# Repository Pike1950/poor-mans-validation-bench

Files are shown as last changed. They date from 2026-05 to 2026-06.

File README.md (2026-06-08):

# Poor Man's Validation Bench

A modular SCPI instrument platform that mirrors NI PXIe rack-and-module test architecture at hobbyist budget. A Raspberry Pi 5 acts as the orchestration head running PyVISA, pytest, InfluxDB, and Grafana. Hot-swappable instrument modules attach over USB or Ethernet and present as independent SCPI-addressable instruments. Every module is also exposed through a Model Context Protocol (MCP) tool surface for agent-orchestrated bench sessions.

## Documentation

### Canonical reference

- **[System Design Document](https://pike1950.github.io/poor-mans-validation-bench/docs/system-design/System_Design_Document.html)** — full v1.0 SDD covering architecture, module catalog, specifications, software stack, build phases, and verification strategy. Rendered via GitHub Pages.

### Orchestration layer

- **[Phase 0 Orchestration Layer Setup](https://pike1950.github.io/poor-mans-validation-bench/docs/setup/Phase_0_Orchestration_Setup.html)** — architecture overview of the two-plane VISA/SCPI + MCP software stack (PyVISA, pytest, InfluxDB 2.x, Grafana, Jinja2 reports, MCP gateway), the `pmvb` Python package layout, and the step-by-step bring-up cookbook from a blank SD card through the Phase 0 verification milestone. Covers Pi 5 OS install, NVMe boot migration, Python project bootstrap, InfluxDB + Grafana install with token management, Pico SDK + USB-TMC stub firmware, udev rules, hot-plug verification, and the closing end-to-end pytest.

### Chassis design

- **[Chassis Architecture and Power Distribution](https://pike1950.github.io/poor-mans-validation-bench/docs/chassis/Chassis_Architecture_and_Power_Distribution.html)** — open-frame acrylic blade-style chassis (laser-cut from SendCutSend, 435 × 238 × 92 mm) housing the Silverstone TX300 PSU as an analog-rail backbone, the GeeekPi D-1188 ATX breakout, the Sabrent HB-BU10 USB 3.0 hub, and 14 module slots at 22.5 mm pitch. Covers mechanical architecture, electrical architecture (4-rail back-wall harness with Phoenix MC 1,5/4 module interconnect, per-rail fuse panel, banana-jack diagnostic test points), USB-TMC backplane, BOM with Digi-Key and Amazon cross-references, bring-up procedure, and safety protocols.

### Per-module design

- **[Module 1E: Function Generator / AWG](https://pike1950.github.io/poor-mans-validation-bench/docs/modules/Module_1E_Design_Document.html)** — theory of operation, functional block diagram, Pico-to-DAC-to-op-amp pin assignments, four sample applications (single-tone sine, swept-sine THD, multitone IMD, white noise), calibration procedure, bring-up checklist, and BOM with Mouser and Digi-Key cross-references.

## Module Catalog

Every module is built on a Pico 2 W bridge presenting as a USB-TMC instrument over the chassis powered USB hub. Tier 2 modules add a Tang Primer 25K FPGA the Pico masters over SPI. Tier 3 modules (deferred) replace the Tang Primer 25K with a larger FPGA platform and add a Pi Zero 2 W streaming sidecar for sustained-capture data paths beyond USB-TMC's 12 Mbps.

| ID | Tier | Function | Status |
|----|---|---|---|
| 1A | 1 | Digital I/O Controller | Planned (v1.0) |
| 1B | 1 | Voltage Measurement Unit | Planned (v1.0) |
| 1C | 1 | USB HID Protocol Analyzer | Planned (v1.0) |
| 1D | 1 | Source-Measure Unit Lite | Planned (v1.0) |
| 1E | 1 | Function Generator / AWG | Planned (v1.0) |
| 1F | 1 | High-Voltage Differential Probe | Planned (v1.1) |
| 1G | 1 | IR Capture and Transmit | Planned (v1.1) |
| 1H | 1 | Multi-Function DMM | Planned (v1.0) |
| 2A | 2 | Logic Analyzer | Planned (v1.0) |
| 2B | 2 | Protocol Exerciser / Analyzer | Planned (v1.0) |
| 2C | 2 | Frequency Counter | Planned (v1.0) |
| 2D | 2 | Ethernet MAC and Network Analyzer | Planned (v1.0) |
| 2E | 2 | Mixed-Signal Digitizer / Oscilloscope | Planned (v1.0) |
| 3A | 3 | USB 2.0 Protocol Analyzer | Deferred |
| 3B | 3 | HDMI Sideband Analyzer | Deferred |
| 3C | 3 | USB-C CC Analyzer | Deferred |

## Architecture at a Glance

Two control planes per module: a VISA/SCPI plane for headless test sequencing (pytest, vendor-portable, deterministic) and an MCP plane that exposes the same instrument surface as LLM-callable tools for agent-orchestrated bench sessions. Both planes consume the same per-module YAML command schema; firmware parsers and PyVISA-sim simulation backends are generated mechanically from the YAML.

Every module is built around a Pico 2 W running the SCPI parser in bare-metal C and presenting as a USB-TMC instrument. Tier 1 modules add an analog or digital front end appropriate to the function. Tier 2 modules add a Sipeed Tang Primer 25K FPGA where the instrument logic lives; the Pico bridges to the FPGA over SPI at approximately 30 MHz. Tier 3 modules (deferred) replace the Tang Primer 25K with a larger FPGA (Tang Mega 138K Pro or Alinx AX7325B) for high-speed interface analysis and add a Pi Zero 2 W streaming sidecar for sustained-capture data paths beyond USB-TMC's 12 Mbps. Persistent state for Tier 1 and Tier 2 modules lives in the Pico's onboard 4 MB flash; bench-level admin services run on the Pi 5 orchestration head.

See section 4 of the [System Design Document](https://pike1950.github.io/poor-mans-validation-bench/docs/system-design/System_Design_Document.html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) for the full architecture diagram.

## Status

Phase-by-phase build progress. Top-level structure mirrors [SDD section 13](https://pike1950.github.io/poor-mans-validation-bench/docs/system-design/System_Design_Document.html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). Items are sized for single-session work units. Per-module work follows a standard template: design doc → BOM → PCB → assembly → firmware → bring-up → calibration → service. Status legend: `[ ]` not started · `[~]` in progress · `[x]` complete · `[!]` blocked.

### Phase 0 — Orchestration + Chassis Power

Phase 0 brings up the orchestration head and chassis power subsystem to the point where a simulator-backed end-to-end test exercises the full SCPI → InfluxDB → Grafana → report pipeline.

**Architectural decisions (settled)**

- [x] System Design Document v1.0 published
- [x] Chassis LAN switch dropped from v1.0 baseline (moved to Phase 4)
- [x] TFX (TX300) is analog-rail backbone, not chassis-wide power
- [x] Pi 5, Sabrent hub, Picos run from independent external supplies
- [x] Pi 5 ↔ USB hub link is USB 3.0
- [x] Chassis envelope: 435 × 238 × 92 mm in 3 mm cast acrylic from SendCutSend
- [x] Chassis topology v1.0: open-frame card cage (4 panels: floor, bottom groove plate, top groove plate, ceiling) held by 4 M3 corner standoffs. Side walls + rear wall + front panel deferred to v1.1 pending thermal review.
- [x] Module form factor v10 (JLCPCB-FDM-compliant): 16.3 × 125 × 86 mm outer, 6 mm shells, 2 mm right wall, 1.5 × 3 × 125 mm rail lips at top-right and bottom-right edges, 14.3 × 125 × 68 mm cavity
- [x] Chassis groove: 2 mm wide × 3 mm deep × 125 mm long, at 22.5 mm slot pitch starting at x = 100 mm (leftmost 10 mm reserved for M3 corner standoff clearance + 86 mm TX300 zone + 4 mm air gap). 0.5 mm sliding clearance.
- [x] Module fabrication path: FDM PLA via US service for prototype (Baysinger's AM); FDM PETG via JLCPCB for the production batch of 14 once v10 fit validates
- [x] GeeekPi D-1188 mounted to chassis ceiling via 4× M2.5 × 5 mm standoffs (rotated 90° so terminal blocks face chassis front, status LEDs face rear). Mounting holes at (110.1, 161.6), (162.9, 161.6), (110.1, 225.4), (162.9, 225.4) on both ceiling and top groove plate
- [x] Sabrent HB-BU10 actual dimensions verified: 144.8 × 48.3 × 23.9 mm. Positioned at X = 102.6..247.4, Y = 175.4..223.7, Z = 6..29.9 (rear-center on chassis floor)
- [x] Back-wall harness taps: Wago 221-413 lever-nut connectors for v1.0 (one per rail per module). Custom 4-rail distribution PCB deferred to v1.1+ once layout is verified
- [x] Module Design Document Schema authored (local tooling)

**Chassis sourcing**

Detailed rationale (gauge sizing, standoff stacking, fastener stack-up, Wago vs PCB tradeoff) lives in the [chassis architecture doc](https://pike1950.github.io/poor-mans-validation-bench/docs/chassis/Chassis_Architecture_and_Power_Distribution.html). This tracker is part + source + qty + price only.

- [x] GeeekPi D-1188 ATX breakout — Amazon B08MC389FQ ($13)
- [x] Sabrent HB-BU10 USB 3.0 hub — Amazon B0797NZFYP ($47)
- [x] Phoenix MC 1,5/4 connector pairs ×2 — Digi-Key 277-1208-ND + 277-1163-ND ($11.40)
- [x] Eaton BK/HTB-22M-R fuse holders ×3 + Bel BK1/GMC cartridges ×2 each (5 A / 3 A / 500 mA, in-service + spare) — Digi-Key 283-3041-ND + 283-BK1/GMC-{5,3,500}-R-ND ($28.79)
- Pomona 3760 banana jacks ×4 — *deferred to v1.1 diagnostic strip*; open-frame chassis gives direct access to fuse-panel terminals for DMM spot-checks
- [x] 12 AWG silicone wire kit, 6 colors × 5 ft — Fermerry, Amazon B089CJ65SC ($20.29)
- [x] 14 AWG silicone wire kit, 6 colors × 10 ft — Fermerry, Amazon ($20.96)
- [x] M3 standoff/screw/nut kit, 320 pc — Csdtylh, Amazon B06Y5TJXY1 ($14.98)
- [x] M2.5 standoff/screw/nut kit, 160 pc — HVAZI, Amazon B01L06CUJG ($11.99)
- [x] Blue 243 threadlocker, 50 mL — ESKONKE, Amazon B0CHM5QS3N ($9.99)
- [x] Wago 221-413 lever-nuts ×10 — Digi-Key 2946-221-413-ND ($6.45)
- [~] USB-A to Micro-USB cables (module Pico to hub) — 11 of 14 on hand (5 prior + 6 from Amazon, $10.81). 11 covers Phase 0 + early Phase 1; 3 more needed for full 14-slot population
- [x] 22 AWG signal wire on hand
- [x] LEDs for diagnostic strip on hand
- [x] Heat-shrink tubing on hand (ElectroBits)
- [x] Silverstone SST-TX300 TFX PSU — Amazon ($99.99), on hand

**Chassis fabrication + assembly**

Prototype-first iterative build: order chassis acrylic + one PLA module, slide-test the v10 lip-and-groove fit, then commit the JLCPCB batch order for 13 more modules and proceed with full assembly + harness. Module 1E is the first module to fully populate; Pi 5 software-stack work runs in parallel.

*Design tooling and fabrication files (complete)*

- [x] Tinkercad reference design + parametric DXF/STL generator (`tools/fabrication/generate_prototype_v10.py`, ezdxf + trimesh) producing `panel_solid_plate.dxf`, `panel_groove_plate.dxf`, `module_body_v10.stl`, `chassis_v10.stl`, `chassis_v10_assembled.stl`, `chassis_assembly_exploded.{stl,png}`

*Orders placed*

- [x] v10 prototype module — Baysinger's AM, $24.77, ETA May 14-19
- [x] Chassis acrylic — SendCutSend, $142.57
- [x] Amazon order (hardware + wire + threadlocker), $78.21, ETA May 12
- [x] Digi-Key order (Phoenix + fuse panel + Wago), $62.19, placed 2026-05-10

*Receive + slide-fit validation*

- [x] Receive prototype module + chassis panels (all parts arrived 2026-05-12 onward)
- [x] Slide-fit test: module blade engages the lip-and-groove cleanly at every slot, 0.5 mm clearance good (verified 2026-05-12; droop is a separate panel-stiffness issue, see build notes)
- [ ] Order JLCPCB batch of 14 module bodies in PETG (~$84) — unblocked by slide-fit pass

*Frame + component install*

- [x] Build 4× M3 corner standoff stacks
- [x] Acrylic frame stack assembly (standoffs + bonded panels)
- [x] Install TX300 PSU
- [~] Install GeeekPi (ceiling mount) + Sabrent hub — deferred a while; GeeekPi mount pending hole-pattern fix (see build notes)
- [ ] Run 24-pin ATX cable TX300 → GeeekPi
- [ ] Build per-rail fuse panel + wire to GeeekPi outputs

*Harness + module shakedown*

- [ ] Build 4-wire back-wall harness (~330 mm × 14 AWG, color-coded). Tap slot 1 only for Module 1E shakedown via 4× Wago 221-413 (one per rail)
- [ ] Single-slot shakedown: install Module 1E, verify Phoenix mate + USB cable run + harness tap
- [ ] On pass: add Wago taps at remaining 13 slots (52 more Wagos, total 56)
- [ ] Install front-panel diagnostic strip (×4 banana jacks + ×3 LED indicators) on a small acrylic strip on the chassis floor

*Deferred to v1.1:* chassis side walls, rear wall, front panel, ventilation geometry, module-specific faceplate cutouts, custom 4-rail distribution PCB. Walls + vents must be co-designed because closing the chassis re-introduces TX300 cooling constraints.

*v1.0 prototype build notes (iteration 1, 2026-05-12)*

- **GeeekPi mounting holes mis-sized.** Acrylic was cut for a ~52.8 × 63.8 mm M2.5 pattern; the real GeeekPi is 87.4 × 68.4 mm with a 58.6 × 78.1 mm hole pattern (PCB was modeled ~17 mm too short, ~10 mm too narrow). *Resolution:* hand-drill correct holes on the prototype panel, or VHB-tape the GeeekPi (mount is non-structural). *Deferred:* the on-disk `generate_prototype_v10.py` is a stale 6-panel version with no M3/M2.5 hole logic — the generator that produced the real `panel_solid_plate.dxf` / `panel_groove_plate.dxf` was never committed. Fixing the GeeekPi pattern needs a full generator reconstruction (with a placement re-derivation, since the larger GeeekPi would otherwise crowd the chassis back edge), to be done before any v1.1 panel re-order.
- **Long acrylic panels droop at mid-span.** 435 mm of unsupported 3 mm cast acrylic sags under self-weight. *Resolution (applied):* bonded ceiling + top groove plate into a 6 mm laminate with acrylic cement — large improvement, slight residual droop accepted for the prototype. v1.1 side walls will provide long-edge support and largely eliminate it.
- **Harness routing tighter than CAD suggested.** Physical wire bend radii make the Wago back-wall harness cramped. *Direction:* custom 4-rail distribution PCB (v1.1 §9.3) is now the leading power-backplane approach, gated on the Module 1E PCB design locking the module-to-backplane connector interface spec.

**Chassis bring-up**

- [ ] Visual + continuity tests, mains disconnected
- [ ] Mains-only AC test (TX300 in standby)
- [ ] DC at no load (rail voltages at fuse outputs, front-panel LEDs, banana-jack test points all verified)
- [ ] Back-wall harness rail voltages verified at every Phoenix plug position

**Pi 5 hardware**

- [x] Pi 5 16 GB price verified at Microcenter ($305)
- [x] Pi 5 16 GB + 27 W USB-C charger + active cooler on hand
- [x] microSD (32 GB) + M.2 HAT+ + 512 GB NVMe SSD on hand
- [x] Pi 5 assembled (heatsink + M.2 HAT+ + NVMe)

**Pi 5 software stack**

- [x] Raspberry Pi OS Full 64-bit install + headless config (Wi-Fi, SSH key-only auth, Raspberry Pi Connect enabled)
- [x] Boot migration to NVMe SSD (NVMe-first via EEPROM `BOOT_ORDER`, SD card retained as fallback)
- [x] Bootstrap Python project (`pyproject.toml` + `pmvb/` package + `.venv` on Pi)
- [x] InfluxDB 2.x install + service + `pmvb` org + `measurements` bucket + SDD §10.2 tag schema (Flux)
- [x] Grafana 10+ install + InfluxDB datasource (Pi 5 reference build runs Grafana 13)
- [x] Jinja2 + Matplotlib report template skeleton (`pmvb/reports/`)
- [x] MCP gateway scaffolding (`pmvb/mcp_gateway/server.py`, FastMCP + `anthropic` SDK)
- [x] PyVISA-sim placeholder schema (`sim/placeholder/responses.yaml`) for Phase 0 sim path
- [x] pytest fixtures (`pmvb/fixtures.py`, `run_id` / `dut` / `record`) per SDD §10.3
- [x] InfluxDB I/O helpers (`pmvb/influx.py`) enforcing the SDD §10.2 tag taxonomy

**Pico firmware bring-up (hot-plug verification)**

Pulled forward from Phase 1: a throwaway probe firmware on every Pico so the Phase 0 verification can exercise the real USB-TMC path, not just the simulator. The stub is not the eventual per-module SCPI firmware; it just enumerates and answers `*IDN?` so we can prove the hot-plug-by-serial architecture works.

- [x] Pico SDK + TinyUSB cross-compile environment on the Pi 5 (`arm-none-eabi-gcc`, `pico-sdk` at `/opt/pico-sdk`, `PICO_SDK_PATH` set; `hello_usb` cross-compile verified)
- [x] Minimal USB-TMC stub firmware at `firmware/pmvb_usbtmc_stub/`: responds to `*IDN?` with chip-ID-derived serial number
- [x] Flash all 5 Picos with the stub `.uf2`
- [x] udev rules: plugdev access to USB-TMC class devices + stable `/dev/usbtmc-by-serial/{chip_id}` symlinks + suppress BOOTSEL automount (`tools/udev/99-pmvb-usbtmc.rules`)
- [x] Hot-plug verification: same Pico across different Sabrent hub ports preserves serial-based identity in pyvisa-py enumeration

**Phase 0 verification milestone (per SDD §13.1)**

- [x] Pi 5 boots from NVMe, reaches bench network, Sabrent hub enumerates as USB 3.0
- [x] End-to-end pytest: real Pico over pyvisa-py USB-TMC + pyvisa-sim placeholder, both write to InfluxDB tagged appropriately, Grafana panel renders both, Jinja2 report queries InfluxDB and outputs HTML+PDF referencing both records (verified 2026-05-12 by `tests/test_phase0_e2e.py::test_phase0_milestone`)
- [x] Hot-plug-by-serial verified across at least 3 port-swap permutations (verified 2026-05-12 by `tools/hot_plug_verify.py` across 4 distinct hub arrangements)

**Phase 0 documentation**

- [x] Chassis Architecture and Power Distribution doc
- [x] SDD §11.5 Power Architecture
- [x] Phase 0 Orchestration Layer Setup doc (rewritten with architecture + bring-up sections, replaces the stale 2024-era version) at `docs/setup/Phase_0_Orchestration_Setup.{md,html}`

### Phase 1 — Tier 1 Core (1A, 1B, 1D, 1E)

Four foundational Tier 1 modules using the chassis from Phase 0. Each follows the per-module template.

- **Module 1A — Digital I/O Controller**:
  - [ ] Design doc
  - [ ] Block diagram
  - [ ] BOM verified at Digi-Key + Mouser
  - [ ] BOM ordered
  - [ ] PCB design (KiCad: Pico + level shifters + I/O protection)
  - [ ] PCB fab + assembly
  - [ ] Firmware (SCPI YAML for read/write/pulse, configurable per-pin direction)
  - [ ] Bring-up
  - [ ] Module enters service
- **Module 1B — Voltage Measurement Unit** (front-end: ADS1115 + instrumentation amp on ±12 V rails):
  - [ ] Design doc
  - [ ] Functional figures (system context + front-end schematic)
  - [ ] BOM verified at Digi-Key + Mouser
  - [ ] BOM ordered
  - [ ] PCB design (KiCad: ADS1115 + instrumentation amp + ±12 V analog supplies)
  - [ ] PCB fab + assembly
  - [ ] Firmware (SCPI YAML for voltage measurement, range selection, averaging)
  - [ ] Bring-up
  - [ ] Calibration (offset, gain across ranges)
  - [ ] Module enters service
- **Module 1D — Source-Measure Unit Lite** (front-end: DAC + force/sense op-amp loop on ±12 V rails):
  - [ ] Design doc
  - [ ] Functional figures
  - [ ] BOM verified at Digi-Key + Mouser
  - [ ] BOM ordered
  - [ ] PCB design (KiCad: 12-bit DAC + force/sense op-amp loop + ±12 V analog supplies)
  - [ ] PCB fab + assembly
  - [ ] Firmware (SCPI YAML for V-source/I-measure, sweep, IV-curve)
  - [ ] Bring-up
  - [ ] Calibration (V-source, I-measure across ranges)
  - [ ] Module enters service
- **Module 1E — Function Generator / AWG**:
  - [x] Design doc v1.1
  - [x] Functional figures (system context, AD9742 datasheet embed, typical app)
  - [x] BOM verified at Digi-Key + Microcenter ($53)
  - [ ] BOM ordered
  - [~] PCB design (KiCad: AD9742 + AD8056 + reconstruction filter + 3× Coto 9007 reeds + Pico): design package + parts checklist + KiCad build guide in `hardware/modules/1E/`; KiCad schematic capture and layout pending
  - [ ] PCB fab + assembly
  - [ ] Firmware (SCPI YAML for sine/square/triangle/ramp/noise/multitone/ARB/sweep + PIO+DMA streaming at 30-50 MSPS)
  - [ ] Bring-up checklist (visual → power → DC → swept sine → THD → spectral purity → impedance switch)
  - [ ] Calibration (DC offset, gain, frequency, filter passband flatness)
  - [ ] Module enters service

**Phase 1 system tests**

- [ ] Audio analyzer recipe partial (1E stimulus + 1B integration; full recipe blocked on Module 2E in Phase 2.5)
- [ ] Phase 1 verification milestone per SDD §13.2

### Phase 1.5 — HID Module + Tier 2 Bridge Bring-Up

- **Module 1C — USB HID Protocol Analyzer** (architecture: dual-Pico bridge):
  - [ ] Design doc
  - [ ] Block diagram
  - [ ] BOM verified at Digi-Key + Mouser
  - [ ] BOM ordered
  - [ ] PCB design (KiCad: dual Pico, USB-host on capture Pico, USB-device on target side)
  - [ ] PCB fab + assembly
  - [ ] Firmware (SCPI YAML for HID enumeration, capture, parse)
  - [ ] Bring-up
  - [ ] Module enters service
- **Tier 2 bridge stack (Tang Primer 25K + Pico)**:
  - [ ] Bridge module PCB design
  - [ ] PCB fab + assembly
  - [ ] Tang Primer placeholder HDL (verify Pico ↔ FPGA SPI link)
  - [ ] Pico bridge firmware (SCPI YAML pass-through skeleton)
  - [ ] `*IDN?` through bridge returns placeholder string
  - [ ] Phase 1.5 verification milestone per SDD §13.3

### Phase 1.7 — Module 1H DMM

- **Module 1H — Multi-Function DMM** (front-end: ADS1256 24-bit ADC + relay-switched multi-range network on ±12 V rails):
  - [ ] Design doc
  - [ ] Functional figures
  - [ ] BOM verified at Digi-Key + Mouser
  - [ ] BOM ordered
  - [ ] PCB design (KiCad: ADS1256 + relay-switched multi-range network + ±12 V analog supplies)
  - [ ] PCB fab + assembly
  - [ ] Firmware (SCPI YAML for DC V/I/R, AC V, continuity, frequency)
  - [ ] Bring-up
  - [ ] Per-range calibration
  - [ ] Module enters service
- [ ] Phase 1.7 verification milestone per SDD §13.3.5: 9 V battery, 1 kΩ ±1 % reference, 1 kHz sine from 1E all read within stated module accuracy

### Phase 2 — Tier 2 Core (2A, 2B, 2C, 2D)

Four primary Tier 2 modules using the bridge stack from Phase 1.5. Each adds Tang Primer 25K HDL alongside the Pico bridge firmware (synthesis on shared FPGA per project rule).

- **Module 2A — Logic Analyzer**:
  - [ ] Design doc
  - [ ] Functional figures
  - [ ] BOM verified at Digi-Key + Mouser
  - [ ] BOM ordered
  - [ ] PCB design (KiCad: probe inputs + level shifters + Tang Primer 25K)
  - [ ] PCB fab + assembly
  - [ ] HDL (sample capture FSM + sample buffer + SPI register interface)
  - [ ] Pico bridge firmware (SCPI YAML for capture/trigger/decode)
  - [ ] Bring-up
  - [ ] Module enters service
- **Module 2B — Protocol Exerciser / Analyzer**:
  - [ ] Design doc
  - [ ] Functional figures
  - [ ] BOM verified at Digi-Key + Mouser
  - [ ] BOM ordered
  - [ ] PCB design (KiCad: protocol I/O + level shifters + Tang Primer 25K)
  - [ ] PCB fab + assembly
  - [ ] HDL (protocol bit-banger + decoder)
  - [ ] Pico bridge firmware
  - [ ] Bring-up
  - [ ] Module enters service
- **Module 2C — Frequency Counter**:
  - [ ] Design doc
  - [ ] Functional figures
  - [ ] BOM verified at Digi-Key + Mouser
  - [ ] BOM ordered
  - [ ] PCB design (KiCad: input conditioning + TCXO + Tang Primer 25K)
  - [ ] PCB fab + assembly
  - [ ] HDL (count state machine, gate timing)
  - [ ] Pico bridge firmware
  - [ ] Bring-up
  - [ ] TCXO calibration via GPSDO
  - [ ] Module enters service
- **Module 2D — Ethernet MAC and Network Analyzer**:
  - [ ] Design doc
  - [ ] Functional figures
  - [ ] BOM verified at Digi-Key + Mouser
  - [ ] BOM ordered
  - [ ] PCB design (KiCad: PHY + magnetics + Tang Primer 25K)
  - [ ] PCB fab + assembly
  - [ ] HDL (MAC frame analyzer + buffer)
  - [ ] Pico bridge firmware
  - [ ] Bring-up
  - [ ] Module enters service

**Phase 2 verification milestone (SDD §13.4)**

- [ ] All Tier 2 modules enumerate and respond to `*IDN?`
- [ ] Trigger bus tested (2A capturing on 1E sync edge)
- [ ] InfluxDB receives capture records from each Tier 2 module

### Phase 2.5 — Module 2E Digitizer

- **Module 2E — Mixed-Signal Digitizer / Oscilloscope** (front-end: high-speed multi-channel ADC + analog conditioning on ±5 V or ±12 V rails):
  - [ ] Design doc
  - [ ] Functional figures
  - [ ] BOM verified at Digi-Key + Mouser
  - [ ] BOM ordered
  - [ ] PCB design (KiCad: high-speed ADC + analog conditioning + Tang Primer 25K)
  - [ ] PCB fab + assembly
  - [ ] HDL (ADC capture + trigger logic + sample buffer)
  - [ ] Pico bridge firmware (SCPI YAML for capture/trigger/FFT readback)
  - [ ] Bring-up
  - [ ] Calibration (offset, gain, bandwidth)
  - [ ] Module enters service

**Phase 2.5 system tests (SDD §13.5)**

- [ ] Audio analyzer recipe full: 1E sweep stimulus + 2E capture + Pi 5 FFT (THD/SFDR/IMD) → InfluxDB → Grafana → report
- [ ] Firestick boot capture: 5 V rail transient via 2E

### Phase 3 — v1.1 Tier 1 (1F, 1G)

- **Module 1F — High-Voltage Differential Probe** (front-end: AD8421 instrumentation amp + 100:1 attenuator on ±12 V rails; v1.2 fully-isolated variant noted as future enhancement):
  - [ ] Design doc
  - [ ] HV safety review
  - [ ] Functional figures
  - [ ] BOM verified at Digi-Key + Mouser
  - [ ] BOM ordered
  - [ ] PCB design (KiCad: AD8421 + 100:1 attenuator + ±12 V analog supplies)
  - [ ] PCB fab + assembly
  - [ ] Firmware (SCPI YAML for HV differential measurement)
  - [ ] Bring-up (low-V validation → ramp to ±300 V)
  - [ ] Calibration
  - [ ] Module enters service
- **Module 1G — IR Capture and Transmit**:
  - [ ] Design doc
  - [ ] Block diagram
  - [ ] BOM verified at Digi-Key + Mouser
  - [ ] BOM ordered
  - [ ] PCB design (KiCad: IR LED + photodiode + Pico)
  - [ ] PCB fab + assembly
  - [ ] Firmware (SCPI YAML, NEC / RC5 / Sony SIRC encode/decode)
  - [ ] Bring-up
  - [ ] Module enters service

**Phase 3 verification milestone**

- [ ] Full v1.0 + v1.1 catalog enumerates correctly
- [ ] Cross-module integration recipe (e.g., 1F captures HV transient triggered by 1E AWG sync)

### Phase 4 — Tier 3 (Deferred)

Gated on a future FPGA-upgrade decision. Not on the v1.0 + v1.1 critical path.

- [ ] FPGA selection: Tang Mega 138K Pro vs AX7325B
- [ ] Pi Zero 2 W streaming sidecar architecture
- [ ] Chassis LAN switch re-evaluation
- [ ] Tier 3 modules: 3A (USB 2.0 protocol analyzer), 3B (HDMI sideband), 3C (USB-C CC analyzer)

### Cross-Cutting

Continuous work that spans phases.

**Documentation**

- [x] System Design Document v1.0
- [x] Chassis Architecture and Power Distribution doc
- [x] Module 1E Design Document v1.1
- [x] PMVB figure legend (Figure 4-0)
- [x] Figure 4-1 (top-level system block, TikZ)
- [x] Chassis block diagram (TikZ, with analog/digital module split)
- [x] Module 1E figures (functional block, AD9742 datasheet embed, typical app)
- [x] Module Design Document Schema (local tooling, gitignored)
- [ ] Per-module design docs for 1A, 1B, 1C, 1D, 1F, 1G, 1H, 2A-2E (authored as each module enters Phase 1+)

**Tooling**

- [x] TikZ figure pipeline with `pmvb-figures.sty` (FMCW dark theme)
- [x] Pandoc-rendered HTML for SDD and chassis arch doc, served via GitHub Pages
- [x] Parametric DXF + STL generator for chassis fabrication (`tools/fabrication/`)
- [~] PCB toolchain in `hardware/`: per-module design package + Component Search Engine parts checklist + KiCad build guide + shared board-outline DXF generator. Schematic capture and layout in KiCad GUI; 5 custom parts per module fetched via CSE.
- [x] Pico SDK build environment (CMake + arm-none-eabi-gcc) for firmware development (SDK 2.2.0 at `/opt/pico-sdk`; `PICO_BOARD=pico2_w` reference)
- [ ] Tang Primer 25K HDL toolchain (Gowin EDA + open-source flow as backup)

**Test infrastructure**

- [x] pytest harness with parametric fixtures keyed off module catalog (Phase 0 scaffolding in `pmvb/fixtures.py`; per-module parametrization added as modules come online)
- [ ] PyVISA-sim YAML schemas (one per module, generated mechanically from `modules/<id>/commands.yaml`; Phase 0 placeholder at `sim/placeholder/responses.yaml`)
- [x] InfluxDB tag schema spec (instrument, channel, dut, run_id, measurement_type) enforced in `pmvb/influx.py`
- [x] Jinja2 + Matplotlib report templates (`pmvb/reports/templates/basic_report.html.j2`; specialized templates added per-recipe)
- [x] MCP gateway scaffolding (`pmvb/mcp_gateway/server.py`, FastMCP + Anthropic Python SDK; per-module tool surface added as modules come online)

**Workflow**

- [x] GitHub repository published at github.com/Pike1950/poor-mans-validation-bench
- [x] GitHub Pages deployment for SDD + chassis arch doc
- [ ] Per-module branch + PR workflow once Phase 1 module work begins
- [ ] CI for SCPI YAML schema validation + Pandoc HTML re-rendering on doc changes

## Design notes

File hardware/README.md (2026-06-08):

# PMVB Hardware

PCB design workspace for Poor Man's Validation Bench instrument modules.

Each module gets its own folder under `modules/<id>/`, holding the engineering
design package, a parts-fetch checklist for the custom parts that need
Component Search Engine downloads, a KiCad project build guide, and the KiCad
project files themselves (created in KiCad once the prep documents are read).

Schematic capture and board layout happen in KiCad's GUI. The Python in this
tree is small and one-purpose: it generates the shared module board outline
DXF that every module imports onto Edge.Cuts.

## Layout

```
hardware/
  README.md                       this file
  library/
    module_pcb_outline.py         generator for the shared module PCB outline
    module_pcb_outline.dxf        generated; import onto KiCad Edge.Cuts
    module_pcb_floorplan.png      annotated placement reference
  modules/
    1E/
      Module_1E_PCB_Design_Package.md   engineering decisions + design spec
      Module_1E_Parts_Checklist.md      Component Search Engine fetch list
      Module_1E_KiCad_Build_Guide.md    project setup + sheet specification
      kicad/                            KiCad project (created during build)
```

## Workflow for a module

1. **Read** the per-module design package. D1 through D6 (for 1E) are the
   engineering decisions baked into the spec. Push back on any you disagree
   with before they get into the schematic.
2. **Fetch** the custom symbols, footprints, and 3D models per the parts
   checklist. Source is Component Search Engine. Drop the files into the
   project library at `modules/<id>/kicad/lib/PMVB_<id>/`.
3. **Build the KiCad project** per the build guide: new project, title block,
   library import, board-outline DXF onto Edge.Cuts, netclasses configured,
   five hierarchical sheets scaffolded.
4. **Capture** each sub-sheet against the per-sheet contract in section 7 of
   the build guide. ERC, annotate, update PCB.
5. **Place and route** against the floorplan and stackup in the design
   package. DRC, run the verification checklist in the build guide section 9.

## Dependencies

Only the shared board-outline generator runs as code:

```
pip install ezdxf matplotlib
```

KiCad 8 or 9 is the actual design environment. Component Search Engine is a
web tool (no install).

## Status

Module 1E (Function Generator / AWG) is the first board through this workflow
and establishes the shared 120 x 62 mm board outline and the module-to-
backplane Phoenix interface spec that the other 13 modules inherit.

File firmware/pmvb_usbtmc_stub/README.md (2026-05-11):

# PMVB USB-TMC Stub Firmware

Phase 0 throwaway probe firmware for the Pico 2 W. Makes a bare Pico enumerate as a USB-TMC instrument with a chip-ID-derived serial number, so the bench can validate the [SDD §10.1 hot-plug-by-serial architecture](../../docs/system-design/System_Design_Document.html) without any module front-end attached.

This firmware is **not** the per-module SCPI parser. Each instrument module ships its own firmware in its own Phase, generated mechanically from the module's `commands.yaml` schema.

## What it does

Enumerates as a USB-TMC class device (USB488 subclass) with:

- **VID / PID:** `0xCafe` / `0x4001` (TinyUSB community-reserved test VID; PMVB-specific PID)
- **Manufacturer string:** `PMVB`
- **Product string:** `PMVB Pico 2 W USB-TMC Stub`
- **iSerialNumber:** the Pico 2 W's unique 64-bit chip ID, formatted as 16 hex chars

Supported SCPI commands:

| Command | Behavior |
|---|---|
| `*IDN?` | Returns `PMVB,Pico 2 W,<chip_id_hex>,1.0.0\n` |
| `*RST` | Silent acknowledgment |
| `*CLS` | Silent acknowledgment (clear status) |
| `*OPC?` | Returns `1\n` |
| `:SYST:BOOTSEL` | PMVB extension: reboots into BOOTSEL mode for hot re-flashing without the physical button |

Anything else is silently dropped.

## Build

Requires the Pico SDK installed at `/opt/pico-sdk` with `PICO_SDK_PATH` exported, and the arm-none-eabi toolchain (`gcc-arm-none-eabi`, `libnewlib-arm-none-eabi`, `libstdc++-arm-none-eabi-newlib`). See [`docs/setup/Phase_0_Orchestration_Setup.html`](../../docs/setup/Phase_0_Orchestration_Setup.html) section G.

From the repo root on the orchestration host:

```bash
cd firmware/pmvb_usbtmc_stub
mkdir -p build && cd build
cmake .. -G Ninja -DPICO_BOARD=pico2_w
ninja
```

Output: `build/pmvb_usbtmc_stub.uf2` (the firmware image to drag-drop onto each Pico in BOOTSEL mode).

## Flash

1. Hold the BOOTSEL button on the Pico and plug it into the chassis hub (or apply power while holding BOOTSEL).
2. The Pico enumerates as a mass-storage volume named `RP2350` at e.g. `/media/<user>/RP2350`.
3. Copy `pmvb_usbtmc_stub.uf2` onto that volume:
   ```bash
   cp build/pmvb_usbtmc_stub.uf2 /media/<user>/RP2350/
   ```
4. The Pico auto-reboots and re-enumerates as a USB-TMC instrument.

After the first flash, subsequent re-flashes can use the `:SYST:BOOTSEL` SCPI command instead of the physical button:

```python
import pyvisa
rm = pyvisa.ResourceManager('@py')
inst = rm.open_resource('USB::0xCafe::0x4001::<chip_id>::INSTR')
inst.write(':SYST:BOOTSEL')   # Pico reboots into BOOTSEL; copy new .uf2; done
```

## Verify enumeration

After flashing, on the orchestration host:

```bash
lsusb -v 2>/dev/null | grep -A2 "iSerial"
```

Each flashed Pico should show its own 16-hex-char serial. PyVISA resource discovery will key off this field; hot-plugging a Pico across different chassis hub ports preserves its logical identity.

## Files

- `CMakeLists.txt` - Pico SDK CMake build
- `tusb_config.h` - TinyUSB configuration (USB-TMC + USB488 subclass enabled)
- `usb_descriptors.c` - Device, configuration, and string descriptors
- `usbtmc_handlers.c` - USB-TMC class callbacks + SCPI command dispatch
- `main.c` - TinyUSB init and main loop

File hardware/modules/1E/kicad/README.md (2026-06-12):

# Module 1E - KiCad project

This folder holds the KiCad project for Module 1E (Function Generator / AWG).
The KiCad files themselves (`module_1e.kicad_pro` / `.kicad_sch` / `.kicad_pcb`
and the five sub-sheets) are created and edited in the KiCad GUI, not authored
by hand. The step-by-step is `../Module_1E_KiCad_Build_Guide.md`.

## Build order

1. Read `../Module_1E_PCB_Design_Package.md` (engineering decisions D1-D7).
2. Fetch the five custom parts per `../Module_1E_Parts_Checklist.md` into
   `lib/PMVB_1E/` (`symbols/`, `footprints.pretty/`, `3dmodels/`).
3. Follow `../Module_1E_KiCad_Build_Guide.md`: File > New Project here as
   `module_1e`; set the title block; add the project library; import the shared
   outline `hardware/library/module_pcb_outline.dxf` onto Edge.Cuts; set
   netclasses; place the five hierarchical sheets; capture per build-guide
   section 7.

## Folder layout (this dir, after KiCad New Project)

    kicad/
      module_1e.kicad_pro / .kicad_sch / .kicad_pcb   <- KiCad creates these
      Pico / DAC / OpAmp / OutputSwitch / Trigger .kicad_sch   <- 5 sub-sheets
      lib/PMVB_1E/
        symbols/            *.kicad_sym  (from CSE)
        footprints.pretty/  *.kicad_mod  (from CSE)
        3dmodels/           *.step       (from CSE)

## Quick reference - the values easy to get wrong

Pulled here so you do not have to flip between docs while capturing. If any of
this drifts, the design package / design doc win.

- **Power connector J1** (rear edge, rearward blind-mate): Phoenix
  MC 1,5/5-G-3,81, order 1803303. Pins 1-5 = +5V, +12V, -12V, GND, +3.3V.
- **+3.3V source:** J1 pin 5 (chassis rail) -> FB1/FB2 -> AVDD/DVDD. The Pico
  3V3_OUT is NOT used; leave it unconnected.
- **AD9742 gotchas:** pin 23 RESERVED = leave floating (do not stub to GND);
  pin 25 MODE -> DCOM/GND (straight binary); IOUTA = pin 22, IOUTB = pin 21.
- **Op-amp gain net:** R_in1/R_in2 (R4/R5) = 1k; R_fb/R_ref (R6/R7) = 20k ->
  gain 20 (+/-10V).
- **Reconstruction filter (per leg, x2):** series L 0.22 / 0.68 / 0.22 uH;
  shunt C 820 pF (singly-terminated 5th-order Butterworth).
- **Output-Z relays:** K1 -> R8 (50R) / K2 -> direct (high-Z) / K3 -> R10 (10k).
- **Netclasses:** Power_12V 0.8mm, Power_5V 0.6mm, Power_3V3 0.5mm,
  Analog 0.3mm, DataBus 0.25mm, Default 0.25mm. Min clearance 0.20mm.

## What is committed vs ignored

Committed: `*.kicad_pro` / `*.kicad_sch` / `*.kicad_pcb`, the project library
tables (`sym-lib-table`, `fp-lib-table`), and everything under `lib/PMVB_1E/`.
Ignored (see repo `.gitignore`): KiCad backups, autosave, caches, lock files,
and the per-workstation `*.kicad_prl`.

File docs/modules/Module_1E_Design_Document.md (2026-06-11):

# Module 1E: Function Generator / Arbitrary Waveform Generator

## Module Design Document

**Version:** 1.9 (June 2026, DAC +3.3 V supply moved from the Pico to the chassis Phoenix rail (J1.5); power connector now 5-pin rear-edge blind-mate - see PCB package sections 3 and 6)
**Module ID:** 1E
**Tier:** 1
**Status:** In Design
**Parent SDD section:** 7.5.5 of the [PMVB System Design Document](../system-design/System_Design_Document.html#module-1e-function-generator-arbitrary-waveform-generator)

---

## Table of Contents

- [1. Theory of Operation](#theory-of-operation)
  - [1.1 Overview and signal-flow architecture](#overview-and-signal-flow-architecture)
  - [1.2 Sample clock generator](#sample-clock-generator)
  - [1.3 Address generator and waveform memory](#address-generator-and-waveform-memory)
  - [1.4 DAC stage: current-mode operation](#dac-stage-current-mode-operation)
  - [1.5 Reconstruction filter](#reconstruction-filter)
  - [1.6 Op-amp output stage](#op-amp-output-stage)
  - [1.7 Output impedance switching](#output-impedance-switching)
  - [1.8 Synchronization and trigger](#synchronization-and-trigger)
- [2. Architectural choices](#architectural-choices)
  - [2.1 Parallel data interface (vs SPI)](#parallel-data-interface-vs-spi)
  - [2.2 Current-mode output (vs voltage-mode)](#current-mode-output-vs-voltage-mode)
  - [2.3 Why AD9742 specifically](#why-ad9742-specifically)
- [3. Functional figures](#functional-figures)
- [4. Schematic Notes (high-level; full schematic in KiCad)](#schematic-notes-high-level-full-schematic-in-kicad)
  - [DAC output stage and current-to-voltage conversion](#dac-output-stage-and-current-to-voltage-conversion)
  - [Reconstruction filter](#reconstruction-filter)
  - [Op-amp differential-to-single-ended converter](#op-amp-differential-to-single-ended-converter)
  - [Op-amp supply](#op-amp-supply)
  - [Impedance switching](#impedance-switching)
  - [Decoupling](#decoupling)
- [5. Pin Assignments](#pin-assignments)
  - [Pico 2 W parallel data + clock to AD9742](#pico-2-w-parallel-data-clock-to-ad9742)
  - [Pico 2 W relay control](#pico-2-w-relay-control)
  - [Pico 2 W trigger I/O](#pico-2-w-trigger-io)
  - [Pico 2 W power](#pico-2-w-power)
  - [AD9742 pinout summary](#ad9742-pinout-summary)
  - [AD8056 op-amp output stage](#ad8056-op-amp-output-stage)
- [6. Specifications (matching SDD Table 7-27)](#specifications-matching-sdd-table-7-27)
- [7. Sample Applications](#sample-applications)
  - [7.1 Single-tone sine generation](#single-tone-sine-generation)
  - [7.2 Swept sine for THD measurement (paired with Module 2E)](#swept-sine-for-thd-measurement-paired-with-module-2e)
  - [7.3 Multitone for IMD (intermodulation distortion)](#multitone-for-imd-intermodulation-distortion)
  - [7.4 White noise for noise-floor characterization](#white-noise-for-noise-floor-characterization)
  - [7.5 Clock generation for digital characterization](#clock-generation-for-digital-characterization)
  - [7.6 Bias-mode voltage injection](#bias-mode-voltage-injection)
- [8. Bill of Materials](#bill-of-materials)
- [9. Calibration Procedure](#calibration-procedure)
  - [9.1 DC offset calibration](#dc-offset-calibration)
  - [9.2 Gain calibration](#gain-calibration)
  - [9.3 Frequency calibration](#frequency-calibration)
  - [9.4 Reconstruction filter passband flatness](#reconstruction-filter-passband-flatness)
- [10. Bring-Up Checklist](#bring-up-checklist)
- [11. Known Issues and Future Work](#known-issues-and-future-work)
- [12. References](#references)

---

## 1. Theory of Operation

Module 1E generates analog stimulus waveforms for amplifier characterization, in-ear monitor and headset testing, consumer tube audio gear measurement, clock generation for digital interfaces, and any test recipe that needs a controlled signal driven into a DUT. Single-channel BNC output, DC to 10 MHz, ±10 V into high-impedance loads.

The architecture follows the textbook arbitrary-waveform-generator block diagram (Tektronix / Keysight style): a sample clock generator drives an address generator that walks a waveform memory, which feeds samples into a DAC at the update rate; the DAC's output passes through a reconstruction filter to remove sampling images, then through a signal-conditioning stage (gain, impedance switching) to a front-panel output. Module 1E maps that architecture onto Pico 2 W firmware (the address generator + waveform memory + microprocessor roles all live in a single MCU), an Analog Devices AD9742 12-bit parallel current-output DAC, a 5th-order Butterworth reconstruction filter, an AD8056 high-speed difference amplifier, and a three-position SP3T impedance switch. The eight subsections below describe each block in detail. Section 2 covers the architectural choices (DAC selection, parallel vs SPI interface, current-mode vs voltage-mode) that led to this particular set of parts.

### 1.1 Overview and signal-flow architecture

Figure 1E-1 below maps the textbook AWG architecture onto the Module 1E realization. Bold labels in each block are the standard architectural roles; italic muted text is the part or firmware that fills each role on this board.

**Figure 1E-1: Module 1E AWG functional architecture**

Module 1E AWG functional architecture: textbook AWG blocks mapped to the Pico + AD9742 + AD8056 realization

The signal flows left to right through the main chain (address generator → waveform memory → DAC → reconstruction filter → signal conditioning → BNC). The sample clock generator sits above the chain and drives the address generator, stepping it through waveform memory at the configured sample rate; the DAC latches whatever sample is presented on each clock edge, so in the physical implementation the same clock wire also reaches the DAC's CLOCK pin. The microprocessor / SCPI interface sits below the chain and handles host communication plus loading samples into the waveform memory. Trigger I/O ties to the chassis trigger bus for cross-module synchronization. The Pico fills three textbook roles at once (address generator, waveform memory, microprocessor) using firmware on a single MCU; the DAC, filter, and op-amp are discrete external parts.

### 1.2 Sample clock generator

The DAC's update rate is the foundation of the whole signal chain. It sets the achievable output bandwidth (half the sample rate, per Nyquist) and the position of the first reconstruction image (at f_sample − f_signal). Module 1E targets 30 to 50 MSPS sustained, which gives an output bandwidth ceiling of 10 MHz with comfortable headroom against the reconstruction filter's transition band.

Three real-world effects pull this ceiling well below the Nyquist limit. First, the reconstruction filter has a finite transition band. The first DAC image lands at f_sample − f_signal, and the filter has to be in passband for f_signal but in stopband for the image; the wider that gap, the more attenuation the 5th-order Butterworth provides. At 50 MSPS with a 10 MHz signal the image lands at 40 MHz and gets knocked down by roughly 52 dB, but at 30 MSPS the image is at 20 MHz and only sees about 22 dB of rejection. Second, the AD9742's zero-order-hold output applies a sinc(πf/f_sample) amplitude envelope that droops as you approach Nyquist: -0.58 dB at 10 MHz / 50 MSPS, -1.65 dB at 10 MHz / 30 MSPS, and -3.92 dB at f_sample/2 itself. Third, industry practice for AWG analog-bandwidth specifications is f_sample/3 to f_sample/5 rather than the theoretical Nyquist limit (NI's PXIe-5413 specs 20 MHz on 100 MSPS, Tek's AFG31000 specs 50 MHz on 250 MSPS). Module 1E follows the same convention: 10 MHz / 30 MSPS = f_sample/3 (the worst-case floor) and 10 MHz / 50 MSPS = f_sample/5 (the comfortable burst case).

The clock comes from the Pico 2 W's RP2350 internal 150 MHz system clock, divided down by a PIO state machine. The state machine drives the address generator at the configured sample rate, advancing through waveform memory and presenting each new 12-bit sample on the DAC's data pins; the same clock edge is wired to the DAC's CLOCK input, so the DAC latches the new value in lockstep. Using PIO (not a hardware timer or PWM peripheral) is what makes this work: a timer-and-ISR approach can't sustain 50 MHz determinism on the M33 cores, and a PWM peripheral can only toggle one pin per cycle, not the 12 data pins plus the clock pin in phase. The whole stream runs with deterministic single-cycle timing, off the CPU entirely.

Two clock-accuracy modes are available:

- **Standalone.** The RP2350 crystal alone, ±20 ppm tolerance. At 10 MHz output that is ±200 Hz absolute accuracy. Fine for most characterization work.
- **Locked to external 10 MHz reference.** The chassis trigger bus distributes a 10 MHz GPSDO or TCXO reference (sourced from Module 2C if populated). Pico firmware can phase-lock to this reference for ±2 ppm accuracy (±20 Hz at 10 MHz output).

Sustained update rate caps out around 50 MSPS for short bursts but drops to 30 to 40 MSPS for continuous operation, because the Pico's PIO + DMA needs roughly 75 MB/s of SRAM-to-PIO-FIFO throughput at the upper limit, which is at the edge of what RP2350 can do reliably without preemption from other firmware tasks. This 30 MSPS floor is what drives the conservative 10 MHz bandwidth ceiling specified above: a long sustained run will settle into the 30 to 40 MSPS regime, so the host has to plan for the worst-case droop and image rejection numbers, not the burst-case ones. Module 1E firmware reports the achieved update rate as a SCPI status query so the host always knows which regime it's operating in and can either accept the working conditions or pause concurrent activity to recover burst-rate headroom.

### 1.3 Address generator and waveform memory

Two operating modes share the same DAC streaming path: DDS mode for parametric waveforms (sines, sweeps, multitones, squares, triangles, ramps) and ARB mode for arbitrary sample tables. The mode is selected by SCPI command (`SOUR:FUNC SIN` selects DDS-sine, `SOUR:DATA <samples>` loads ARB).

**DDS mode (Numerically Controlled Oscillator).** No waveform table of the output signal exists; instead, Pico Core 1 runs a Numerically Controlled Oscillator (NCO) in firmware that synthesizes samples on the fly. The NCO has three pieces:

1. A **phase accumulator**, a 32-bit `uint32_t` register in Pico SRAM advanced by a constant value (the **frequency tuning word**, FTW) on every sample tick. It wraps at 2^32, which is the digital equivalent of phase going from 0 to 2π and back. Figure 1E-2 shows the textbook NCO internals: an FTW register feeds an adder whose output latches into the phase register, with the phase register output feeding back to the adder via a 32-bit bus.
2. A **waveform lookup table**, a 1024-entry × 12-bit array of precomputed amplitude values for the selected shape (sine, triangle, square, or ramp). The top 10 bits of the phase accumulator index this table.
3. The downstream **PIO + DMA → DAC chain** from section 1.2, which clocks the LUT output out to the AD9742 at the sustained sample rate.

**Figure 1E-2: Phase accumulator (textbook DDS view)**

Phase accumulator: FTW register feeds an adder whose output latches into the Phase register, clocked by f_CLK, with the Phase register output feeding back to the adder via a 32-bit bus. Top 10 bits of the accumulator address the waveform LUT.

The output frequency is set by the FTW: f_out = FTW × f_sample / 2^32, inverted as FTW = round(f_out × 2^32 / f_sample). At 50 MSPS, the smallest FTW change of 1 LSB corresponds to a frequency step of f_sample / 2^32 ≈ 11.6 mHz, so any target frequency is hit within ±5.8 mHz of the request. This is where the "microhertz-class frequency resolution" claim comes from.

The reason for the 32-bit accumulator (rather than indexing the LUT directly with a 10-bit counter) is exactly that resolution. A 10-bit phase counter alone would only reach 1024 discrete output frequencies; the 22-bit fractional part below the LUT-index bits gives a smooth phase ramp between table entries even though those finer bits are thrown away at lookup time. The discarded precision shows up as a small spurious tone called **phase truncation noise** at roughly 6 × M dB below carrier (where M is the number of bits kept). At M = 10 that's about 60 dB spur-free dynamic range, which sits below the 12-bit DAC's quantization floor of 74 dB, so phase truncation doesn't dominate the spectrum.

Core 0 sits outside the NCO loop, parsing incoming SCPI commands (`SOUR:FREQ`, `SOUR:FUNC`, `OUTP`) and writing updated FTW or LUT-pointer values to shared SRAM locations. Core 1 picks up those values on the next sample tick. This lets the host change frequency, waveform shape, or amplitude without halting the sample stream, which enables continuous frequency sweeps and parameter modulation.

**Arbitrary waveform (ARB) mode**: the waveform sample table sits in Pico SRAM (520 KB total, of which up to ~256K 16-bit samples can be a single waveform), and the address generator is a DMA channel walking the table in a loop. Played-out duration at 50 MSPS is about 5 ms per loop iteration. For waveforms longer than SRAM, the firmware can stream from the Pico's 4 MB external flash via XIP DMA (caps at roughly 2 M 16-bit samples = ~40 ms at 50 MSPS), with the trade that flash bandwidth is the new ceiling and continuous flash reads compete with code execution.

The same firmware can also generate noise (linear-feedback PRNG) and modulated carriers (DDS + envelope) without a sample table. Together these cover the workloads in section 7 (Sample Applications) without needing the host to push data over USB-TMC mid-stream.

### 1.4 DAC stage: current-mode operation

The AD9742 is a 12-bit current-output DAC. Internally it is an array of segmented PMOS current sources whose total sums to the full-scale current I_FS. The 12-bit input code routes each segment to either of two output pins (IOUTA or IOUTB), with the constraint that the sum I_A + I_B always equals I_FS. The difference I_A − I_B varies linearly with the input code, and that is where the signal lives.

**Figure 1E-3: AD9742 current-mode DAC operation (simplified)**

Conceptual view of AD9742 current-mode operation: PMOS source array, code-driven switching to IOUTA/IOUTB, load resistors and FSADJ

The "segmented" part of segmented PMOS current sources deserves a closer look, because it's why the AD9742 can hit its dynamic-performance specs. Rather than building 12 binary-weighted current sources (where the MSB is 2048 times the LSB), the AD9742 splits the 12 bits across three tiers: the 5 MSBs are 31 unary-decoded segments at I_FS/32 each (~625 µA), the 4 middle bits are 15 unary-decoded sub-segments at 1/16 of an MSB segment each (~39 µA), and the 3 LSBs are binary-weighted fractions of a middle-bit segment. That's 49 nominal current sources for 12 bits of resolution. The reason for the complexity is glitch performance at the MSB transition. A pure binary-weighted DAC has to turn one giant current source ON while turning many small ones OFF when the code rolls from 0x7FF to 0x800, and any mismatch shows up as a code-correlated voltage glitch that's visible on a spectrum analyzer as harmonic distortion. Unary segmentation makes the transition monotonic by construction: code N+1 just turns on one additional sub-current of the same nominal value as all the others. The bottom 3 LSBs stay binary-weighted because the glitch penalty at that magnitude is below the part's noise floor.

Four parameters set the operating point:

- **I_FS** is set by the external FSADJ resistor: I_FS = 32 × 1.2 V / R_FSADJ. We use R_FSADJ = 1.91 kΩ for I_FS ≈ 20 mA. Valid I_FS range per the AD9742 datasheet is roughly 2 mA to 20 mA for spec'd performance; below 2 mA the current sources lose matching, above 20 mA the part is outside characterized operating conditions.
- **R_load** converts each leg's current to voltage. We use 25 Ω from each of IOUTA, IOUTB to AGND. V per leg = I_leg × R_load, so at full-scale on one leg the voltage is 0.5 V.
- **Compliance voltage** is the range in which each output pin's voltage can sit while the PMOS current sources stay in saturation. AD9742 datasheet: −1.0 V to +1.25 V from ACOM. With 20 mA × 25 Ω = 0.5 V per leg, we have ~2× margin. Exceeding compliance does not damage the chip but causes current droop and degrades INL / DNL / THD.
- **MODE pin** is a data-format strap: tied to DCOM (GND) selects straight binary, tied to DVDD selects twos complement. This module ties MODE to GND, so Pico firmware emits straight-binary sample codes. NOT a parallel/serial mode select.

The differential voltage at the filter input swings ±I_FS × R_load = ±0.5 V (1 V peak-to-peak) across the full 12-bit code range. That 1 V_pp differential signal is what the downstream filter and difference amp scale to the final ±10 V single-ended output.

Concrete code-to-output mapping for the worst-case extremes: code 0x000 routes all 20 mA to IOUTB (V_A = 0 V, V_B = 0.5 V, differential = -0.5 V); code 0xFFF routes all to IOUTA (differential = +0.5 V); code 0x800 (midscale) splits the current evenly across the segments (V_A = V_B = 0.25 V, differential = 0 V). Bipolar AWG signals are written in straight binary with midscale at 0x800 so the zero-crossing of a sine corresponds to that code, peaks of the sine correspond to 0x000 and 0xFFF, and the differential output naturally swings symmetrically around 0 V. The 0.25 V common-mode bias on each leg gets rejected by the AD8056 difference amplifier's CMRR (section 1.6).

### 1.5 Reconstruction filter

Sampling theory says that converting a discrete sample sequence back to a continuous signal is the dual of the ADC anti-alias problem. On the ADC side you place an anti-alias filter BEFORE the sampler to keep above-Nyquist content from folding into the band. On the DAC side you place a reconstruction filter AFTER the DAC to remove the sampling IMAGES that appear at multiples of the sample frequency.

Two phenomena combine to create the output spectrum:

1. **Sampling** copies the baseband spectrum to every multiple of f_sample (positive and negative). For a 10 MHz tone at f_sample = 50 MSPS, the spectrum contains the original 10 MHz plus images at 40 MHz, 60 MHz, 90 MHz, 110 MHz, and so on. These are not harmonics from any nonlinearity — they are a mathematical consequence of sampling.
2. **Sample-and-hold (ZOH)** at the DAC output multiplies the spectrum by a sinc envelope (sin(πf/f_s) / (πf/f_s)). This naturally attenuates the higher images, but not enough on its own to clean up the output.

**Figure 1E-4: DAC output spectrum at 50 MSPS burst-rate (best case)**

DAC output spectrum at 50 MSPS burst rate: baseband at 10 MHz, first image at 40 MHz attenuated by ~52 dB after the 5th-order Butterworth

The reconstruction filter does the rest of the work. Module 1E uses a 5th-order Butterworth lowpass with ~12 MHz cutoff, implemented as two per-leg L-C-L-C-L ladders (one on the IOUTA path, one on IOUTB). For the 50 MSPS burst-rate case (Figure 1E-4 above), the worst-case 10 MHz output has its first image at 40 MHz, attenuated by ~52 dB after the filter (the dot in the green post-filter envelope). At lower output frequencies the first image moves further into the stop band, so image rejection improves to 60–80 dB.

**Figure 1E-5: DAC output spectrum at 30 MSPS sustained-rate floor (worst case)**

DAC output spectrum at 30 MSPS sustained rate: baseband at 10 MHz, first image now at 20 MHz attenuated by only ~22 dB, ZOH sinc droops harder

Figure 1E-5 shows the same configuration at the 30 MSPS continuous-operation floor. The first image now lands at 20 MHz instead of 40 MHz (much closer to the 12 MHz filter cutoff), so the Butterworth only knocks it down by ~22 dB instead of ~52 dB. The ZOH sinc envelope also droops harder, -1.65 dB at the 10 MHz output instead of -0.58 dB, since the signal is now 1/3 of f_sample rather than 1/5. This is the regime to plan for under any sustained-run condition where the firmware can't hold the 50 MSPS burst rate; the SCPI status query in section 1.2 lets the host see which regime it's currently operating in.

The filter cutoff is the upper-bandwidth limit of the module. Pushing it higher would let the output reach beyond 10 MHz but at the cost of less attenuation of the first image (which would sit closer to the cutoff). The 5th-order Butterworth + 12 MHz cutoff is sized so that 10 MHz output is at the -3 dB point and the first image is comfortably in the stop band.

**Images vs harmonics.** Images live at f_sample ± f_signal and its multiples (sampling artifacts; the recon filter removes them). Harmonics live at 2 × f_signal, 3 × f_signal, etc. (nonlinearity artifacts from the DAC's INL/DNL, op-amp THD; the recon filter does not remove them when they fall in the passband). At high output frequencies the filter does double duty, killing images AND knocking down out-of-band harmonics; at low output frequencies (audio band), harmonics in the passband are governed entirely by the linearity of the DAC and op-amp.

Component values come from a completed 5th-order Butterworth synthesis (PCB design package finding D2), run as a singly-terminated design for the actual per-leg impedances: a 25 Ω DAC source termination driving the op-amp's high-impedance (≈1 kΩ) input. That 40:1 source/load ratio rules out a doubly-terminated ladder, so each leg uses a singly-terminated L-C-L-C-L Butterworth with series inductors 0.22 µH / 0.68 µH / 0.22 µH and shunt capacitors 820 pF. Simulated response is -3 dB at ≈11 MHz with ≈51 dB image rejection at 40 MHz (50 MSPS) and ≈26 dB at 20 MHz (30 MSPS); the ≈1.5 dB passband droop to 10 MHz is removed by the stored frequency-response calibration of section 9.4.

Figure 1E-6 shows why the termination model matters. All three curves are the same physical circuit (25 Ω source, ~1 kΩ load); only the L/C values differ. The two doubly-terminated designs ripple 6 to 11 dB across the passband because the real 40:1 source/load ratio is not the matched condition they assume, while the singly-terminated design the board uses stays smooth.

**Figure 1E-6: Reconstruction filter response, singly- vs doubly-terminated design**

Reconstruction filter magnitude response: three 5th-order Butterworth designs in the same 25 ohm source / 1 kohm load circuit. The two doubly-terminated designs (50 ohm and 158 ohm) ripple 6 to 11 dB across the passband; the singly-terminated design the board uses stays smooth with about 1.5 dB dro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

### 1.6 Op-amp output stage

The AD8056 is a dual high-speed voltage-feedback op-amp (300 MHz GBW, 1400 V/µs slew rate). Channel A operates as a difference amplifier; channel B is unused and terminated to prevent oscillation (+IN to GND, -IN tied to its own output).

The difference-amp topology is the classic four-resistor configuration:

- The filtered IOUTA signal feeds the +IN pin through R_in1 = 1 kΩ
- The filtered IOUTB signal feeds the -IN pin through R_in2 = 1 kΩ
- A feedback resistor R_fb = 20 kΩ closes the loop from output to -IN
- A reference resistor R_ref = 20 kΩ ties +IN to GND for CMRR balance

The differential gain is R_fb / R_in = 20. With the 1 V_pp differential signal from the filter, the single-ended output is 20 V_pp = ±10 V peak (into a high-impedance load).

**Slew-rate budget.** For a ±10 V output sine at 10 MHz, the required peak slew is 2π × 10 MHz × 10 V = 628 V/µs. The AD8056's 1400 V/µs gives ~2.2× margin, so slew limiting does not contribute to distortion within the spec band.

**Bandwidth budget.** The AD8056's 300 MHz gain-bandwidth product divided by the closed-loop gain of 20 gives ~15 MHz closed-loop bandwidth. That sits just above the recon filter's 12 MHz cutoff, so the op-amp is not the dominant bandwidth limit (the recon filter is).

**Output current and load.** The AD8056 sources up to about 60 mA continuous. Into a 50 Ω terminated scope load (so 50 Ω back-termination + 50 Ω scope termination = 100 Ω effective), the output is clamped to ~±6 V op-amp swing (60 mA × 100 Ω), which becomes ~±3 V at the scope after the back-termination divider. Into a 1 MΩ high-Z load, the full ±10 V op-amp swing reaches the BNC. See section 6 Specifications for the full by-load amplitude breakdown.

### 1.7 Output impedance switching

The output stage selects one of three source impedances via three SPST reed relays gated by Pico GPIOs. Firmware enforces one-relay-at-a-time so the BNC sees exactly one source impedance.

- **50 Ω (back-terminated)** for oscilloscope inputs at 50 Ω, RF gear, transmission lines that need source-termination to prevent reflections. Effective output amplitude is ~±3 V at a 50 Ω terminated scope, or ~±5 V at the scope under proper double termination.
- **High-Z (low-impedance source)** for 1 MΩ scope inputs, consumer audio gear with 47-100 kΩ line inputs (including hybrid and tube headphone amps such as the Bravo Audio Ocean), or general high-impedance test points. The op-amp drives the BNC directly through a relay with no series back-termination resistor, so the source impedance is the op-amp's sub-ohm closed-loop output. The full ±10 V swing is available into high-impedance loads.
- **10 kΩ (current-limited bias)** for safely injecting a known voltage onto an unknown DUT node (a digital pin, a sensor input, a calibration test point). The 10 kΩ series resistor caps fault current at V/R: at ±10 V into a short, that is ±1 mA absolute worst case, well below the clamp-diode rating of any 3.3 V or 5 V CMOS input. This is the safe-bias mode for poking at hardware where you do not fully trust the state of every node.

### 1.8 Synchronization and trigger

Two GPIOs on the Pico expose the module's relationship with the chassis trigger bus:

- **SYNC_OUT (GP16)** can be configured as a one-cycle pulse at the start of each waveform period (for synchronizing scope captures to AWG output) or as a continuous gate (for protocol-level handshaking). It ties to the chassis-wide trigger bus, so other modules on that bus (especially Module 2E for FFT-based capture) can lock their captures to Module 1E's output without software-arming jitter.
- **TRIG_IN (GP17)** accepts an external trigger from the chassis trigger bus, allowing the AWG to start its waveform on an external event (a digital edge from another module, a button press routed through the chassis, an external instrument's trigger output).

The trigger bus also distributes the 10 MHz reference clock used for the cross-module sample-rate locking described in section 1.2.

## 2. Architectural choices

The hardware platform (Pico 2 W) and the DAC (AD9742) were selected together to hit the bandwidth, resolution, cost, and hand-solderability targets for a hobbyist-budget AWG. The three subsections below cover the DAC interface choice (parallel vs serial), the output topology choice (current-mode vs voltage-mode), and why the AD9742 specifically over the family alternatives.

### 2.1 Parallel data interface (vs SPI)

The AD9742 uses a parallel data interface: 12 data bits plus a clock pin. The Pico drives all 13 lines simultaneously from a PIO state machine + DMA. This trades two things for two others, compared to a SPI-driven DAC:

- **Trade 1 (positive)**: parallel lets the DAC update at the Pico's full PIO clock rate (up to 150 MHz on RP2350). 50+ MSPS sample rate is reachable, giving analog output bandwidth into the 10s of MHz. SPI on the Pico maxes around 30–50 MHz, which after the 16-bit-per-sample transfer overhead caps a SPI DAC at ~2–3 MSPS — audio band only.
- **Trade 2 (positive)**: 28-TSSOP package, 0.65 mm pitch, hand-solderable with a fine-tip iron and flux. Compare to AD9106 (32-LFCSP, 0.4 mm pitch QFN with thermal pad) which needs hot-air rework. The SDD's hand-solderability constraint puts TSSOP in scope without special equipment.
- **Trade 3 (negative)**: parallel uses 13 GPIOs vs SPI's 4. Pico has 40 GPIOs and plenty to spare, so this is a non-issue in practice.
- **Trade 4 (negative)**: the Pico has to stream samples in real time — there is no internal pattern memory or DDS engine on the AD9742. At 50 MSPS this requires ~75 MB/s sustained SRAM-to-PIO-FIFO throughput, which is at the edge of RP2350 capability. In practice the module runs 30–50 MSPS depending on waveform complexity. This is the constraint that puts long arbitrary-waveform replay as the deferred future capability (a Tier 2 evolution would put the Tang Primer 25K between Pico and DAC to absorb the streaming load).

For the typical AWG workload (DDS-generated sines, sweeps, multitone, noise, square / triangle / ramp, and ARB waveforms up to ~256K samples), the parallel choice is correct.

### 2.2 Current-mode output (vs voltage-mode)

The AD9742's output is a complementary differential current pair (IOUTA + IOUTB summing to I_FS). External load resistors convert the currents to voltages. This contrasts with voltage-output DACs (MCP4922, DAC8512, and similar) which have an internal op-amp buffering the output to a voltage directly.

Four reasons current-mode is the standard for AWG-class parts:

- **Speed.** Voltage-output DACs have an internal op-amp bounding their settling time (typically microseconds for 12-bit at this resolution class). Current-output skips that op-amp entirely; settling is set by the external R-C, which we control. At our 25 Ω termination and a few pF of stray capacitance, settling is under 10 ns. That is the difference between a 1 MHz AWG and a 10 MHz AWG.
- **Differential output for free.** Because IOUTA and IOUTB are complementary by construction, using both legs gives 6 dB of dynamic range (the difference is twice each leg's swing), common-mode noise rejection (clock feedthrough, supply noise, code-correlated glitches cancel), and a DC-offset-free differential signal. Voltage-output DACs at this resolution are almost all single-ended; you give up all three benefits.
- **Distortion is transparent.** The AD9742's INL/DNL spec describes the current-source array directly. With voltage-output DACs, the published spec is the array, but what you measure at the output also includes the internal buffer's THD, which usually dominates at MHz frequencies.
- **External I-to-V is yours to shape.** The 25 Ω termination + recon filter + AD8056 difference-amp split is a deliberate design. Each stage is independently tunable. With voltage-output that whole path is fused inside the chip and inaccessible.

The cost is BOM complexity (more external parts) and the compliance-voltage constraint discussed in section 1.4.

### 2.3 Why AD9742 specifically

Within the 12-bit, ~200 MSPS, parallel current-output category, the AD9742 won on three axes:

- **Package.** 28-TSSOP fits the SDD's hand-solderability constraint. The next step up in capability (AD9106 with on-chip pattern memory + DDS engine) is 32-LFCSP, which is in scope per SDD constraint 2 but requires hot-air rework.
- **Cost.** ~$14.80 single-quantity at Digi-Key. AD9744 (14-bit, same package family) is similar; AD9106 is ~$20-30.
- **Family pin compatibility.** AD9740 (10-bit), AD9742 (12-bit), AD9744 (14-bit) are pin-compatible. The board can be upgraded to 14-bit resolution without a PCB respin if the downstream analog chain ever justifies it.

Two near-misses considered and dropped: AD9106 (would solve the Pico-streaming bandwidth pressure entirely with on-chip 4096-sample pattern memory + DDS, but the LFCSP package and higher cost moved it out of scope for the v1.0 hobbyist build); MCP4922 (12-bit SPI dual, trivial to drive, but caps at audio-band sample rates).

See the PCB design package (`hardware/modules/1E/Module_1E_PCB_Design_Package.md`) section 2 for the engineering decisions (D1 through D7) that further refine the as-built design within the AD9742-based architecture.

## 3. Functional figures

The AD9742's internal block diagram (from the datasheet) and a typical-application schematic showing the full Pico-to-BNC signal chain. Figure 1E-1 (AWG functional architecture) is in section 1.1; Figure 1E-2 (phase accumulator) is in section 1.3; Figure 1E-3 (current-mode DAC operation) is in section 1.4; Figures 1E-4 and 1E-5 (DAC output spectrum at 50 MSPS and 30 MSPS) and Figure 1E-6 (reconstruction filter response) are in section 1.5.

**Figure 1E-7: AD9742 internal functional block diagram**

AD9742 internal block diagram, redrawn from datasheet Rev. C

*Source: AD9742 datasheet (Rev. C), page 1. Analog Devices Inc. Used under fair-use citation for technical reference.*

**Figure 1E-8: Module 1E typical application schematic**

Pico 2 W → AD9742 → reconstruction filter → AD8056 → 50/high-Z/10kΩ relay → BNC

*Schematic shows the parallel data interface from Pico to AD9742, the differential current outputs through 25 Ω termination resistors and the 5th-order Butterworth reconstruction filter, the AD8056 differential-to-single-ended op-amp converter with gain to ±10 V, and the three-position SP3T impedance-switching network feeding the BNC output.*

## 4. Schematic Notes (high-level; full schematic in KiCad)

### DAC output stage and current-to-voltage conversion

The AD9742 produces complementary differential currents at IOUTA and IOUTB. Full-scale current is set by an external precision resistor at the FSADJ pin (per the AD9742 datasheet section "Reference Operation"); we use a 1.91 kΩ ±0.1% resistor to set FS_CUR ≈ 20 mA. Each output drives a 25 Ω 0.1% precision termination resistor to AGND. The differential voltage swing at the op-amp input is therefore ±0.5 V peak across each 25 Ω resistor (depending on the digital input code), giving a 1 V differential signal that the op-amp scales to the final ±10 V single-ended output.

### Reconstruction filter

A 5th-order Butterworth low-pass filter sits between the DAC's differential output and the op-amp input. It is synthesized as two identical per-leg ladders (one per differential leg), singly-terminated for the 25 Ω per-leg DAC termination into the op-amp's high-impedance (≈1 kΩ) input, -3 dB at ≈11 MHz (PCB design package finding D2). Standard ladder topology (L–C–L–C–L) with the values:

- Series inductors L1 = L5 ≈ 0.22 µH and L3 ≈ 0.68 µH, 0805 wirewound (e.g. Coilcraft 0805 family; confirm exact P/N)
- Shunt capacitors C2 = C4 ≈ 820 pF, C0G 0603 ±5 % (e.g. Murata GCM/GRM C0G; confirm exact P/N)

Tabulated normalized Butterworth values are in the Analog Devices DAC application note AN-282 and equivalents; tolerances on these passives directly affect passband ripple, so 5 % C0G capacitors and ±5 % wirewound chip inductors are the minimum specifications. Better tolerances (1 % caps, 2 % inductors) produce flatter passband response if budget permits.

### Op-amp differential-to-single-ended converter

The AD8056 channel A is configured as a difference amplifier:

- IN+ receives the filtered IOUTA signal through R_in1 (1 kΩ)
- IN− receives the filtered IOUTB signal through R_in2 (1 kΩ)
- Feedback resistor R_fb (20 kΩ) sets the differential gain to 20
- Reference resistor R_ref (20 kΩ) at IN+ to ground sets the common-mode rejection

The differential gain R_fb / R_in = 20 takes the 1 V_pp differential filter output to 20 V_pp = ±10 V single-ended, matching the module output spec. Scaling the R_fb / R_in ratio shifts the output range.

### Op-amp supply

The AD8056 is rated for ±5 V to ±13.5 V supply (refer to the datasheet Absolute Maximum Ratings). We power it from the chassis TX300 PSU's +12 V and -12 V rails, giving comfortable headroom for the ±10 V output swing. The op-amp's 1400 V/µs slew rate provides about 2.2× margin for the worst-case full-amplitude 10 MHz sine (which needs 628 V/µs), so harmonic distortion from slew limiting is negligible.

### Impedance switching

Three Coto 9007-05-01 SPST-NO reed relays (5 V coils, signal-grade) sit between the op-amp output and the three output modes:

- Relay 1 → 50 Ω 1% resistor → BNC center (50 Ω back-terminated mode)
- Relay 2 → BNC center **directly, no series resistor** (high-Z low-source-impedance mode)
- Relay 3 → 10 kΩ 1% resistor → BNC center (current-limited bias mode)

Pico GPIO drives each relay through a 2N3904 transistor and a 1N4148 flyback diode across the coil. The Pico firmware enforces "only one relay energized at a time" so the BNC sees exactly one source impedance. Reed relays were chosen over solid-state analog switches because their on-resistance is essentially zero (no series error added to the 50 Ω termination), they have signal-grade isolation in the off state, and they handle bidirectional signals cleanly.

### Decoupling

Every IC supply pin gets a 0.1 µF X7R 0603 ceramic placed within 4 mm of the pin. The AD9742 additionally gets a 10 µF 10 V X5R bulk cap at the supply entry per the datasheet section "Power Supply Bypassing." AVDD and DVDD pins are decoupled separately with their own 0.1 µF caps to avoid digital noise coupling into the analog reference. The op-amp gets two 0.1 µF caps (one per supply rail, V+ and V−) plus a shared 10 µF bulk cap.

## 5. Pin Assignments

### Pico 2 W parallel data + clock to AD9742

The Pico's PIO state machine drives 12 contiguous GPIOs as the parallel data bus, plus one GPIO for the DAC clock. Using GP0–GP11 for data keeps the PIO instruction simple (single shift register output to a contiguous pin range).

| Pico Pin | GP | Function | AD9742 Pin | Notes |
|---|---|---|---|---|
| 1 | GP0 | DB0 (LSB) | 12 | parallel data bit 0 |
| 2 | GP1 | DB1 | 11 | parallel data bit 1 |
| 4 | GP2 | DB2 | 10 | parallel data bit 2 |
| 5 | GP3 | DB3 | 9 | parallel data bit 3 |
| 6 | GP4 | DB4 | 8 | parallel data bit 4 |
| 7 | GP5 | DB5 | 7 | parallel data bit 5 |
| 9 | GP6 | DB6 | 6 | parallel data bit 6 |
| 10 | GP7 | DB7 | 5 | parallel data bit 7 |
| 11 | GP8 | DB8 | 4 | parallel data bit 8 |
| 12 | GP9 | DB9 | 3 | parallel data bit 9 |
| 14 | GP10 | DB10 | 2 | parallel data bit 10 |
| 15 | GP11 | DB11 (MSB) | 1 | parallel data bit 11 |
| 16 | GP12 | CLOCK | 17 | DAC sample clock from Pico PIO |

### Pico 2 W relay control

| Pico Pin | GP | Function | Notes |
|---|---|---|---|
| 17 | GP13 | RELAY_50 | drives 2N3904 base for 50 Ω relay coil |
| 19 | GP14 | RELAY_HIZ | drives 2N3904 base for high-Z (no-series-R) relay coil |
| 20 | GP15 | RELAY_10K | drives 2N3904 base for 10 kΩ relay coil |

Firmware enforces mutually exclusive relay energizing.

### Pico 2 W trigger I/O

| Pico Pin | GP | Function | Notes |
|---|---|---|---|
| 21 | GP16 | SYNC_OUT | sync pulse to chassis trigger bus (configurable as period sync or continuous gate) |
| 22 | GP17 | TRIG_IN | trigger input from chassis bus, for synchronized stimulus start |

### Pico 2 W power

| Pico Pin | Function | Notes |
|---|---|---|
| 39 | VSYS | 5 V from chassis (USB-bus-powered via Pi 5 USB hub) |
| 38 | GND | shared chassis ground |
| 36 | 3V3_OUT | not connected (DAC +3.3 V now from chassis Phoenix J1.5, not the Pico) |

### AD9742 pinout summary

| AD9742 Pin | Function | Connects to |
|---|---|---|
| 1–12 | DB11–DB0 (parallel data, MSB to LSB) | Pico GP11–GP0 |
| 13, 14 | NC | leave unconnected |
| 15 | SLEEP | tied to GND for normal operation (internal pull-down) |
| 16 | REFLO | tied to AGND for internal-reference mode |
| 17 | REFIO | internal reference output; 0.1 µF decoupling to AGND |
| 18 | FS ADJ | 1.91 kΩ ±0.1 % to AGND, sets full-scale current ≈ 20 mA |
| 19 | NC | leave unconnected |
| 20 | ACOM | analog ground |
| 21 | IOUTB | 25 Ω termination to AGND; reconstruction filter leg B input |
| 22 | IOUTA | 25 Ω termination to AGND; reconstruction filter leg A input |
| 23 | RESERVED | **leave unconnected** (per AD9742 datasheet Rev. C, do not tie to common or supply) |
| 24 | AVDD | +3.3 V from chassis (Phoenix J1.5) through ferrite bead filter to AVDD |
| 25 | MODE | data-format strap: tie to DCOM for straight binary (this module), or to DVDD for twos complement. NOT a parallel/serial mode select. |
| 26 | DCOM | digital ground |
| 27 | DVDD | +3.3 V from chassis (Phoenix J1.5) through separate ferrite bead filter to DVDD |
| 28 | CLOCK | Pico GP12, sample clock latched on rising edge |

**Pinout source:** AD9742 datasheet Rev. C, Table 6 (28-Lead SOIC/TSSOP). The previous v1.1 of this table had pins 13–28 mis-assigned and listed pin 25 MODE as "tied to GND for parallel mode," which was a misreading; MODE is a data-format strap. See the PCB design package finding D5 (`hardware/modules/1E/Module_1E_PCB_Design_Package.md`) for the correction history.

### AD8056 op-amp output stage

| AD8056 Pin | Function | Connects to |
|---|---|---|
| 1 | OUT (channel A) | reconstruction filter output → impedance-switching relay matrix |
| 2 | IN− (channel A) | filter IOUTB output through R_in2 (1 kΩ) and feedback R_fb (20 kΩ) |
| 3 | IN+ (channel A) | filter IOUTA output through R_in1 (1 kΩ); R_ref (20 kΩ) to GND for CMRR |
| 4 | V− | −12 V from chassis TX300 |
| 5 | IN+ (channel B) | unused; tied to GND |
| 6 | IN− (channel B) | unused; tied to OUT (channel B) |
| 7 | OUT (channel B) | unused (channel B reserved for v1.1 stereo or differential output) |
| 8 | V+ | +12 V from chassis TX300 |

## 6. Specifications (matching SDD Table 7-27)

| Parameter | Value |
|---|---|
| DAC | AD9742, 12-bit, 210 MSPS-capable |
| DAC update rate (operating) | 30–50 MSPS via Pico PIO + DMA |
| Channels | 1 single-ended output (channel B reserved for v1.1) |
| Standard waveforms | sine (DDS), square, triangle, ramp, noise, multitone, arbitrary |
| Arbitrary waveform depth | up to ~256 K samples (limited by Pico SRAM) |
| Output range | ±10 V into high-Z load; ~±3 V into 50 Ω terminated (AD8056 output-current limit; see PCB design package §3) |
| Output impedance (selectable) | 50 Ω / high-Z / 10 kΩ via SPST reed relays |
| Frequency range | DC to 10 MHz |
| Frequency accuracy | ±20 ppm crystal; ±2 ppm with external 10 MHz reference via chassis trigger bus |
| Amplitude resolution | 12-bit (~5 mV at 20 V FS span) |
| Slew rate | 1400 V/µs (AD8056-limited) |
| THD (typical, audio band) | < 0.1 % (limited by DAC INL/DNL) |
| Reconstruction filter | 5th-order Butterworth, ~12 MHz cutoff, ~50 dB image rejection at 40 MHz |

## 7. Sample Applications

### 7.1 Single-tone sine generation

```python
import pyvisa
rm = pyvisa.ResourceManager('@py')
awg = rm.open_resource('USB::0xCAFE::0x4001::PMVB1E::INSTR')
awg.write('OUTP:IMP 50')             # select 50 Ω output impedance
awg.write('SOUR:FUNC SIN')
awg.write('SOUR:FREQ 1000')
awg.write('SOUR:VOLT 1.0')           # 1 V peak-to-peak
awg.write('OUTP ON')
input('Press Enter to stop...')
awg.write('OUTP OFF')
awg.close()
```

### 7.2 Swept sine for THD measurement (paired with Module 2E)

```python
import numpy as np
from scipy.fft import rfft, rfftfreq

awg = open_module('1E')
scope = open_module('2E')

awg.write('OUTP:IMP 50')
frequencies = np.logspace(np.log10(20), np.log10(20000), 31)
results = []

for f in frequencies:
    awg.write(f'SOUR:FUNC SIN; SOUR:FREQ {f}; SOUR:VOLT 1.0; OUTP ON')
    scope.write('DIG:CONF 0, 5.0, AC; DIG:RATE 1000000; DIG:DEPTH 100000; DIG:ARM')
    samples = np.array(scope.query_binary_values('DIG:DATA? 0', datatype='f'))
    spectrum = np.abs(rfft(samples))
    freqs = rfftfreq(len(samples), 1/1e6)
    fund_bin = np.argmin(np.abs(freqs - f))
    fund = spectrum[fund_bin]
    harms = [spectrum[np.argmin(np.abs(freqs - f*n))] for n in range(2, 6)]
    thd = np.sqrt(sum(h**2 for h in harms)) / fund
    results.append((f, thd))
    awg.write('OUTP OFF')

for f, thd in results:
    print(f'{f:8.1f} Hz: THD = {thd*100:.3f}%')
```

### 7.3 Multitone for IMD (intermodulation distortion)

```python
awg.write('OUTP:IMP 50')
awg.write('SOUR:MULT:UPLD [1000, 1100], [0.5, 0.5]')   # SMPTE-style 60/7 ratio variant
awg.write('SOUR:VOLT 1.0; OUTP ON')
# Capture and FFT-analyze for sum/difference products near 100 Hz, 2.0 kHz, etc.
```

### 7.4 White noise for noise-floor characterization

```python
awg.write('OUTP:IMP 50')
awg.write('SOUR:FUNC NOIS')
awg.write('SOUR:VOLT 0.5; OUTP ON')
# Capture, integrate over band, compute spectral density
```

### 7.5 Clock generation for digital characterization

A square wave at 1–10 MHz is useful for clocking external digital interfaces during characterization, or as a stimulus to a clock-recovery circuit for jitter measurement.

```python
awg.write('OUTP:IMP 50')              # 50 Ω back-termination for digital signal integrity
awg.write('SOUR:FUNC SQU')
awg.write('SOUR:FREQ 5000000')        # 5 MHz
awg.write('SOUR:VOLT 3.3')            # 3.3 V swing for CMOS receivers
awg.write('OUTP ON')
```

### 7.6 Bias-mode voltage injection

For applying a controlled voltage to a digital pin or high-impedance test point without risk of frying the DUT, switch to 10 kΩ output impedance and set a DC level. Fault current at any short is capped at V/10kΩ (e.g., 1 mA at 10 V), well below the input clamp-diode rating of any 3.3 V or 5 V CMOS digital input.

```python
awg.write('OUTP:IMP 10K')             # 10 kΩ current-limited mode
awg.write('SOUR:FUNC DC')
awg.write('SOUR:VOLT 2.5')            # 2.5 V DC bias
awg.write('OUTP ON')
```

## 8. Bill of Materials

Cross-referenced to Digi-Key (primary; Mouser was not accessible during this audit), with Microcenter for the Pico 2 W. Last verified May 2026.

| Item | Manufacturer P/N | Supplier | Supplier P/N | Qty | Unit Cost | Notes |
|---|---|---|---|---|---|---|
| Raspberry Pi Pico 2 W | Raspberry Pi SC1633 | Microcenter | SKU 687384 | 1 | $5.99 | RP2350 host MCU; Microcenter sale price |
| 12-bit 210 MSPS DAC | Analog Devices AD9742ARUZ | Digi-Key | AD9742ARUZ | 1 | $14.80 | 28-TSSOP, hand-solderable |
| Dual VFB op-amp 1400 V/µs | Analog Devices AD8056ARZ | Digi-Key | AD8056ARZ-ND | 1 | $6.27 | SOIC-8, channel A used; channel B reserved |
| Reed relay SPST-NO 5 V coil | Coto Technology 9007-05-01 | Digi-Key | 306-1004-ND (or current equivalent) | 3 | $2.09 | three for SP3T impedance switching |
| 2N3904 NPN BJT (relay driver) | onsemi 2N3904BU | Digi-Key | 2N3904FS-ND | 3 | $0.10 | TO-92, one per relay |
| 1N4148 small-signal diode (relay flyback) | onsemi 1N4148 | Digi-Key | 1N4148FSCT-ND | 3 | $0.05 | DO-35, one per relay |
| Precision resistor 25.0 Ω 0.1 % 0805 (DAC term) | Vishay PTN0805E25R0BST1 | Digi-Key | PTN0805E25R0BST1 | 2 | (verify direct) | 25 Ω matched pair across IOUTA/IOUTB |
| Precision resistor 50 Ω 1 % 0805 | Yageo RC0805FR-0750RL | Digi-Key | (verify direct) | 1 | ~$0.10 | 50 Ω output Z |
| Precision resistor 10 kΩ 1 % 0805 | Yageo RC0805FR-0710KL | Digi-Key | RC0805FR-0710KL | 1 | ~$0.10 | 10 kΩ output Z |
| FSADJ resistor 1.91 kΩ 0.1 % 0805 | Vishay TNPW08051K91BEEA | Digi-Key | (verify direct) | 1 | (verify direct) | sets AD9742 full-scale current |
| Reconstruction filter inductor 0.22 µH 0805 (L1/L5 per leg) | 0805 wirewound, Coilcraft 0805 family | Digi-Key | (search direct) | 4 | (verify direct) | singly-terminated Butterworth (finding D2) |
| Reconstruction filter inductor 0.68 µH 0805 (L3 per leg) | 0805 wirewound, Coilcraft 0805 family | Digi-Key | (search direct) | 2 | (verify direct) | singly-terminated Butterworth (finding D2) |
| Reconstruction filter cap 820 pF C0G 0603 ±5 % | Murata GCM/GRM C0G 0603 | Digi-Key | (search direct) | 4 | (verify direct) | two per leg (finding D2) |
| Op-amp gain network resistors 1 % 0805 | Yageo RC0805FR-07 series | Digi-Key | (verify direct) | 4 | ~$0.10 | R_in1, R_in2, R_fb, R_ref |
| Bypass cap 0.1 µF X7R 0603 50 V | Yageo CC0603KRX7R9BB104 | Digi-Key | 311-1366-1-ND (or equiv) | 10 | $0.08 | per IC supply pin |
| Bulk cap 10 µF X5R 0805 10 V | Yageo CC0805KKX5R8BB106 (or Murata GRM21BR71A106KA73L) | Digi-Key | (search direct) | 4 | (verify direct) | DAC, op-amp, +12V, -12V supply rails |
| Ferrite bead 0805 ~600 Ω @ 100 MHz (FB1, FB2) | 0805 ferrite bead | Digi-Key | (search direct) | 2 | (verify direct) | AVDD/DVDD supply filtering from chassis +3.3 V (Phoenix J1.5; findings D3/D4) |
| BNC panel-mount jack 50 Ω | Amphenol RF 031-5538 | Digi-Key | 031-5538 | 1 | (verify direct) | front-panel output |
| 3D-printed enclosure | n/a | n/a | n/a | 1 | ~$1 | PETG print, ~10 g |
| Hookup wire, headers, perfboard or custom PCB | various | various | various | n/a | TBD | full schematic in KiCad; PCB fab quote pending |
| **Module BOM total (verified portions, single-quantity Digi-Key/Microcenter)** | | | | | **~$53** | excludes PCB fab and items still pending direct verification |

Items marked "(verify direct)" are commodity passives and connectors whose prices were not extracted from Digi-Key's JS-rendered pages during the BOM audit. They are in stock at Digi-Key and individually cost less than $5; total impact on the module BOM is under $15.

## 9. Calibration Procedure

After module assembly, calibrate against a Fluke 87V (or equivalent calibrated DMM) and a 10 MHz GPSDO reference (or external function generator's calibrated output) using the following procedure.

### 9.1 DC offset calibration

1. Configure: `OUTP:IMP 50; SOUR:FUNC DC; SOUR:VOLT 0.0; OUTP ON`.
2. Wait for output to settle (1 s).
3. Measure the DC level on the output BNC with the Fluke 87V.
4. Adjust the op-amp's CMRR-trim resistor until the measured DC level reads within ±5 mV of 0 V (or store the offset as a software calibration constant).
5. Record via SCPI: `CALC:CAL:OFFS 0, <millivolts>`.

### 9.2 Gain calibration

1. Configure: `OUTP:IMP 50; SOUR:FUNC SIN; SOUR:FREQ 1000; SOUR:VOLT 10.0` (peak-to-peak).
2. Connect the output through a known-good 50 Ω terminator to a calibrated scope or Fluke and measure the actual peak-to-peak voltage.
3. Compute the gain error: `gain_correction = 10.0 / measured_pk_pk`.
4. Store: `CALC:CAL:GAIN 0, <gain_correction>`.

### 9.3 Frequency calibration

If the chassis trigger bus carries an external 10 MHz GPSDO reference, the firmware can phase-lock against it and update the frequency-divider constant accordingly. Without an external reference, the Pico's crystal is rated ±20 ppm, which is ±200 Hz at 10 MHz; for most characterization work this is below the tolerance of the DUT under test.

### 9.4 Reconstruction filter passband flatness

1. Sweep `SOUR:FREQ` from 1 kHz to 10 MHz at constant `SOUR:VOLT 1.0`.
2. Capture the peak-to-peak amplitude with Module 2E (or external scope) at each frequency.
3. Plot the magnitude response. The 5th-order Butterworth should show ≤ ±0.5 dB ripple across DC to ~10 MHz.
4. If the response shows excessive ripple (component tolerance issue), trim the filter inductors or substitute tighter-tolerance caps. Record the calibrated frequency response in the Pico flash so frequency-dependent corrections can be applied per the SCPI gain command.

## 10. Bring-Up Checklist

In order, on first power-up:

1. **Visual inspection.** Check polarity of every electrolytic and tantalum cap. Check op-amp orientation (notch toward pin 1). Check AD9742 pin 1 orientation. Check relay coil polarity. Verify no shorts between the parallel data bus and adjacent traces.
2. **Power-on without DUT.** Apply +5 V (Pico) and +12 V/−12 V (op-amp). Measure current draw: should be ~50 mA total at idle (Pico ~30 mA, AD9742 ~30 mA digital + 20 mA analog, AD8056 ~10 mA). If higher, pull power and find the short.
3. **Pico boots.** Watch the onboard LED; it should heartbeat. Pico USB enumerates as USB-TMC: `lsusb` on the host should show the PMVB device.
4. **DAC midscale test.** Send `SOUR:FUNC DC; SOUR:VOLT 0.0; OUTP ON`. With the Pico writing midscale codes (0x800) to the AD9742, IOUTA and IOUTB should each carry ~10 mA (half of FS_CUR ≈ 20 mA), giving a differential voltage of ≈ 0 V across the 25 Ω terminations. At the op-amp output, the reading should be 0 V ± 50 mV.
5. **Full-scale test.** Send `SOUR:FUNC DC; SOUR:VOLT 10.0; OUTP ON`. Pico drives the DAC to all-ones (0xFFF). Op-amp output should be near +10 V.
6. **Sweep test (audio band).** `OUTP:IMP 50; SOUR:FUNC SIN; SOUR:FREQ 1000; SOUR:VOLT 5.0; OUTP ON`. Output should be a 5 Vpp sine at 1 kHz on a scope, no visible distortion.
7. **Sweep test (HF band).** Repeat at 1 MHz and 10 MHz. Verify amplitude is within ±0.5 dB of the audio reading.
8. **Frequency response.** Sweep 20 Hz to 10 MHz and verify amplitude flatness within ±0.5 dB across the band.
9. **THD (audio band).** At 1 kHz, 1 Vrms output, capture with Module 2E and verify THD < 0.1 %.
10. **Spectral purity (HF band).** At 5 MHz, 1 Vrms output, capture with Module 2E and verify the first-image rejection is ≥ 40 dB. The first image should appear near the DAC update rate minus 5 MHz.
11. **Impedance switch test.** Cycle through `OUTP:IMP 50`, `OUTP:IMP HIZ`, `OUTP:IMP 10K`. For each, drive the DUT with a known voltage and measure source impedance with a known load.
12. **Calibration.** Run section 9 procedures. Save calibration constants to Pico flash.
13. **PyVISA-sim parity check.** Run the same SCPI command sequence against the simulator backend and verify behavior matches.

## 11. Known Issues and Future Work

(To be populated as the module is built.)

- The Pico's PIO + DMA can sustain 50 MSPS DAC update rate for short bursts, but sustained operation may require dropping to 30–40 MSPS. Characterize Pico bandwidth ceiling early in firmware bring-up; document the achievable update rate as a v1.0 specification.
- The AD9742 produces a small mid-scale glitch (datasheet specifies < 5 pV·s typical) at code transitions. For low-distortion audio work below 100 kHz this is well below the noise floor; for HF work it manifests as a small spurious tone at the DAC update rate. Mitigation is a careful reconstruction filter design.
- AD8056 channel B is unused in v1.0. A v1.1 enhancement could repurpose it as a stereo output (using a second AD9742) or as a buffered sync signal.
- The 5th-order Butterworth reconstruction filter component tolerances directly affect passband flatness. Initial builds may need tightened tolerance (1 % caps, 2 % inductors) on critical positions if the as-built ripple exceeds ±0.5 dB.
- A Tier 2 (FPGA-driven) variant of this module could push bandwidth to 50 MHz by replacing the AD9742 with a faster parallel DAC (AD9744 at 14-bit 210 MSPS) clocked from the Tang Primer 25K. That's a separate future module, not a v1.x evolution of this one.

## 12. References

- [Analog Devices AD9742 datasheet](https://www.analog.com/en/products/ad9742.html)
- [Analog Devices AD8056 datasheet](https://www.analog.com/en/products/ad8056.html)
- [Coto Technology 9007 series reed relay datasheet](https://www.cotorelay.com/product/9007-series/)
- [Raspberry Pi Pico 2 W datasheet](https://datasheets.raspberrypi.com/picow/pico-2-w-datasheet.pdf)
- [Analog Devices Application Note AN-282 (DAC reconstruction filters)](https://www.analog.com/en/resources/app-notes/an-282.html)
- [PMVB System Design Document, section 7.5.5](../system-design/System_Design_Document.html#module-1e-function-generator-arbitrary-waveform-generator)

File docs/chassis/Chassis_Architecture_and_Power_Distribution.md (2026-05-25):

# Chassis Architecture and Power Distribution Design Document

## v1.0 (May 2026)

Companion to the [PMVB System Design Document section 11](../system-design/System_Design_Document.html#power-architecture). This document defines the mechanical and electrical design of the PMVB chassis: an open-frame card-cage acrylic enclosure (4 panels laser-cut from SendCutSend, clamped by 4 M3 corner standoffs) housing the Silverstone SST-TX300 PSU as an analog-rail backbone, a GeeekPi D-1188 ATX breakout, a Sabrent HB-BU10 USB 3.0 hub as the chassis-internal USB-TMC backplane, and 14 module slots arranged as parallel vertical blades.

**Architecture in one paragraph.** The chassis is the integrated mechanical-and-power subsystem that holds the entire bench instrument fabric in a single ~17.1" × 9.4" × 3.6" footprint. The TX300 PSU supplies analog ±12 V and +5 V *only* to instrument modules that need clean bipolar or higher-current rails (Module 1B VMU, Module 1D SMU Lite, Module 1E AWG, Module 1F HV diff probe, Module 1G current probe, Module 1H DMM, Module 2B precision DAQ, Module 2E digitizer); it does **not** power the Pi 5, the USB hub, or chassis-side Picos, each of which has its own external supply (Pi 5 uses its 27 W USB-C charger, the Sabrent hub runs from its own wall brick, and module Picos draw 5 V from USB downstream power). Modules are vertical blades (16.3 × 125 × 86 mm body, FDM PLA / PETG via 3D-print service) that slot into the chassis at 22.5 mm pitch, plug into a 4-rail back-wall power harness via Phoenix Contact MC 1,5/4 connectors, and present USB to the Sabrent hub for SCPI command and measurement-data transport.

**v1.0 is open-frame.** The chassis has a floor, a ceiling, and two internal divider plates (the bottom and top groove plates with the module-slot through-cuts), but no side walls, rear wall, or front panel. Walls were dropped because the four corner standoffs handle structural rigidity on their own, and adding walls re-introduces TX300 thermal-management constraints (intake/exhaust airflow, vent geometry) that warrant their own design pass. **The walled chassis with explicit ventilation geometry is the v1.1 future enhancement** described in [section 9](#future-enhancements). Until then, the bench operator gets unrestricted visual and physical access to all chassis internals — TX300, GeeekPi breakout, USB hub, harness, and modules — from any side.

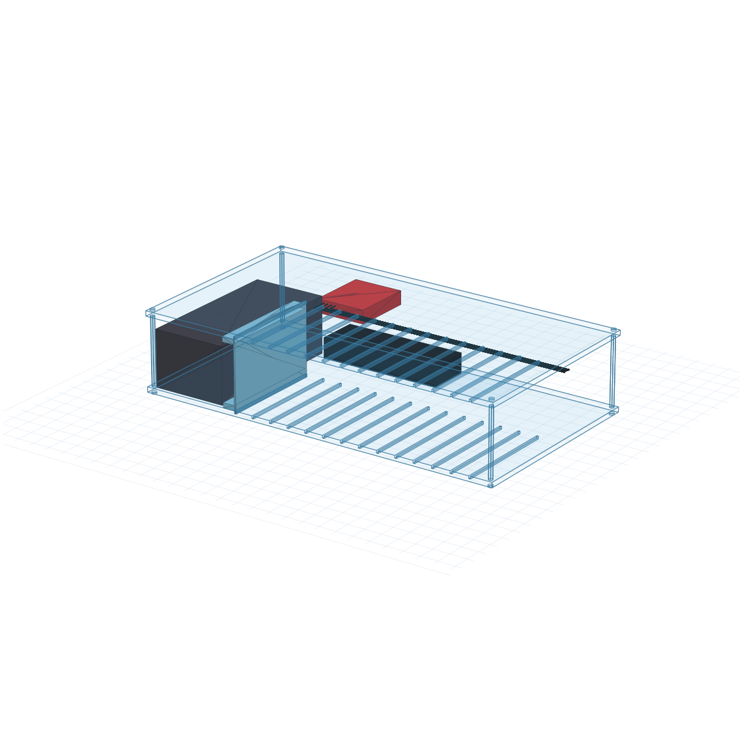
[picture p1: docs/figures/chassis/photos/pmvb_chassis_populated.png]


*Figure 1: PMVB chassis fully populated with 14 module blades (open-frame v1.0 card cage). The TX300 PSU sits at the left end of the chassis floor; the GeeekPi D-1188 ATX breakout sits on top of the TX300's rear ~20 mm; the Sabrent USB hub sits at the rear-center of the floor; modules occupy the right ~309 mm of the chassis at 22.5 mm pitch. Side walls, rear wall, and front panel are deferred to v1.1.*

---

## Table of Contents

- [1. Design Philosophy](#design-philosophy)
- [2. Functional Block Diagram](#functional-block-diagram)
- [3. Mechanical Architecture](#mechanical-architecture)
  - [3.1 Outer Envelope and Form Factor](#outer-envelope-and-form-factor)
  - [3.2 Acrylic Frame and Cuts](#acrylic-frame-and-cuts)
  - [3.3 TX300 PSU Mounting](#tx300-psu-mounting)
  - [3.4 GeeekPi D-1188 Mounting](#geeekpi-d-1188-mounting)
  - [3.5 Sabrent HB-BU10 USB Hub Mounting](#sabrent-hb-bu10-usb-hub-mounting)
  - [3.6 Module Slot Geometry and Form Factor](#module-slot-geometry-and-form-factor)
  - [3.7 Diagnostic Strip (deferred to v1.1)](#diagnostic-strip-deferred-to-v11)
  - [3.8 TX300 Fan Ventilation (v1.0 open-frame)](#tx300-fan-ventilation-v10-open-frame)
- [4. Electrical Architecture](#electrical-architecture)
  - [4.1 Rail Sources from the TX300](#rail-sources-from-the-tx300)
  - [4.2 GeeekPi D-1188 ATX Breakout](#geeekpi-d-1188-atx-breakout)
  - [4.3 Per-Rail Fuse Panel](#per-rail-fuse-panel)
  - [4.4 4-Wire Back-Wall Harness](#4-wire-back-wall-harness)
  - [4.5 Per-Module Phoenix Pigtail](#per-module-phoenix-pigtail)
  - [4.6 Banana-Jack Diagnostic Test Points](#banana-jack-diagnostic-test-points)
  - [4.7 Front-Panel Indicator LEDs](#front-panel-indicator-leds)
- [5. USB-TMC Backplane](#usb-tmc-backplane)
- [6. Bill of Materials](#bill-of-materials)
- [7. Bring-Up Procedure](#bring-up-procedure)
- [8. Safety Procedures](#safety-procedures)
- [9. Future Enhancements](#future-enhancements)
- [10. References](#references)

---

## 1. Design Philosophy

The chassis is an integrated single-enclosure subsystem that consolidates the analog supply backbone, the USB-TMC backplane, and the module bay into one bench-friendly footprint. Three architectural decisions drive the design:

1. **The TX300 PSU is the *analog-rail backbone*, not the chassis-wide power source.** Its ±12 V and +5 V outputs feed only the instrument modules that need clean bipolar or higher-current rails. Bench infrastructure (Pi 5, USB hub, the Picos at the chassis level) runs from external supplies. This decoupling means the chassis interior is exclusively SELV (safety extra low voltage) once mains is contained inside the TX300's certified case, and the chassis itself does not need to be a safety boundary.

2. **Modules are vertical blades in a card-cage-style bay.** Each module is a 17 × 125 × 80 mm PCB that slides into a slot at 22.5 mm pitch, plugs into a back-wall power harness, connects USB to the Sabrent hub, and presents its module-specific I/O at the front face. This pattern follows the spirit of NI PXI / Eurocard subracks at hobbyist scale, with a custom laser-cut acrylic frame replacing the cost-prohibitive professional subrack hardware.

3. **The chassis is open-frame acrylic.** The TX300's certified IEC inlet handles AC safety; the acrylic frame is purely mechanical containment and does not need to be earth-bonded. Open construction makes the architecture self-documenting (you can see what's inside), simplifies cooling (TX300 fan exhausts through a 6 × 12 grid of vent holes in the chassis top), and keeps fabrication cost under $100 for the entire enclosure.

---

## 2. Functional Block Diagram



*Figure 2: Chassis architecture as two parallel fabrics, with modules split by rail consumption. The analog power fabric (right column, red edges) runs from the TX300 IEC inlet through the TX300 PSU, GeeekPi D-1188 ATX breakout, per-rail fuse panel, and 4-wire back-wall harness — terminating only at the analog module group (×8: 1B, 1D, 1E, 1F, 1G, 1H, 2B, 2E). The USB-TMC control fabric (left and center columns, blue edges) runs from the Raspberry Pi 5 (external, not in chassis) over USB 3.0 to the Sabrent HB-BU10 USB hub (chassis backplane), then fans out as USB-A to both module groups: ×5 to digital modules (1A, 1C, 2A, 2C, 2D, USB-only consumers) and ×8 to analog modules. Three external supplies (Pi 5 charger and Sabrent hub brick shown dashed; TX300 IEC inlet shown solid because it terminates inside the chassis) feed the three top-level subsystems independently. Front-panel diagnostic strip (banana jacks + LEDs) is documented separately in §3.7 and §4.6/4.7.*

---

## 3. Mechanical Architecture

### 3.1 Outer Envelope and Form Factor

The v1.0 chassis is an **open-frame card cage** with envelope dimensions **435 × 238 × 92 mm** (~17.1" × 9.4" × 3.6"). Material is **3 mm cast acrylic** throughout, laser-cut from SendCutSend with the parts list described in [section 3.2](#acrylic-frame-and-cuts). The bench footprint is comparable to a 1U–2U rack-mount instrument.

**v1.0 is intentionally open-frame: no side walls, no rear wall, no front panel.** Four acrylic panels (floor, bottom groove plate, top groove plate, ceiling) clamped together by four M3 corner standoffs make up the entire mechanical structure. Modules slide into the chassis from any open side and engage the lip-and-groove card guides cut into the divider plates. The TX300 PSU, GeeekPi D-1188 breakout, and Sabrent HB-BU10 USB hub sit on the chassis floor and are accessible from all open faces during bring-up.

Walls were considered and dropped for v1.0 because the standoffs handle structural rigidity on their own and adding walls re-introduces TX300 thermal-management constraints (intake/exhaust airflow path, vent geometry) that are out of scope for the first build. **A walled chassis with explicit ventilation geometry is the v1.1 future enhancement** described in [section 9](#future-enhancements).

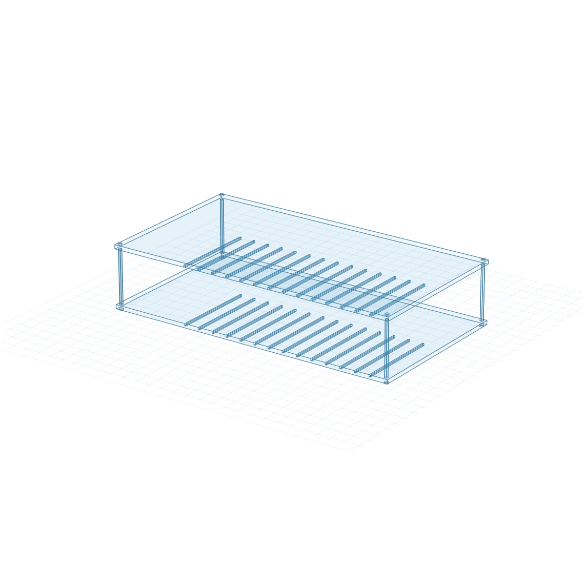
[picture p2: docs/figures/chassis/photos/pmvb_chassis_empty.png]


*Figure 3: Empty chassis (4-panel open-frame card cage). The 14 module slot grooves are visible across the bottom and top divider plates. The leftmost 10 mm reserves clearance for the front-left M3 corner standoff; the TX300 zone occupies x = 10..96 (86 mm); module slots span x = 100..409 (309 mm) at 22.5 mm pitch. With no walls, the TX300, GeeekPi breakout, and USB hub are visible from any side.*

The internal coordinate system used throughout this document: X is the long axis (chassis length, slot-pitch direction), Y is the depth axis (front to back), Z is the vertical axis (floor to ceiling). For consistency with the parametric DXF generator at `tools/fabrication/generate_prototype_v10.py`, the origin is at the chassis bottom-left corner with X spanning 0 to 420, Y spanning 0 to 238, and Z spanning 0 to 92.

### 3.2 Acrylic Frame and Cuts

The v1.0 frame is **four laser-cut pieces of 3 mm cast acrylic** (down from the six pieces a fully walled chassis would need). Cuts are produced parametrically by `tools/fabrication/generate_prototype_v10.py` and exported as separate per-panel DXF files (one part per file, per SendCutSend's nesting guidelines).

| Piece | Dimensions (mm) | Quantity | Cuts/features |
|---|---|---|---|
| Solid plate (floor and ceiling) | 435 × 238 × 3 | 2 | Four 3.4 mm M3 clearance holes at corner positions (5, 5), (430, 5), (5, 233), (430, 233) for the M3 corner standoffs; plus four 2.7 mm M2.5 clearance holes at (110.1, 161.6), (162.9, 161.6), (110.1, 225.4), (162.9, 225.4) for the GeeekPi mounting standoffs. The two solid plates are interchangeable; one becomes floor, one becomes ceiling. Only the ceiling actually uses the M2.5 holes; the four matching holes on the floor are intentionally unused but kept on both plates so SendCutSend treats them as one design at qty 2 (saves ~$70 in setup fees vs. quoting them as two unique parts). |
| Groove plate (bottom and top divider) | 435 × 238 × 3 | 2 | Same four M3 corner clearance holes; **14 lip-engagement through-cuts** at 22.5 mm pitch starting at x = 100 mm (each 2 mm wide × 125 mm long, running front-to-back along Y), accepting the 1.5 mm wide × 3 mm tall rail lips on each module body. The 0.5 mm width difference gives sliding clearance to accommodate FDM PLA dimensional tolerance. Plus four 2.7 mm M2.5 clearance holes at the same X,Y positions as the solid plates — only the top groove plate's M2.5 holes are actually used (for the GeeekPi standoff to pass through), but the bottom groove plate carries the same holes for the same setup-fee reason. |

DXF files are at `tools/fabrication/out/panel_solid_plate.dxf` and `panel_groove_plate.dxf`. Each file contains a single closed outer outline plus interior cutouts (circles for the M3 and M2.5 holes, rectangles for the slot grooves) wound clockwise so SendCutSend's interpreter reads them as holes rather than nested parts.

**Frame assembly** uses just **four M3 hex aluminum standoffs** plus eight M3 button head cap screws — no acrylic tapping required, no glue:

- 4× corner stacks, each built from 3× M3 × 20 mm M-F standoffs threaded together (each internal joint Loctite-243-locked) plus 1× M3 × 20 mm F-F at the top so the ceiling screw threads into a clean female socket. Total assembled stack length: 80 mm ±0.3 mm. One stack at each chassis interior corner; stack spans Z = 3 to Z = 89 (between the inside-top of the floor plate and the inside-bottom of the ceiling plate). Source: Csdtylh M3 320-piece assortment kit, Amazon B06Y5TJXY1 (kit contains 20× of each length, well over the 12 M-F + 4 F-F needed).
- 8× M3 × 8 mm button head cap screws (included in the same HVAZI kit). Four thread up through the floor's corner clearance holes into the bottom of each stack; four thread down through the ceiling's corner clearance holes into the top of each stack. No threadlocker on these so the chassis can be disassembled for v1.1.
- Acrylic panels each carry only clearance holes — no tapped threads. The standoff stack is the thread-bearing component; the acrylic is just a stack of plates sandwiched between the standoff ends.

The two groove plates sit between the floor and ceiling, held in place by the floor and ceiling sandwiching them and by the M3 corner standoffs passing through their corner holes. The bottom groove plate sits at Z = 3..6 (top face flush with the cavity floor at Z = 6); the top groove plate sits at Z = 86..89 (bottom face flush with the cavity ceiling at Z = 86). Module bodies span Z = 3..89, with their bottom rail lip engaged in the bottom groove plate's cutouts (Z = 3..6) and their top lip engaged in the top groove plate's cutouts (Z = 86..89).

The lip-engagement cutouts in the two groove plates form the card guides for module insertion. Each module's body has a 1.5 mm wide × 3 mm tall rail lip running along the bottom-right and top-right corners; these lips slide into the chassis groove cutouts (2.0 mm wide × 3 mm deep) as the module is inserted from any open side. The 0.5 mm width difference between groove and lip gives sliding clearance — modules can be inserted and removed without binding under FDM print and laser-cut tolerance variation.

### 3.3 TX300 PSU Mounting

The TX300 sits at the **left end of the chassis floor**, X = −230 to −144 (86 mm wide), Y = −118 to +60 (178 mm deep), Z = 6 to 72 (66 mm tall). Orientation: the TX300's IEC C14 inlet faces the chassis **front** (Y = −118 face) so the AC cord plugs in from the front; the TX300's 24-pin ATX output cable exits from the chassis **back** (Y = +60 face) and terminates at the GeeekPi D-1188 mounted on top of the rear portion of the TX300; the 80 mm fan exhausts upward through the top vent grille (Z = 72 top face). The PSU mounts to the floor plate via four M3 standoffs threaded into the TX300's existing M3 mounting holes (standard TFX form factor pattern).

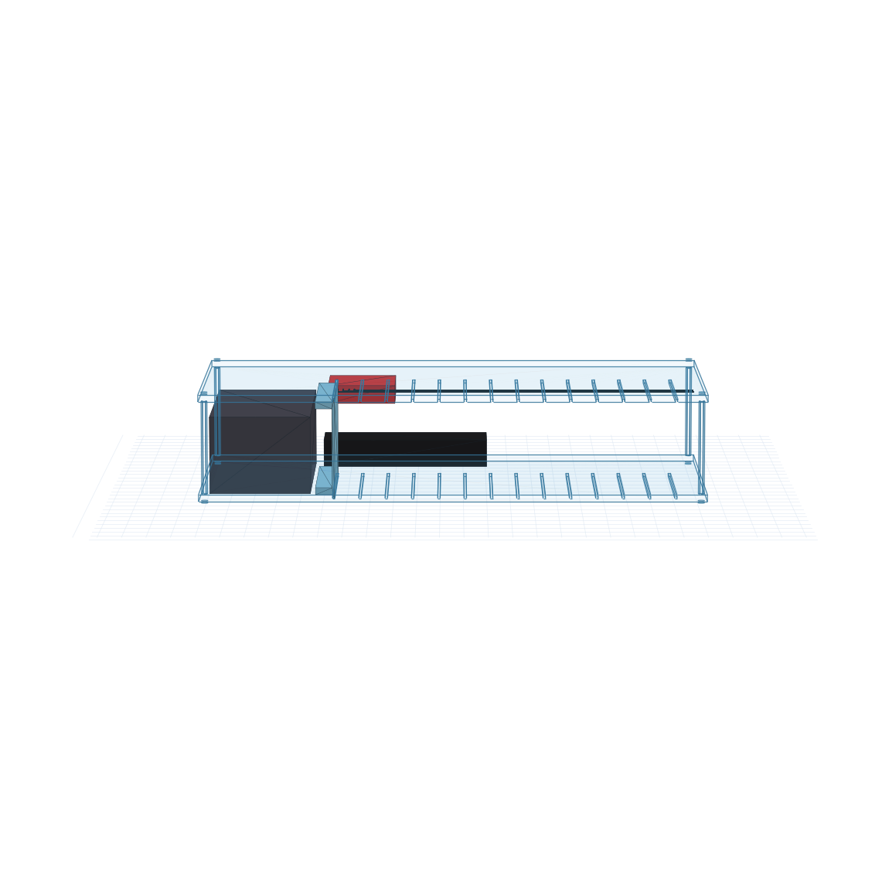
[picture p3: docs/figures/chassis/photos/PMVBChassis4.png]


*Figure 4: Cutaway view of the TX300 PSU (gray) and the GeeekPi D-1188 ATX breakout (red, on top of the TX300's rear ~20 mm) inside the chassis. The TX300's full top surface from the front edge to ~20 mm forward of the rear is left exposed for the fan to exhaust upward through the chassis top vent grid.*

Internal AC routing is contained entirely within the TX300's certified enclosure; no external mains wiring exits the PSU body. The IEC inlet is exposed through a 35 × 28 mm rectangular cutout in the **front** panel at the TX300 IEC inlet position (occupying the leftmost ~90 mm of the front-panel face, separate from the diagnostic strip and module faceplate region).

### 3.4 GeeekPi D-1188 Mounting

The GeeekPi D-1188 ATX breakout (70 × 58.5 × 15.9 mm) **hangs from the chassis ceiling** above the rear-center of the chassis, with its mounting positions at X = 107..166, Y = 158.5..228.5, Z = 65..81. The breakout's component-side faces down (into the chassis interior) so the screw terminals point downward and the 24-pin ATX header is accessible from below for the cable run from the TX300. The breakout is rotated 90° from its as-marked orientation so the power-rail status LEDs face the chassis rear and the screw terminals face the chassis front.

The breakout mounts via four M2.5 × 6 mm female-female hex aluminum standoffs that hang from the underside of the top groove plate, with M2.5 × 8 mm button head cap screws coming from above the chassis ceiling, passing through the ceiling (3 mm) and the top groove plate (3 mm), threading into the standoff. The standoffs hold the GeeekPi PCB top face at Z = 80, with the underside of the top groove plate at Z = 86, giving 6 mm of clearance for solder bumps and the standoff body. Source: HVAZI M2.5 160-piece assortment kit, Amazon B01L06CUJG (kit's shortest length is 6 mm; the extra 1 mm vs the original 5 mm spec is harmless added clearance). The four mounting holes are at:

| Hole | X (mm) | Y (mm) |
|---|---|---|
| Front-left | 110.1 | 161.6 |
| Front-right | 162.9 | 161.6 |
| Rear-left | 110.1 | 225.4 |
| Rear-right | 162.9 | 225.4 |

These holes are cut as 2.7 mm clearance holes (M2.5 normal clearance) in both the ceiling plate and the top groove plate (see [section 3.2](#acrylic-frame-and-cuts) for the panel detail). The GeeekPi's own mounting holes are 2.5 mm and accept M2.5 screws directly (no drill-out needed).

This positioning gives the breakout's screw terminals a clean run forward and downward to the back-wall harness, and leaves the TX300 top entirely free for the fan to exhaust upward into the open chassis cavity.

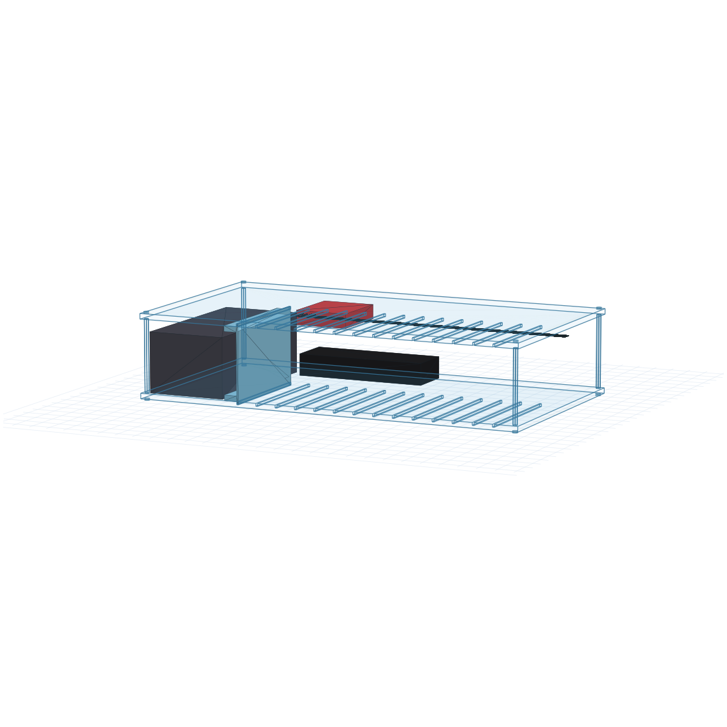
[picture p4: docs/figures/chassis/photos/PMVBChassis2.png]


*Figure 5: View of the chassis interior with the TX300 (left, gray), Sabrent USB hub (rear-center), GeeekPi D-1188 (rear-center, hanging from ceiling above the Sabrent hub), and 14 module blades slotted into the bay. The GeeekPi is rotated 90° so its screw-terminal blocks face the chassis front (where the back-wall harness lives) and its status LEDs face the chassis rear.*

### 3.5 Sabrent HB-BU10 USB Hub Mounting

The Sabrent HB-BU10 (144.8 × 48.3 × 23.9 mm) sits at the **rear-center of the chassis floor**, X = 102.6..247.4 (145 mm), Y = 175.4..223.7 (48 mm), Z = 6..29.9 (24 mm tall). The hub mounts to the floor plate via two M3 × 6 mm screws threaded into adhesive-backed standoffs (the hub doesn't have factory mounting holes; we attach standoffs with VHB tape to the hub bottom, then bolt those down). For the v1.0 prototype phase, the hub can be retained by a strip of 3M VHB tape directly to the chassis floor without standoffs.

The hub's 10 USB-A downstream ports face **forward** (toward Y = 0, the open front of the chassis) so each downstream port can run a short USB-A-to-micro-USB cable rearward to the corresponding module's rear-edge Pico micro-USB connector. The modules occupy Y = 0..125, the hub at Y = 175.4 sits 50 mm behind the rearmost module edge — easily handled by 100-150 mm pre-built USB-A-to-micro-USB cables. The hub's uplink (USB 3.0 Type-A) and DC barrel input cables pass freely from the rear of the open-frame chassis since v1.0 has no rear wall.

### 3.6 Module Slot Geometry and Form Factor

The module bay occupies the right ~3/4 of the chassis floor: **14 slots at 22.5 mm pitch**, X centers at −132, −110, −87, −64, −42, −20, +3, +26, +48, +70, +93, +116, +138, +160.

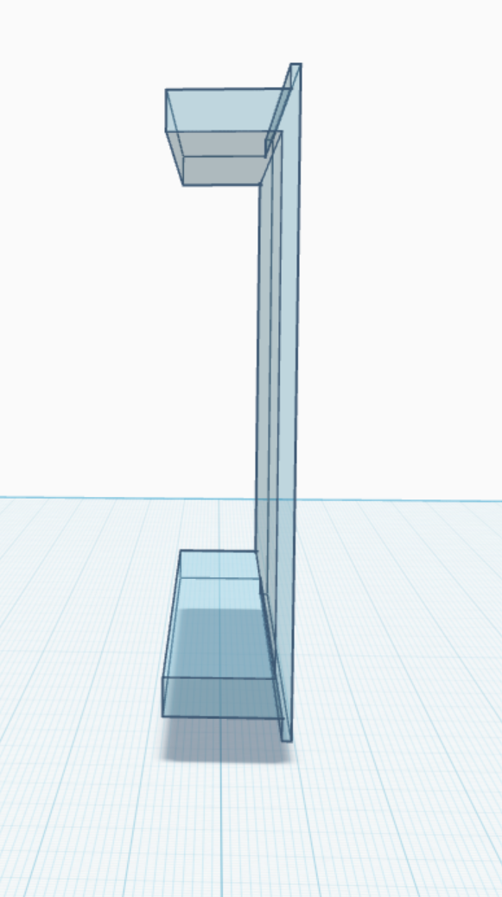
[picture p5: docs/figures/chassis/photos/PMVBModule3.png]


*Figure 6: Side profile of a single module body. The C-shape cross-section is clearly visible: closed top and bottom shells, closed right wall, open left face. The two extensions at the top-right and bottom-right corners are the 1.5 mm × 3 mm rail lips that engage the chassis bottom and top groove plates (cut with 2.0 mm wide × 3 mm deep through-cuts, giving 0.5 mm sliding clearance). The host PCB mounts vertically against the cavity right wall and components extend leftward through the cavity and into the inter-module gap, giving 21.5 mm of stack budget per slot.*

**Module body envelope (v10).** Each module body is **16.3 × 125 × 86 mm** outer (lips included in the 86 mm height), fabricated as a single 3D-printed FDM PLA part with a C-shape cross-section:

- **6 mm thick top and bottom shells** running the full 125 mm depth. Body proper (between the two shells, excluding the rail lips) is 80 mm tall (Z = 3 to Z = 83 in module coordinates).
- **2.0 mm thick right wall** (closed) connecting top and bottom shells. This wall thickness meets JLCPCB's FDM minimum for the 100 × 100 mm wall-area class.
- **1.5 mm × 3 mm rail lips** at the top-right and bottom-right corners, extending the full 125 mm depth. The 1.5 mm width meets JLCPCB's ≥1.5 mm protrusion rule for FDM. These lips engage the chassis bottom and top groove-plate through-cuts (2.0 mm wide × 3 mm deep, giving 0.5 mm sliding clearance to accommodate FDM dimensional tolerance).
- **Open left face** — the module's left side has no shell. This is intentional and structural: it widens the effective component-stack budget per slot from 12 mm (a fully closed cavity) to 21.5 mm (cavity plus the 6 mm inter-module gap shared with the adjacent module's open face).

Each module's body sits at Y = 3 (front edge) to Y = 128 (rear edge), Z = 3 (bottom lip engages bottom groove plate from Z = 3 to Z = 6) to Z = 89 (top lip engages top groove plate from Z = 86 to Z = 89). In chassis coordinates the module body proper occupies Z = 6 to Z = 86 (the 80 mm cavity zone between the two groove plates), with the 3 mm lips above and below this range.

**Internal cavity** is 14.3 × 125 × 68 mm (cavity X = 0 to 14.3 inside the 2.0 mm right wall, Y = full 125 mm depth, Z = 9 to 77 in module coordinates between the 6 mm top and bottom shells).

**v10 module geometry was revised on 2026-05-09** from the earlier v9 spec (0.6 × 3 mm lips, 1.5 mm right wall, 0.4 mm sliding clearance) after JLCPCB's FDM design guidelines were verified. The v9 geometry violated four FDM rules at once: lip width below the 1.5 mm protrusion minimum, lip width below the 1.0 mm embossed-detail minimum, ±0.3 mm tolerance dwarfing the 0.6 mm feature size, and 0.4 mm sliding clearance under the 0.5 mm minimum for moving parts. v10 hits all four rules with margin.

**Component stack budget per module: 21.5 mm.** Because every module's left face is open and every module follows the same orientation (lip-on-the-right), components on each module's PCB can extend leftward from the module's own cavity right wall (x = +7) all the way to the adjacent module's right wall outer edge (x = neighbor + 8.2 = this − 14.3 mm). The 0.6 mm rail lip on the adjacent module is above and below the cavity Z range and does not reduce the middle-cavity X budget. This is why we can fit headered Pico stacks (14.2 mm) and direct-soldered Pico stacks (6.2 mm) plus analog circuitry on the same side of the host PCB.

**Module mount convention (mandatory across all modules):** each module's host PCB is mounted vertically against the cavity right wall (PCB plane parallel to the chassis YZ plane, PCB normal pointing leftward into the cavity). All components are placed on the cavity-facing (left-pointing) face of the PCB. No components on the back face of the PCB (which is pressed against the right wall). This convention is what makes the 21.5 mm stack budget achievable — without it, adjacent modules could collide in the inter-module gap.

**Connector positions on the host PCB:**

- **Pico micro-USB:** rear edge of the PCB, pointing rearward (+Y direction). The Pico 2 W is mounted near the rear half of the PCB with its long axis running along Y so its micro-USB connector lands on the rear PCB edge. A short USB-A-to-micro-USB cable runs straight rearward to one of the Sabrent HB-BU10's downstream ports.
- **Phoenix MC 1,5/4-G (1803293):** top edge near the rear corner, pointing upward (+Z direction). When the module is fully seated, the chassis's per-slot Phoenix MC 1,5/4-ST plug from the back-wall harness drops down onto this header from above (the harness wires run at Z ≈ 76, just 5 mm above the top edge of the module body's top shell at Z = 86 minus 5 mm shell = effectively at the top of the cavity).
- **Faceplate connectors:** front edge, fitting within ~17 mm wide × 80 mm tall front-face real estate per slot.

### 3.7 Diagnostic Strip (deferred to v1.1)

**v1.0 ships without the chassis-level diagnostic strip.** With the open-frame chassis, the bench operator has direct unobstructed access to the fuse panel terminals on the chassis floor and can clip a DMM probe onto each rail there for spot-checks during bring-up. The fuse cap itself is also visible from above, providing an at-a-glance blown-fuse indicator that supplants the rail-status LEDs. The 4 banana jacks (Pomona 3760 color-coded) and 3 LED indicators (VCC 5102H rail status) that would have populated this strip are deferred to v1.1, where they migrate onto the actual front panel alongside the per-module faceplate cutouts (see §9.2).

**Module front-panel cutouts:** with no chassis front panel, each module's front-edge faceplate I/O sits exposed in v1.0. Each module body's front face (Y = 3 in chassis coordinates) carries the module-specific connectors directly. This is acceptable for bring-up and bench operation; v1.1 will add a chassis front panel with per-module cutouts to restore a finished look once each module's faceplate I/O converges.

### 3.8 TX300 Fan Ventilation (v1.0 open-frame)

The TX300's 80 mm fan exhausts upward (Z = +72 face, the top of the PSU). With no chassis ceiling above the TX300 in v1.0, the fan exhausts directly to room air through the open chassis top — no vent grid needed. (The ceiling plate covers the right portion of the chassis above the module zone, but the leftmost 86 mm of chassis width — the TX300 zone — has the ceiling plate optionally cut back or simply offset away from the TX300 footprint.)

The current fabrication has the ceiling plate spanning the full 435 × 238 mm footprint with no vent holes cut, on the assumption that with no side walls or rear wall to contain the airflow, the TX300 fan can pull intake air in from any open side and exhaust through the ~17 mm clearance between the TX300 top face (Z = 72) and the chassis ceiling underside (Z = 89). This vertical gap plus the open sides gives ample airflow path under v1.0.

**v1.1 will need explicit ventilation geometry** because adding side walls and a rear wall closes off the intake path. See [section 9 Future Enhancements](#future-enhancements).

---

## 4. Electrical Architecture

### 4.1 Rail Sources from the TX300

The TX300 provides the standard ATX rails at its 24-pin output: +3.3 V, +5 V, +12 V, −12 V, +5 V Standby, GND. PMVB uses only +5 V, +12 V, −12 V, and GND from this set; +3.3 V and +5 V Standby are not routed forward of the GeeekPi breakout. Per-rail current capacity (per the TX300 datasheet): +5 V at 14 A, +12 V at 22 A, −12 V at 0.3 A. The −12 V rail's 0.3 A budget bounds how many op-amps can be powered simultaneously across all modules; current planning expects worst-case ~150 mA combined across all v1.0 + v1.1 op-amp modules, comfortably within budget.

### 4.2 GeeekPi D-1188 ATX Breakout

The GeeekPi D-1188 (Amazon B08MC389FQ, ~$13) takes the TX300's 24-pin ATX cable as input and exposes each rail on a screw terminal. Features used:

- **PS_ON# slide switch** on the breakout PCB. This is the master enable for the TX300's main rails. With the switch off, only +5 V Standby is alive (which we don't use externally); with the switch on, all rails come up. There is no chassis-level master toggle; the GeeekPi's onboard switch is accessed through the open frame.
- **Per-rail status LEDs** on the breakout PCB. These show +5 V Standby, +3.3 V, +5 V, +12 V, −12 V, PS_ON, and PWROK status. The chassis also has separate front-panel LED indicators (section 4.7) for at-a-glance visibility, but the breakout's onboard LEDs are useful for diagnosing PSU faults during bring-up.
- **Screw terminals** for +5 V, +12 V, −12 V, GND. From these, short hookup wires carry the rails to the per-rail fuse panel. **Pre-fuse jumpers are sized for the TX300 source maximum, not the downstream fuse**: 12 AWG for +5 V (14 A source max) and +12 V (22 A source max); 22 AWG for −12 V (0.3 A source max). The fuse cannot protect the wire upstream of itself, so the pre-fuse wire must be rated for the worst case the source can deliver into a downstream short. Keep these jumpers as short as physically possible (50-100 mm) by mounting the fuse panel adjacent to the GeeekPi.

### 4.3 Per-Rail Fuse Panel

Each rail passes through a panel-mount glass-cartridge fuse before reaching the back-wall harness. Fuses provide a fast-failure path independent of the breakout's onboard polyfuses (which reset themselves and don't visibly indicate a fault). The fuse panel is a small perfboard or terminal-block strip mounted to the chassis floor directly in front of the GeeekPi (X ~= 107..167, Y ~= 110..155, Z floor) so the pre-fuse 12 AWG jumpers from the GeeekPi screw terminals stay under 100 mm.

**Fuse sizing rationale.** The fuse rating is set to the expected worst-case operating load with margin, **not** to the TX300's source capacity. A fuse exists to interrupt fault current (short circuit, runaway), so it must (a) pass normal operating current without nuisance-tripping and (b) trip quickly on fault current. Sizing at or near the source max would force a >10 A short before tripping; sizing just above the expected load lets even small downstream faults trip the fuse fast.

| Rail | TX300 source max | Expected PMVB load | Fuse rating | Headroom |
|---|---|---|---|---|
| +5 V | 14 A | ~2-3 A (8 analog modules, ADC refs and analog supplies at 200-300 mA each) | 5 A slow-blow | ~60% utilization |
| +12 V (combined +12V1 + +12V2) | 22 A | ~1-2 A (op-amp rails at 100-200 mA each across 8 analog modules, plus dynamic load for 1D SMU and 1E AWG drive) | 3 A slow-blow | ~50-70% utilization |
| −12 V | 0.3 A (limited at the source) | ~150-200 mA (~20 mA op-amp quiescent per rail per module) | 500 mA slow-blow | ~30-40% utilization |

The TX300 itself has internal ATX overcurrent protection that shuts down the entire PSU if any rail exceeds its rated max. The chassis-side fuses are additive protection that buys three things on top:

1. **Per-rail isolation.** A short on +12 V trips only the +12 V fuse; +5 V and −12 V stay alive so the bench keeps running for whatever else is on those rails. Without the chassis fuses, the TX300 OCP would shut down all rails together.
2. **Finer-grained fault detection.** A fault pulling ~5-10 A on +5 V trips the chassis fuse but is well under the TX300's 14 A OCP threshold and would otherwise persist. Smaller faults catch faster.
3. **Visible fault indication.** A blown cartridge is visible through the holder cap and the rail-status LED on the diagnostic strip goes dark, so the operator immediately knows which rail failed.

**Fuse selection details:**

| Rail | Fuse rating | Fuse holder | Fuse cartridge |
|---|---|---|---|
| +5 V | 5 A slow-blow | Eaton BK/HTB-22M-R | Bel BK1/GMC-5-R |
| +12 V | 3 A slow-blow | Eaton BK/HTB-22M-R | Bel BK1/GMC-3-R |
| −12 V | 500 mA slow-blow | Eaton BK/HTB-22M-R | Bel BK1/GMC-500MA-R (or equivalent) |

A blown fuse is visible through the holder cap and replaceable without disassembly; the holder accepts standard 5 x 20 mm cartridges.

**GND is not fused** — return paths are never fuse-protected. The GND wire runs directly from the GeeekPi GND terminal to the back-wall harness GND rail, bypassing the fuse panel.

**If bring-up reveals higher actual loads** than estimated above, the fuse rating can be bumped up. Section 7.2 step 10 ("verify rail voltages") is the natural point to also measure actual rail current with a clamp or shunt; if for example Module 1E AWG turns out to pull 4 A peak on +5 V during inrush, replace the 5 A cartridge with a 7 A or 10 A slow-blow. The 12 AWG pre-fuse and 14 AWG post-fuse wire is rated well above any fuse value you would realistically pick (12 AWG is 41 A free-air, 14 AWG is 32 A), so the fuse rating can grow without re-pulling the wire.

### 4.4 4-Wire Back-Wall Harness

After the fuse panel, each rail (+5 V, +12 V, −12 V, GND) runs as a 14 AWG stranded wire along the upper-rear region of the chassis interior, at approximately Z = 76 (10 mm below the chassis ceiling) and Y = 14 to 34 (35 mm forward of the back wall). The four wires run parallel along the X axis, ~303 mm long, spanning from just past the GeeekPi's screw terminals (X ≈ −142) to past the rightmost module slot (X ≈ +161). Post-fuse wire is sized for the fuse-limited current (5 A / 3 A / 0.5 A), not the TX300 source max, since a downstream short trips the fuse before the wire can overheat. 14 AWG is electrically overkill for the highest-fused rail (+5 V at 5 A) but is the dominant gauge for Wago 221-413 and Phoenix MC 1,5/4 compatibility, and its stiffness helps the harness hold shape across the back wall.

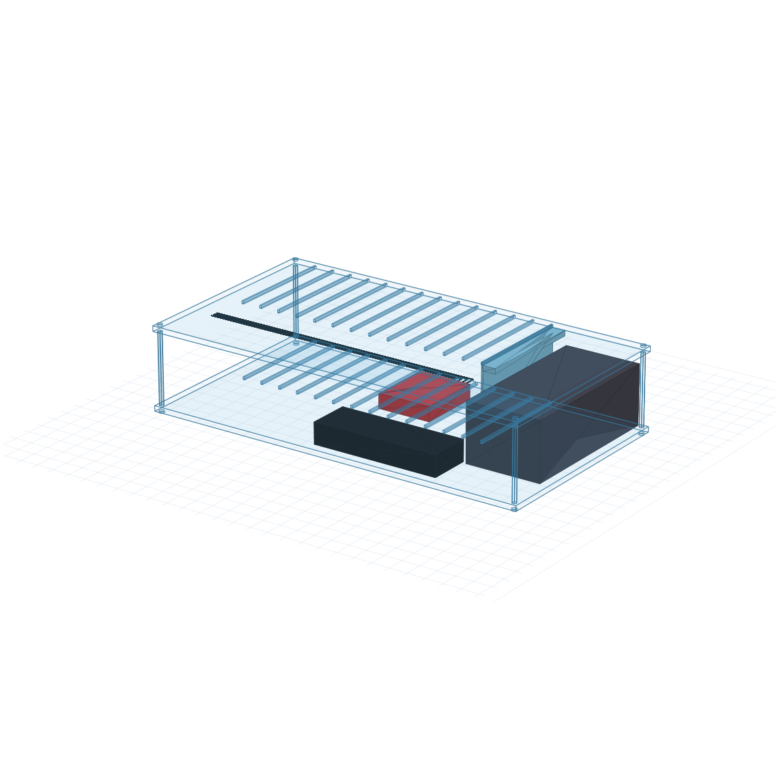
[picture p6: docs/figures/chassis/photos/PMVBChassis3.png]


*Figure 7: View of the chassis from above-rear, showing the 4-wire back-wall harness (orange) running parallel across the upper-rear region of the chassis interior. The four wires originate at the GeeekPi D-1188 (red, far right, on top of the TX300) and run leftward across the entire module bay, with one Phoenix MC 1,5/4 plug per slot tapping into the rails at each module's X position. The translucent module bodies show the slot pitch and the open-left-face geometry that gives each module access to the harness.*

At each module slot's X position, the harness terminates at a Phoenix MC 1,5/4-ST plug (Phoenix 1803594, Digi-Key 277-1163-ND, ~$8.73 each). The four wires are screwed into the plug's terminals in fixed order: pin 1 = +5 V (red wire), pin 2 = +12 V (yellow), pin 3 = −12 V (blue), pin 4 = GND (black). Wire colors follow lab convention.

The plug clips downward onto the module's PCB-mounted Phoenix MC 1,5/4-G header (Phoenix 1803293, Digi-Key 277-1208-ND, ~$3.51 each), which sits on the top edge near the rear corner of the host PCB with its pins facing upward (+Z direction). With the harness wires at Z ≈ 76 and the module top edge at Z ≈ 80–86, the plug-to-header mating runs perpendicular to the PCB plane, making module insertion and removal a vertical-down + horizontal-back motion. Plug body height is ~12 mm; cable strain relief adds another ~10 mm of Z consumption above the harness wire position, both well within the chassis ceiling clearance.

### 4.5 Per-Module Phoenix Pigtail

Each populated slot uses one Phoenix MC 1,5/4-ST plug terminating a short pigtail of 4 stranded wires (~30 mm long) tapping into the back-wall harness. **For the v1.0 prototype phase, taps are made with Wago 221-413 3-port lever-nut connectors** (Mouser 651-221-413, ~$0.34 each, 4 per slot). For each rail at each tap point: bus IN goes into one Wago port, bus OUT goes into another, and a short pigtail to the Phoenix plug pin goes into the third. No stripping or crimping required for the bus wires; just trim the pigtail to length, push the lever, insert, close.

Empty slots (no module installed) skip the Wago entirely — the bus wire is one continuous run with no break. When a new module is added, the user cuts the bus at the slot's X position, inserts the cut ends and a fresh pigtail into a Wago, and continues.

**v1.1+ option:** replace the Wago lever-nuts with a custom **4-rail distribution PCB** mounted along the back wall. The PCB has one 4-pin Phoenix input header (from the GeeekPi feed) and 14 4-pin Phoenix output headers at 22.5 mm pitch matching the module slot pitch, with internal copper traces connecting all the same-rail pins. This eliminates the lever-nut bulk and gives a single-point harness attachment. JLCPCB fabrication is roughly $10 for 5 pieces in a 1-2 week turnaround. The distribution PCB is deferred from v1.0 because Wago lever-nuts let you re-route taps freely during chassis bring-up; once the layout is verified, the PCB locks it in.
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

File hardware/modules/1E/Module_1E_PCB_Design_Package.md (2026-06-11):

# Module 1E PCB Design Package

**Module:** 1E Function Generator / AWG **Version:** v0.5 (June 2026)
**Parent docs:** [Module 1E Design Document v1.7](../../../docs/modules/Module_1E_Design_Document.html),
PMVB System Design Document section 7.5.5
**Status:** all findings D1-D7 resolved (incl. the D2 filter synthesis and the D6 Phoenix P/N); KiCad project setup and schematic capture pending (you, in KiCad GUI). See `Module_1E_KiCad_Build_Guide.md`.

This package is the bridge between the Module 1E Design Document (theory,
block diagram, BOM) and a laid-out KiCad board. It carries the engineering
decisions the design document left open or stated inconsistently, the
connectivity intent the schematic must realize, the placement floorplan, the
layer stackup, and the design rules.

Schematic capture and board layout happen visually in the KiCad GUI; the
companion documents in this folder are the spec you build the project against.

---

## 1. What is in this folder
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

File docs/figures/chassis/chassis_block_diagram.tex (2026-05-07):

% =============================================================================
% Chassis functional block diagram (PMVB v1.0)
% =============================================================================
% Shows the chassis architecture as two parallel fabrics + the analog/digital
% module split:
%
%   1. ANALOG POWER fabric (right column):
%        TX300 IEC -> TX300 PSU -> GeeekPi D-1188 -> per-rail fuses
%        -> 4-wire back-wall harness -> ANALOG modules only
%
%   2. USB-TMC CONTROL fabric (left/center columns):
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

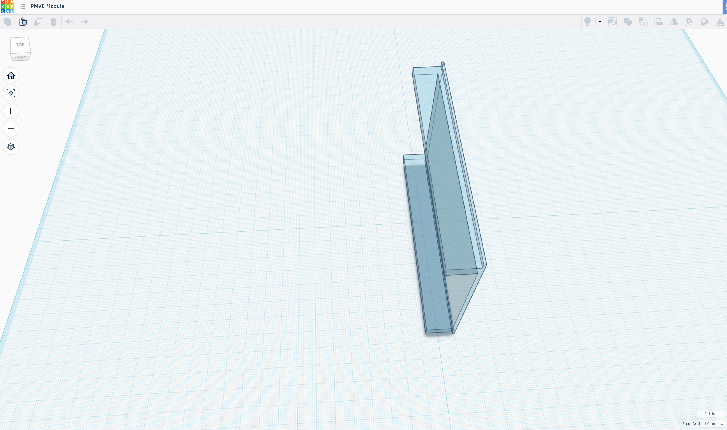
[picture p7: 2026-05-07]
docs/figures/chassis/photos/PMVBModule2.png

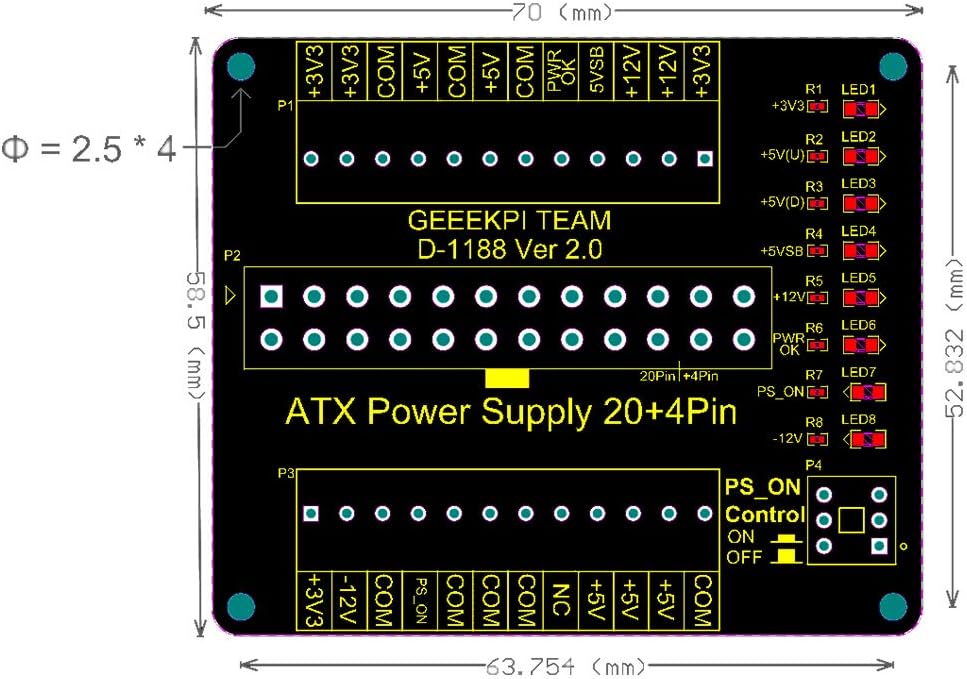
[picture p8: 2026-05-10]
docs/figures/chassis/datasheets/GeeekPi_D-1188_dimensions.jpg

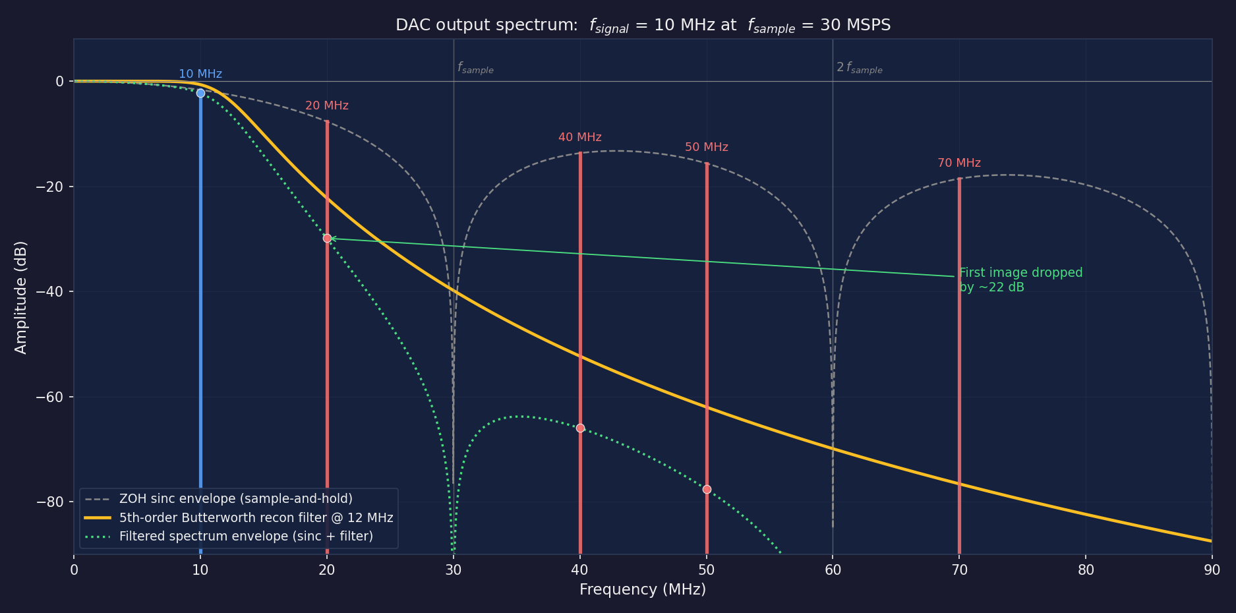
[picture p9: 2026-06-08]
docs/figures/modules/1e_dac_spectrum_30msps.png

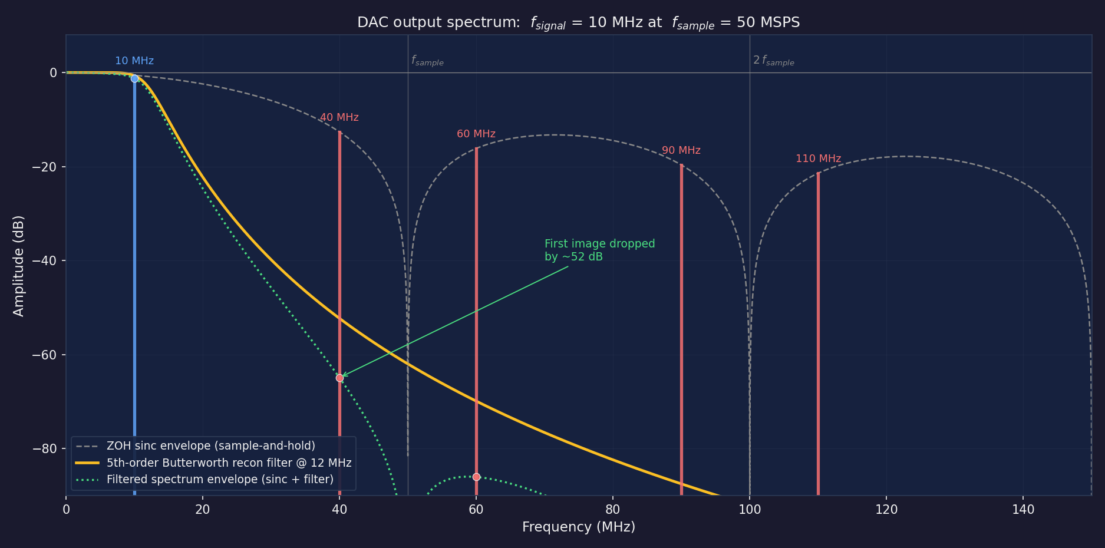
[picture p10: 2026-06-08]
docs/figures/modules/1e_dac_spectrum_50msps.png

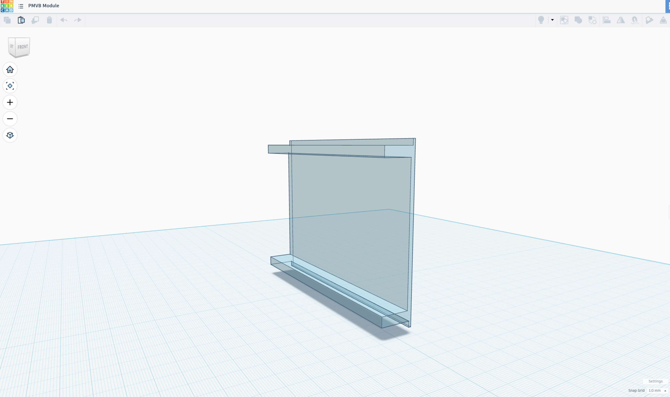
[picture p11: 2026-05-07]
docs/figures/chassis/photos/PMVBModule1.png

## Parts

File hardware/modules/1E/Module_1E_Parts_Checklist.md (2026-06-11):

# Module 1E Parts Checklist

One-time prep before schematic capture. Goal: end up with a project-local
KiCad library that holds every custom symbol + footprint + 3D model the
Module 1E board needs. Generic passives (R, C, L, ferrite bead) and a few
common discretes come from KiCad's standard libraries and skip this list.

Source for the custom parts: Component Search Engine
(<https://componentsearchengine.com>), Library Loader output configured for
KiCad. Each bundle is a `.kicad_sym` + `.pretty/` footprint dir + `.step`.

## Project library layout

Create this directory tree under the KiCad project root once:

```
hardware/modules/1E/kicad/
  module_1e.kicad_pro
  module_1e.kicad_sch
  module_1e.kicad_pcb
  lib/
    PMVB_1E/
      symbols/         <- .kicad_sym files dropped here
      footprints.pretty/  <- .kicad_mod files dropped here
      3dmodels/        <- .step files dropped here
```

Add the library to the KiCad project (steps in `Module_1E_KiCad_Build_Guide.md`,
section "Library setup"). Use **project-local scope**, not global, so the
library travels with the repo.

---

## Custom parts to fetch from Component Search Engine

Five custom parts. For each: open the CSE URL, pick the KiCad output, run
Library Loader (or download the zip), unpack the three files into the
matching subfolder of `lib/PMVB_1E/`.

### 1. AD9742ARUZ - 12-bit 210 MSPS DAC, 28-lead TSSOP

- **Manufacturer:** Analog Devices
- **MPN:** `AD9742ARUZ`
- **CSE:** <https://componentsearchengine.com/part-view/AD9742ARUZ/Analog%20Devices>
- **Fetch:** symbol + footprint (TSSOP-28) + 3D STEP.
- **Notes:** Pinout is the verified one from D5 of the design package. Pin 23
  RESERVED must remain unconnected (do not stub to GND in the schematic).
  Pin 25 MODE is a data-format strap (DCOM for straight binary), not a
  parallel/serial select.

### 2. AD8056ARZ - dual 1400 V/us op-amp, SOIC-8

- **Manufacturer:** Analog Devices
- **MPN:** `AD8056ARZ`
- **CSE:** <https://componentsearchengine.com/part-view/AD8056ARZ/Analog%20Devices>
- **Fetch:** symbol + footprint (SOIC-8) + 3D STEP.
- **Notes:** Channel A is the live signal path. Channel B is unused: tie +INB
  to GND, tie -INB to OUTB to terminate it as a unity follower (per design
  package, OpAmp sheet).

### 3. Raspberry Pi Pico 2 W - 40-pin RP2350 module

- **Manufacturer:** Raspberry Pi
- **MPN:** `SC1633` (also listed as "Raspberry Pi Pico 2 W")
- **CSE:** <https://componentsearchengine.com/part-view/SC1633/Raspberry%20Pi>
  (if CSE doesn't have it, SnapEDA or the official Raspberry Pi KiCad
  library at <https://github.com/raspberrypi/hardware-design-guide> is the
  fallback)
- **Fetch:** symbol + footprint (40-pin, 2x20 castellated + THT, 2.54 mm
  pitch, 17.78 mm row pitch) + 3D STEP.
- **Notes:** On Module 1E, VBUS (pin 40) and VSYS (pin 39) are left
  unconnected on the PCB; the Pico is powered through its own micro-USB
  cable. 3V3_OUT (pin 36) feeds the DAC supply island.

### 4. Coto 9007-05-01 - SPST-NO reed relay, 5 V coil

- **Manufacturer:** Coto Technology
- **MPN:** `9007-05-01`
- **CSE:** <https://componentsearchengine.com/part-view/9007-05-01/Coto%20Technology>
- **Fetch:** symbol + footprint + 3D STEP.
- **Notes:** Three instances (K1, K2, K3) for the 50 ohm / high-Z / 10 kohm
  impedance switch. Verify the four pin positions (two coil, two contact)
  against the Coto datasheet after import.

### 5. Phoenix Contact MC 1,5/5-G-3,81 right-angle pluggable PCB header (1803303)

- **Manufacturer:** Phoenix Contact
- **MPN:** `1803303` (MC 1,5/5-G-3,81). RESOLVED per D6: the 5-position
  right-angle header (TME spec table "angled 90 deg", 5 pins, 8 A), now
  carrying +3.3 V on pin 5 in addition to +5 V / +12 V / -12 V / GND. Same
  "MC = right-angle" naming as the 4-pin; the straight variant is MCV.
- **Distributor:** Digi-Key 277-1209-ND, ~$1.84 single-qty, in stock. Mates
  with the harness plug MC 1,5/5-ST-3,81 (1803604, Digi-Key 277-1164-ND).
- **CSE:** <https://componentsearchengine.com/part-view/1803303/Phoenix%20Contact>
- **Fetch:** symbol + footprint (right-angle, 3.81 mm pitch, 5-pos) + 3D STEP.
- **Notes:** mounts on the rear edge beside the USB for rearward blind-mate on
  insertion. 8 A / 160 V. Start the schematic with the generic 5-position
  MC 1,5 symbol as a placeholder; lock the 1803303 footprint before layout.

### Optional: Coilcraft 0805 chip wirewound inductors (filter L)

- **Manufacturer:** Coilcraft
- **Values:** 0.22 uH (L1/L5, 4 off) and 0.68 uH (L3, 2 off) per the D2
  synthesis. Confirm the exact P/N for each value on the Coilcraft 0805
  family page or at Digi-Key.
- **Fetch:** optional. The generic KiCad `L_0805_2012Metric` footprint is
  physically compatible with the six filter inductors (L1 through L6). Fetch
  the Coilcraft models only if you want exact pad geometry + 3D + a tidier
  BOM export.

---

## Parts from KiCad standard libraries (no fetch needed)

For these, set the symbol field to the standard library reference and the
footprint field to the standard library footprint listed below. They install
with KiCad and need no CSE step.

| Quantity | Part | KiCad symbol | KiCad footprint |
|---|---|---|---|
| 12 | Resistor 0805 (1 % or 0.1 %) | `Device:R` | `Resistor_SMD:R_0805_2012Metric` |
| 9  | Capacitor 0603 (0.1 uF X7R) | `Device:C` | `Capacitor_SMD:C_0603_1608Metric` |
| 4  | Capacitor 0805 (10 uF X5R bulk) | `Device:C` | `Capacitor_SMD:C_0805_2012Metric` |
| 4  | Capacitor 0603 (820 pF C0G filter) | `Device:C` | `Capacitor_SMD:C_0603_1608Metric` |
| 4  | Inductor 0805 (0.22 uH filter L1/L5) | `Device:L` | `Inductor_SMD:L_0805_2012Metric` |
| 2  | Inductor 0805 (0.68 uH filter L3) | `Device:L` | `Inductor_SMD:L_0805_2012Metric` |
| 2  | Ferrite bead 0805 (~600 ohm @ 100 MHz) | `Device:FerriteBead` | `Inductor_SMD:L_0805_2012Metric` |
| 3  | 2N3904 NPN BJT (relay driver) | `Transistor_BJT:2N3904` | `Package_TO_SOT_THT:TO-92_Inline` |
| 3  | 1N4148 small-signal diode (flyback) | `Diode:1N4148` | `Diode_THT:D_DO-35_SOD27_P7.62mm_Horizontal` |
| 1  | 1x2 pin header (BNC wire-out, J2) | `Connector_Generic:Conn_01x02` | `Connector_PinHeader_2.54mm:PinHeader_1x02_P2.54mm_Vertical` |
| 1  | 1x3 pin header (trigger bus, J3) | `Connector_Generic:Conn_01x03` | `Connector_PinHeader_2.54mm:PinHeader_1x03_P2.54mm_Vertical` |

The BNC front-panel jack itself (Amphenol RF 031-5538) is panel-mounted and
wired off-board to J2; it does not get a PCB footprint.

---

## After fetch: verification

Once the five CSE bundles are in `lib/PMVB_1E/`, before placing them on the
schematic:

1. Open each symbol in the KiCad Symbol Editor. Compare pin numbers and
   names against the datasheet. Especially AD9742 (D5 in the design package
   lists every pin) and the Phoenix header pin order
   (1 = +5V, 2 = +12V, 3 = -12V, 4 = GND per the chassis harness).
2. Open each footprint in the KiCad Footprint Editor. Sanity-check the pad
   pitch against the datasheet mechanical drawing.
3. Confirm the 3D STEP loads in the 3D viewer when the footprint is placed
   on the PCB.

If any of those checks fail, fall back to drawing the symbol or footprint
by hand in KiCad rather than trusting a bad CSE bundle - the AD9742 in
particular is worth verifying since it has been wrong in our own design doc.

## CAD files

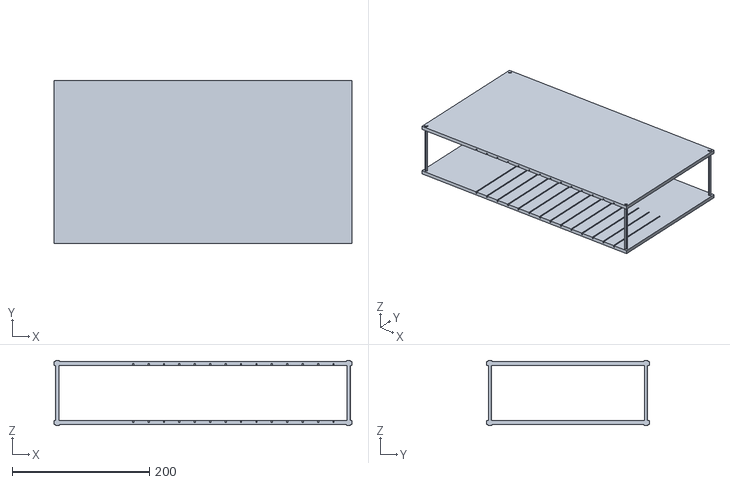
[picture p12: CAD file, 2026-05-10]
tools/fabrication/out/chassis_v10_assembled.stl
435.0 x 238.0 x 95.3

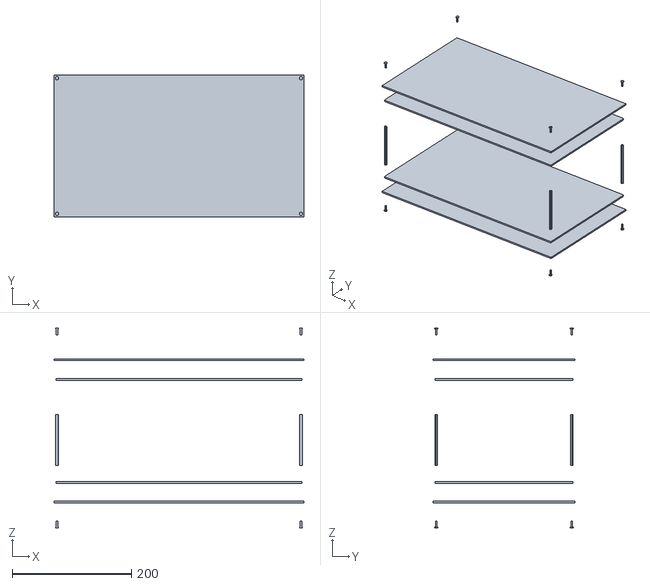
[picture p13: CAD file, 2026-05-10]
tools/fabrication/out/chassis_assembly_exploded.stl
420.0 x 238.0 x 335.3

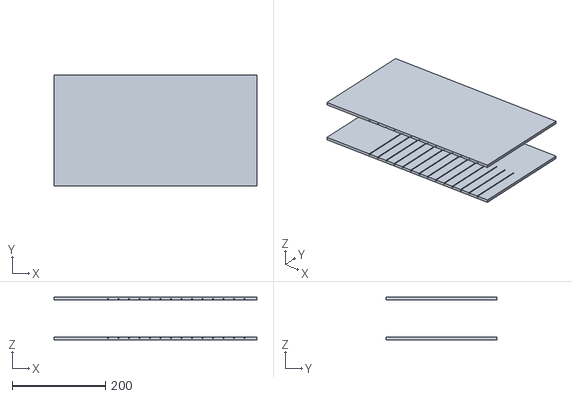
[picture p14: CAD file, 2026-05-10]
tools/fabrication/out/chassis_v10.stl
435.0 x 238.0 x 92.0

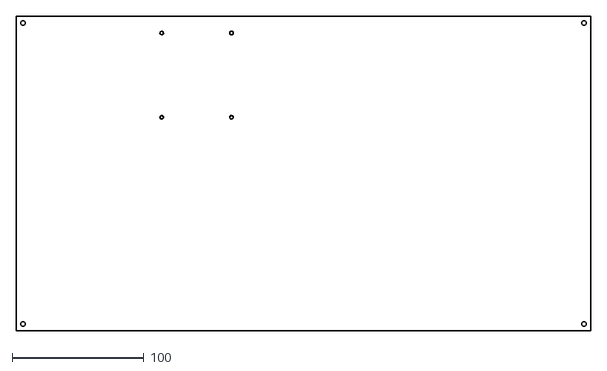
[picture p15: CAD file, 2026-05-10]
tools/fabrication/out/panel_solid_plate.dxf
435.0 x 238.0

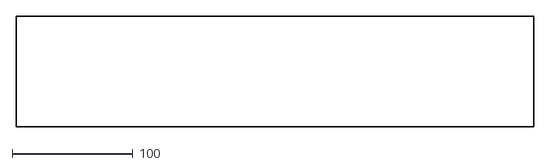
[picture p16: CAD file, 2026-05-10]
tools/fabrication/out/panel_rear_wall.dxf
429.0 x 92.0

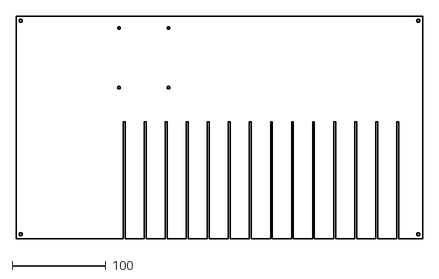
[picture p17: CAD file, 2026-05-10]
tools/fabrication/out/panel_groove_plate.dxf
435.0 x 238.0

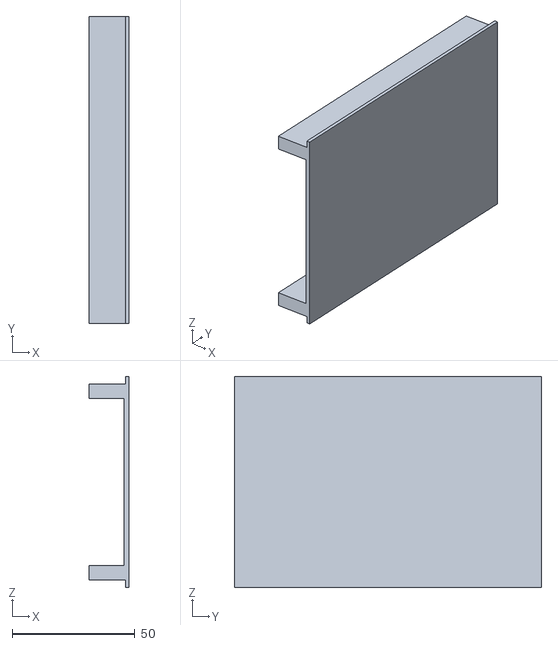
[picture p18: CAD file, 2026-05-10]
tools/fabrication/out/module_body_v10.stl
16.3 x 125.0 x 86.0

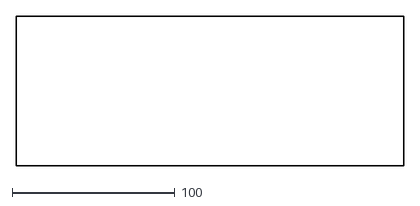
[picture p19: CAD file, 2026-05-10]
tools/fabrication/out/panel_side_wall.dxf
238.0 x 92.0

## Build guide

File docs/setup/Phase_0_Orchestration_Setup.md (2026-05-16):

# Phase 0 Orchestration Layer Setup

Step-by-step bring-up of the PMVB orchestration head: the Raspberry Pi 5 16 GB hosting the Python test framework, the time-series database, the dashboard server, the MCP gateway, and the report generator. Phase 0 closes when an end-to-end test exercises the full SCPI -> InfluxDB -> Grafana -> Jinja2 report pipeline against both a `pyvisa-sim` simulator and a real Pico 2 W over USB-TMC, with hot-plug-by-serial reidentification verified across multiple chassis hub ports.

Architecture detail lives in the [System Design Document](../system-design/System_Design_Document.html) and the [Chassis Architecture and Power Distribution](../chassis/Chassis_Architecture_and_Power_Distribution.html) doc; this is both the architectural reference and the install / bring-up cookbook for the orchestration layer.

---

## Scope

Phase 0 brings up the orchestration layer with no instrument modules attached. The Pi 5's hosted services plus a powered USB hub plus ten bare Pico 2 W boards running a throwaway USB-TMC stub firmware are sufficient to prove every architectural claim of the platform short of actual measurement front-ends. The bench inventory is registry-driven via `tools/pico_nicknames.yaml`, so adding or removing Picos is a YAML edit rather than a procedure rewrite.

Phase 0 verification milestone (per [SDD §13.1](../system-design/System_Design_Document.html#phase-0-orchestration-bring-up)):

1. Pi 5 boots from NVMe, reaches the bench network, the chassis hub enumerates as USB 3.0 with every Pico listed in `tools/pico_nicknames.yaml` visible.
2. An end-to-end pytest exercises both a `pyvisa-sim` placeholder and a real Pico 2 W over USB-TMC. Both records write to InfluxDB with the SDD §10.2 tag taxonomy. Both records appear in a Grafana panel. A Jinja2 report queries InfluxDB and emits HTML+PDF referencing both. A parametric companion test then exercises every Pico in the registry and confirms each one's chip-ID round-trips through `*IDN?` and InfluxDB.
3. Hot-plug-by-serial reidentification is verified across at least three port-swap permutations on the chassis hub.

---

## Architecture

The PMVB orchestration layer is a single Raspberry Pi 5 16 GB hosting the full Python test framework, time-series database, dashboard server, MCP gateway, and report generator. The Pi carries no instrument hardware of its own; it is a pure software orchestrator and data sink that talks to instrument modules over USB-TMC and exposes their SCPI surface as both PyVISA resources (for headless test sequencing) and MCP tools (for agent-orchestrated bench sessions).

### Two-plane architecture

Every module presents two control planes over the same USB-TMC transport, both consuming the same per-module YAML command schema (per SDD §7.3):

1. **VISA/SCPI plane** -- vendor-portable, deterministic, the path used by pytest sequences and any test code that wants to drive instruments programmatically. The orchestrator opens a module as a PyVISA resource (`USB::0xVID::0xPID::SERIAL::INSTR`), writes SCPI commands, and parses responses. Resource identity is keyed off the USB serial number (derived from the Pico 2 W's unique 64-bit chip ID), so hot-plugging a module across different chassis hub ports preserves its logical identity (per SDD §10.1).
2. **MCP plane** -- exposes the same per-module command surface as LLM-callable tools. The MCP gateway (`pmvb.mcp_gateway.server`) is a `FastMCP` server that the Anthropic API talks to. Per-module MCP tools come online with each module's Phase; Phase 0 only scaffolds the gateway with a single health-check tool.

Both planes share the per-module YAML command schema. Firmware parsers and PyVISA-sim simulation backends are generated mechanically from the YAML, eliminating the failure mode where the simulator drifts from the real instrument.

### Software stack components

| Component | Role | Source |
|---|---|---|
| **PyVISA + pyvisa-py** | SCPI dispatch over USB-TMC, GPIB, serial. The pyvisa-py backend is pure-Python; no NI runtime required. | `pip` |
| **PyVISA-sim** | Simulator backend. Each module's simulation lives at `sim/<id>/responses.yaml` and is consumed by PyVISA-sim's stub session. | `pip`, schemas in `sim/` |
| **pytest** | Test runner with parametric fixtures. Tests marked `@pytest.mark.module('1B')` are parameterized across all 1B-class modules attached to the chassis. | `pip` |
| **influxdb-client** | Python client for InfluxDB 2.x. Wrapped by `pmvb.influx` to enforce the SDD §10.2 tag taxonomy. | `pip` |
| **InfluxDB 2.x** | Time-series database. Stores every measurement with the standard tag taxonomy. | `apt` (system service) |
| **Grafana** | Live dashboards. Reads from InfluxDB on every panel refresh. | `apt` (system service) |
| **Jinja2 + Matplotlib** | Automated report generation. Renders HTML and PDF from InfluxDB queries by run identifier. | `pip` |
| **mcp + anthropic** | MCP gateway server framework plus the Anthropic API SDK for any orchestrator code that drives the bench via Claude. | `pip` |
| **pyusb + pyserial** | Low-level USB and serial access for non-PyVISA paths (Pico flash tooling, raw USB queries). | `pip` |

### Data flow

A pytest test in the orchestrator opens a module (real Pico or simulator), issues a SCPI query, captures the response, writes it to InfluxDB tagged per SDD §10.2, and Grafana renders the new record on its next panel refresh. A separate report generator queries InfluxDB by run identifier and emits a Jinja2 + Matplotlib HTML report.

```mermaid
flowchart LR
    Test[pytest test<br/>pmvb.fixtures]
    Mod[Module Pico 2 W<br/>USB-TMC]
    Sim[pyvisa-sim<br/>sim/]
    Influx[(InfluxDB 2.x<br/>pmvb / measurements)]
    Graf[Grafana<br/>Flux queries]
    Rep[pmvb.reports<br/>Jinja2 + Matplotlib]

    Test -- SCPI MEAS:VOLT? --> Mod
    Test -- SCPI MEAS:VOLT? --> Sim
    Mod -- response --> Test
    Sim -- response --> Test
    Test -- write_measurement --> Influx
    Influx -- query --> Graf
    Influx -- query_run --> Rep
```

### `pmvb` Python package layout

The orchestration code lives on the Pi 5 as a single Python package called `pmvb`, installed in editable mode from the cloned repo:

```
pmvb/                              # Python package root (installed editable)
├── __init__.py
├── influx.py                      # InfluxDB I/O helpers enforcing SDD §10.2 tag taxonomy
├── fixtures.py                    # pytest fixtures: run_id, dut, record
├── mcp_gateway/
│   ├── __init__.py
│   └── server.py                  # FastMCP scaffold + health_check tool
└── reports/
    ├── __init__.py
    ├── render.py                  # InfluxDB -> Matplotlib -> Jinja2 -> HTML
    └── templates/
        └── basic_report.html.j2   # default report template

sim/                               # PyVISA-sim YAML schemas (one per module)
└── placeholder/
    └── responses.yaml             # Phase 0 placeholder instrument

tests/                             # pytest tests
├── __init__.py
└── test_smoke.py                  # dependency import smoke tests
```

Per-module SCPI command tables, simulator schemas, and module-specific design docs live outside the `pmvb` package: at `modules/<id>/commands.yaml`, `sim/<id>/responses.yaml`, and `docs/modules/Module_<id>_Design_Document.md` respectively (per SDD §10.1).

---

## Hardware Prerequisites

The orchestration layer is hardware-agnostic by design. The PMVB software stack runs on any 64-bit Linux-capable host with sufficient resources: a Raspberry Pi 5 is the v1.0 reference build, but equivalent ARM SBCs, x86 thin clients, mini-PCs, repurposed laptops, or PowerPC hosts running a recent Linux distribution all work. The orchestration role is pure software (test framework, time-series database, dashboard, MCP gateway, report generator) and has no hardware-specific bindings beyond a USB host port for the module hub.

**Orchestration host** (capabilities, not specific parts):

- 64-bit Linux-capable host with at least 8 GB RAM (16 GB recommended to absorb concurrent Grafana, InfluxDB, MCP, and report-generation workloads without contention)
- A root filesystem on SSD or NVMe (avoid SD-only root for write endurance; if booting from removable media is unavoidable, migrate root to SSD before production use)
- Gigabit Ethernet or 802.11ac+ Wi-Fi for the bench network
- Boot media appropriate to the host (microSD for Raspberry Pi-class boards; USB stick or SSD for x86 systems)

**Bench periphery:**

- Powered USB 3.0 hub with at least 5 downstream ports (the Sabrent HB-BU10 10-port hub is the v1.0 reference)
- Pico 2 W boards (one per instrument module slot you intend to populate)
- Storage for migrating the root filesystem off boot media (NVMe SSD via M.2 HAT+ is the v1.0 reference on the Raspberry Pi 5)

---

## Workstation Prerequisites

A separate workstation (Windows, macOS, or Linux) for SSH access to the orchestration host, browser access to the Grafana UI, and any local development work on the orchestration code.

- An SSH client (built into Windows 10/11, macOS, and most Linux distributions)
- A modern browser for the Grafana UI
- `git` installed if you plan to edit the orchestration code locally and push to GitHub
- An imaging tool appropriate to your chosen orchestration host (for example, [Raspberry Pi Imager](https://www.raspberrypi.com/software/) if you are using a Raspberry Pi)

---

## Section A. Raspberry Pi 5 OS install

The orchestration head runs Raspberry Pi OS Bookworm or newer.

### A.1 Generate an SSH key for the bench

On your workstation, generate a dedicated ed25519 keypair for the bench so the bench credential is isolated from your other systems:

```powershell
ssh-keygen -t ed25519 -f $HOME\.ssh\pmvb-bench -C "pmvb-bench"
```

Press Enter twice when prompted for a passphrase if you want password-less login over LAN (a common choice for a stationary bench).

Add an SSH config entry so `ssh <hostname>` resolves to the right key and user, in `~/.ssh/config`:

```
Host <YOUR_PI_HOSTNAME> <YOUR_PI_HOSTNAME>.local
    HostName <YOUR_PI_HOSTNAME>.local
    User <YOUR_PI_USERNAME>
    IdentityFile ~/.ssh/pmvb-bench
    IdentitiesOnly yes
```

Print the public key for the next step:

```powershell
Get-Content $HOME\.ssh\pmvb-bench.pub
```

### A.2 Flash the SD card via Raspberry Pi Imager

Launch Raspberry Pi Imager. Select Device = Raspberry Pi 5, OS = Raspberry Pi OS (64-bit) (desktop variant if you want a local screen at the bench; Lite if headless), Storage = the microSD card.

Edit OS customization settings:

- Hostname: choose a stable hostname
- Username and password: choose a non-default username; do not use `pi`
- Wireless LAN: configure if connecting over Wi-Fi initially; set wireless LAN country code
- Locale: set time zone and keyboard layout
- Services tab: enable SSH, use public-key authentication only, paste the public key from A.1
- Optional: enable Raspberry Pi Connect for off-LAN fallback access

Write the image, eject the card, insert into the Pi 5, apply power.

### A.3 First boot and SSH verification

Give the Pi 60-90 seconds for first-boot init. Then from your workstation:

```bash
ssh <YOUR_PI_HOSTNAME>
```

Healthy: key-based auth succeeds without password prompt. Verify system state:

```bash
cat /proc/cpuinfo | tail -5    # confirms Pi 5 Model B
df -h /                        # confirms root is on /dev/mmcblk0p2 at this stage
uname -a                       # confirms aarch64 kernel
free -h                        # confirms ~15 GiB RAM available
lsusb -t                       # confirms USB hub + Pico enumeration tree
```

The chassis USB hub should appear as a 4-port hub at 480 Mbps (USB 2 plane) and a 4-port hub at 5000 Mbps (USB 3 plane). With factory-fresh Picos plugged in (no firmware), they appear under the USB 2 plane as `Class=Mass Storage` devices in BOOTSEL mode.

---

## Section B. NVMe boot migration

The Pi 5 boots from microSD by default. The NVMe HAT+ provides a much faster, more durable root filesystem. Migrate boot to NVMe with the SD card retained as a fallback boot device.

### B.1 EEPROM update

```bash
sudo rpi-eeprom-update -a
sudo reboot
```

After reboot, SSH back in and confirm:

```bash
sudo rpi-eeprom-update
```

Should report `BOOTLOADER: up to date`.

### B.2 Boot order set to NVMe-first

```bash
sudo raspi-config
```

Navigate: `6 Advanced Options` -> `A4 Boot Order` -> `B2 NVMe/USB Boot` -> OK -> Finish. Decline the reboot; we will reboot once after the clone.

### B.3 Clone SD root to NVMe

Use the official Pi Foundation tool, SD Card Copier (`piclone`), via the desktop session. Menu -> Accessories -> SD Card Copier. Source: `/dev/mmcblk0` (Internal SD Card). Target: `/dev/nvme0n1`. Check **New Partition UUIDs**. Click Start. Takes 10-15 minutes for ~10 GB.

Alternative for headless Lite installs: use the [framps/rpi-clone](https://github.com/framps/rpi-clone) fork (which handles NVMe partition naming correctly, unlike the original `billw2/rpi-clone`) and run `sudo rpi-clone nvme0n1`.

### B.4 Reboot and verify NVMe boot

```bash
sudo reboot
```

Wait 60-90 seconds, SSH back in:

```bash
df -h /
findmnt /
lsblk
```

Healthy: `df -h /` shows `/dev/nvme0n1p2` as the root mount. `lsblk` shows both `mmcblk0` and `nvme0n1` present, with the NVMe carrying the mountpoints and the SD sitting idle. The SD card stays inserted as fallback boot media.

---

## Section C. Remote access (optional)

For portable benches, install Raspberry Pi Connect to get off-LAN shell + screen-sharing access via the Pi Foundation's relay service:

```bash
sudo apt update
sudo apt install -y rpi-connect      # or rpi-connect-lite for Lite OS (terminal-only)
rpi-connect signin                   # prompts you to link a Raspberry Pi ID via browser
rpi-connect on
rpi-connect status
```

Healthy: `rpi-connect status` shows `Signed in: yes`, `Subscribed to events: yes`, `Screen sharing: allowed`, `Remote shell: allowed`.

Access the bench from any browser at <https://connect.raspberrypi.com>. If you only run on a fixed bench LAN and never need off-network access, skip this section.

---

## Section D. Python orchestration project

The PMVB Python code lives at <https://github.com/Pike1950/poor-mans-validation-bench>. Clone the repo to the Pi, create a virtual environment, and install the project in editable mode.

### D.1 Clone the repo

```bash
cd ~
git clone https://github.com/Pike1950/poor-mans-validation-bench.git pmvb
cd pmvb
```

### D.2 Create the virtual environment

```bash
python3 -m venv .venv
source .venv/bin/activate
python -m pip install --upgrade pip
pip install -e ".[dev]"
```

The `[dev]` extra adds `pytest-cov`, `ruff`, and `mypy` on top of the runtime dependencies. First-time install takes 2-5 minutes on the Pi 5; the piwheels mirror provides pre-built aarch64 wheels for the heavy compiled extensions (Matplotlib, NumPy, Pillow).

### D.3 Verify with smoke tests

```bash
pytest tests/test_smoke.py -v
```

Should pass 8 tests: `pmvb` package imports, PyVISA stack imports, USB stack imports, pytest itself imports, `influxdb-client` imports, Jinja2 + Matplotlib import, the `mcp` framework imports, and the `anthropic` SDK imports.

### D.4 Persist the venv activation

```bash
echo 'source ~/pmvb/.venv/bin/activate' >> ~/.bashrc
```

So that every new SSH session lands inside the venv.

---

## Section E. InfluxDB 2.x

InfluxDB 2.x is the time-series database for every measurement the bench produces. The schema and tag taxonomy are defined in [SDD §10.2](../system-design/System_Design_Document.html#influxdb-schema-and-tag-taxonomy).

### E.1 Add the InfluxData apt repo

```bash
cd ~
curl --silent --location -O https://repos.influxdata.com/influxdata-archive.key
cat influxdata-archive.key | gpg --dearmor | sudo tee /etc/apt/trusted.gpg.d/influxdata-archive.gpg > /dev/null
echo 'deb [signed-by=/etc/apt/trusted.gpg.d/influxdata-archive.gpg] https://repos.influxdata.com/debian stable main' | sudo tee /etc/apt/sources.list.d/influxdata.list
rm influxdata-archive.key
sudo apt update
```

### E.2 Install and enable InfluxDB

```bash
sudo apt install -y influxdb2 influxdb2-cli
sudo systemctl enable --now influxdb
```

Verify:

```bash
systemctl status influxdb --no-pager
ss -tlnp 2>/dev/null | grep 8086
curl -sI http://localhost:8086/ping
```

Healthy: service is `active (running)`, listening on `:::8086`, `curl -sI` returns `HTTP/1.1 204 No Content` with an `X-Influxdb-Version` header.

### E.3 Initial provisioning

```bash
influx setup \
  --username <YOUR_INFLUXDB_USERNAME> \
  --password '<STRONG_PASSWORD>' \
  --org pmvb \
  --bucket measurements \
  --retention 0 \
  --force
```

`--retention 0` is infinite retention. Bench measurement data is small (kilobytes per run), so infinite is appropriate.

The setup command writes the active config to `~/.influxdbv2/configs`, including the operator token.

### E.4 Token rotation and storage

The operator token created by `influx setup` has admin privileges across all orgs. For day-to-day bench use, create a more constrained all-access token scoped to just the `pmvb` org:

```bash
influx auth create \
  --org pmvb \
  --all-access \
  --description "pmvb-bench-orchestrator $(date -I)" \
  --json > /tmp/new_auth.json

NEW_TOKEN=$(python3 -c "import json; print(json.load(open('/tmp/new_auth.json'))['token'])")

sudo mkdir -p /etc/pmvb
sudo chown <YOUR_PI_USERNAME>:<YOUR_PI_USERNAME> /etc/pmvb
echo "$NEW_TOKEN" > /etc/pmvb/influx.token
chmod 600 /etc/pmvb/influx.token

influx config set -n default -t "$NEW_TOKEN"
```

Then delete the original operator token using its ID from `influx auth list`:

```bash
influx auth list                          # find the operator token ID
influx auth delete --id "<OPERATOR_ID>"   # delete it
influx auth list                          # confirm only the org-scoped token remains
```

### E.5 Round-trip verification

```bash
TOKEN=$(cat /etc/pmvb/influx.token)

influx write \
  --bucket measurements \
  --org pmvb \
  --token "$TOKEN" \
  'phase0_test,instrument=sim-bringup,channel=0,run_id=phase0-influx-smoke value=1.234'

influx query \
  --org pmvb \
  --token "$TOKEN" \
  'from(bucket: "measurements") |> range(start: -5m) |> filter(fn: (r) => r._measurement == "phase0_test")'
```

Healthy: the write completes silently with exit 0, and the query returns a table containing one record with the expected tags and value.

---

## Section F. Grafana

Grafana is the dashboard layer. It reads from InfluxDB on every panel refresh and renders charts, tables, alerts, and recipe-specific dashboards.

### F.1 Add the Grafana apt repo

```bash
sudo apt install -y apt-transport-https wget
sudo mkdir -p /etc/apt/keyrings
wget -q -O - https://apt.grafana.com/gpg.key | gpg --dearmor | sudo tee /etc/apt/keyrings/grafana.gpg > /dev/null
echo "deb [signed-by=/etc/apt/keyrings/grafana.gpg] https://apt.grafana.com stable main" | sudo tee /etc/apt/sources.list.d/grafana.list
sudo apt update
```

On Trixie and newer, the legacy `software-properties-common` package is no longer required; apt has built-in HTTPS support.

### F.2 Install and enable Grafana

```bash
sudo apt install -y grafana
sudo systemctl daemon-reload
sudo systemctl enable --now grafana-server
```

Verify (Grafana needs ~15 seconds after start to actually open port 3000 because it runs DB migrations on first boot):

```bash
sleep 15
systemctl status grafana-server --no-pager
ss -tlnp 2>/dev/null | grep 3000
curl -sI http://localhost:3000/login
```

Healthy: service is `active (running)`, listening on `:::3000`, `/login` returns `HTTP/1.1 200 OK`.

The PMVB reference build runs Grafana 13 (the stable apt channel installs whatever the current major is). Grafana 10 and newer all work; the install pattern and datasource configuration are identical.

### F.3 First login

Open `http://<YOUR_PI_HOSTNAME>:3000` in your workstation browser. Default credentials are `admin` / `admin`; Grafana forces a password change on first login.

### F.4 Add InfluxDB datasource

UI left sidebar -> Connections -> Data sources -> Add new data source -> InfluxDB. Fill in:

- Name: `pmvb-influx`
- Query language: `Flux` (default is InfluxQL; switch to Flux for InfluxDB 2.x)
- HTTP URL: `http://localhost:8086`
- Access mode: `Server (default)`
- InfluxDB Details:
  - Organization: `pmvb`
  - Token: paste the contents of `/etc/pmvb/influx.token`
  - Default Bucket: `measurements`

Click **Save & test**. Healthy: green banner reading `datasource is working. 3 buckets found` (the three are `_monitoring`, `_tasks`, and `measurements`).

### F.5 Data-path verification

UI left sidebar -> Explore. Pick the `pmvb-influx` datasource. Paste the following Flux query:

```
from(bucket: "measurements")
  |> range(start: -1h)
  |> filter(fn: (r) => r._measurement == "phase0_test")
```

Run query. The `phase0_test` records written in E.5 should appear as a small time-series plot plus a table. This proves the full pipeline: InfluxDB stores -> Grafana queries -> Grafana renders.

---

## Section G. Pico SDK and cross-compile toolchain

Every PMVB instrument module is built around a Pico 2 W (RP2350 SoC). For Phase 0 we flash a throwaway USB-TMC stub firmware on the bare Picos to prove the hot-plug-by-serial architecture. The Pico SDK toolchain installed here is reused across every per-module firmware build later.

### G.1 Install the cross-compile toolchain

```bash
sudo apt install -y \
  gcc-arm-none-eabi \
  libnewlib-arm-none-eabi \
  libstdc++-arm-none-eabi-newlib \
  build-essential \
  cmake \
  ninja-build \
  git \
  python3 \
  libusb-1.0-0-dev \
  pkg-config
```

Roughly 500 MB after dependencies.

### G.2 Clone pico-sdk

```bash
sudo mkdir -p /opt
sudo git clone --branch master --recurse-submodules --shallow-submodules \
  https://github.com/raspberrypi/pico-sdk.git /opt/pico-sdk
sudo chown -R <YOUR_PI_USERNAME>:<YOUR_PI_USERNAME> /opt/pico-sdk
```

`--recurse-submodules` pulls in TinyUSB at `lib/tinyusb` (the USB-TMC class support comes from here), btstack, cyw43-driver, lwip, and mbedtls. `--shallow-submodules` keeps the clone size reasonable (~200 MB total).

Verify the SDK version and submodule state:

```bash
cd /opt/pico-sdk
git describe --tags        # should show 2.0 or later (RP2350 support requires 2.0+)
git submodule status
```

All submodules should be listed without a leading `-` (means initialized). Required: `lib/tinyusb`.

### G.3 Set environment variables persistently

```bash
echo 'export PICO_SDK_PATH=/opt/pico-sdk' >> ~/.bashrc
echo 'export PICO_BOARD=pico2_w' >> ~/.bashrc
source ~/.bashrc
```

`PICO_BOARD=pico2_w` selects the Pico 2 W board definition (RP2350 + Wi-Fi/Bluetooth chip + correct flash and pinout). `PICO_SDK_PATH` points the SDK's CMake support files at the cloned SDK tree.

### G.4 Verify cross-compile with `hello_usb`

```bash
cd ~
git clone --depth 1 --recurse-submodules https://github.com/raspberrypi/pico-examples.git
cd pico-examples
mkdir -p build && cd build
cmake .. -G Ninja -DPICO_BOARD=pico2_w
ninja hello_usb
ls -la hello_world/usb/hello_usb.uf2
```

Healthy: cmake configures cleanly (reports `Target board (PICO_BOARD) is 'pico2_w'`, auto-converts the platform to `rp2350-arm-s`, finds the gcc-arm-none-eabi toolchain). Ninja builds with no errors and produces `hello_world/usb/hello_usb.uf2` of ~50-80 KB. That `.uf2` is a valid RP2350 firmware image (do not flash it; we have a real stub firmware coming up in section H).

---

## Section H. USB-TMC stub firmware

The probe firmware lives at `firmware/pmvb_usbtmc_stub/` in the repo. It is a minimal TinyUSB USB-TMC class (USB488 subclass) application that enumerates with a chip-ID-derived `iSerialNumber` and responds to a small SCPI dialect: `*IDN?`, `*RST`, `*CLS`, `*OPC?`, plus a PMVB extension `:SYST:BOOTSEL` that reboots the Pico back into BOOTSEL mode without the physical button. This is throwaway probe firmware; real per-module SCPI parsers ship with each module's own Phase.

Files under `firmware/pmvb_usbtmc_stub/`:

- `CMakeLists.txt` -- Pico SDK build configuration
- `tusb_config.h` -- TinyUSB configuration (USB-TMC + USB488 subclass enabled, interrupt endpoint on)
- `usb_descriptors.c` -- VID `0xCafe` / PID `0x4001`, manufacturer "PMVB", iSerialNumber from `board_usb_get_serial()`
- `usbtmc_handlers.c` -- USB-TMC class callbacks plus SCPI command dispatch
- `main.c` -- entry point, TinyUSB init, main loop
- `README.md` -- per-firmware documentation

Build the firmware:

```bash
cd ~/pmvb/firmware/pmvb_usbtmc_stub
mkdir -p build && cd build
cmake .. -G Ninja -DPICO_BOARD=pico2_w
ninja
ls -la pmvb_usbtmc_stub.uf2
```

Healthy: ninja produces a ~57 KB `pmvb_usbtmc_stub.uf2` file in `build/`. First build pulls in TinyUSB and picotool from the Pico SDK and takes 1-2 minutes; subsequent builds are seconds.

Flash every Pico in the bench inventory at once (currently ten boards; the loop below is count-agnostic). They must each be in BOOTSEL mode (factory state, or after `:SYST:BOOTSEL`). Each appears as a mass-storage volume mounted at `/media/<user>/RP2350*`:

```bash
UF2=~/pmvb/firmware/pmvb_usbtmc_stub/build/pmvb_usbtmc_stub.uf2
for mnt in /media/<YOUR_PI_USERNAME>/RP2350*/ ; do
  cp "$UF2" "$mnt"
  sync
done
sleep 5
```

Note: the udev rule installed in Section I suppresses BOOTSEL automount, which means freshly factory-new Picos plugged in after Section I will not auto-appear under `/media/<user>/RP2350*`. To flash additional Picos after the udev rule is in place, mount them manually first (`sudo mount /dev/sdX1 /mnt/rp_<letter>` for each device, copy the UF2, then `sync` and unmount).

After the `sync` and a few seconds for Picos to auto-reboot, verify the flash:

```bash
lsusb -d cafe:4001
```

Healthy: one entry per Pico in the bench inventory showing `ID cafe:4001 PMVB PMVB Pico 2 W USB-TMC Stub`. Each has a distinct 16-character hex iSerialNumber derived from its unique RP2350 chip ID. Record each chip ID in `tools/pico_nicknames.yaml` with a human-readable nickname; the parametric inventory test in Section K reads this file as its source of truth.

---

## Section I. udev rules

The udev rules file lives at `tools/udev/99-pmvb-usbtmc.rules` in the repo. Three concerns are handled:

1. **libusb access on the USB subsystem.** PyVISA-py's `@py` backend uses libusb (via pyusb) for USB-TMC transfers and needs `plugdev` access on the raw `/dev/bus/usb/<bus>/<dev>` device, separate from the kernel's `/dev/usbtmcN` interface. Without this rule, PyVISA-py cannot open the device even though the kernel may have already bound to it.
2. **USB-TMC kernel device permissions + serial symlinks.** The kernel's `usbtmc` driver creates `/dev/usbtmcN` nodes owned root:root by default. Grant `plugdev` access and add stable `/dev/usbtmc-by-serial/<chip_id>` symlinks via the `usb_id` builtin so tools that prefer the kernel path can find devices by serial rather than the unstable `usbtmcN` enumeration order.
3. **Suppress automount of BOOTSEL volumes.** When a Pico is in BOOTSEL mode (factory-fresh, or after `:SYST:BOOTSEL`), it exposes itself as Raspberry Pi VID `0x2e8a` PID `0x000f` mass-storage. Without suppression, every BOOTSEL Pico would auto-mount to `/media/<user>/RP2350*`, which clutters the workflow. The rule also covers PID `0x0003` (RP2040 BOOTSEL) for compatibility with older Pico boards.

Install:

```bash
sudo cp ~/pmvb/tools/udev/99-pmvb-usbtmc.rules /etc/udev/rules.d/
sudo udevadm control --reload-rules
sudo udevadm trigger --action=change --subsystem-match=usb
sudo udevadm trigger --action=change --subsystem-match=usbmisc
sudo udevadm verify /etc/udev/rules.d/99-pmvb-usbtmc.rules
```

Verify:

```bash
ls -la /dev/usbtmc*
ls -la /dev/usbtmc-by-serial/
groups | tr ' ' '\n' | grep plugdev
```

Healthy: `/dev/usbtmcN` nodes (one per Pico, currently `usbtmc0` through `usbtmc9`) show `crw-rw---- 1 root plugdev`, a matching number of symlinks exist under `/dev/usbtmc-by-serial/` named with the chip IDs, and your user is in the `plugdev` group. The kernel-assigned `N` is hot-plug-order-dependent, not slot-dependent; the symlinks are the stable handle.

---

## Section J. Hot-plug verification

Tooling: `tools/hot_plug_verify.py` (uses pyvisa-py + pyusb to enumerate USB-TMC instruments and print a nickname / slot / serial / IDN table) and `tools/pico_nicknames.yaml` (maps each chip-ID serial to a human-readable label).

Procedure:

1. Establish a baseline. With every Pico from `tools/pico_nicknames.yaml` in a known physical slot, run the script:
   ```bash
   cd ~/pmvb
   python tools/hot_plug_verify.py
   ```
   Note the NICKNAME, SERIAL, and `*IDN?` RESPONSE columns. The DEV NODE column may show "(no symlink)" for instruments that pyvisa-py has already detached from the kernel driver -- that is expected and not a fault.
2. Physically move one or more Picos to different slots on the chassis hub. Wait 3-5 seconds for the kernel to re-enumerate.
3. Re-run the script and compare. The SERIAL and `*IDN?` columns must be identical to the baseline for every Pico, regardless of the new slot. The SLOT column should report the new physical positions correctly (calibrated by `SABRENT_SLOT_MAP` in the script).
4. Repeat for at least three port-swap permutations per the SDD §13.1 milestone.

What the test proves: PyVISA-py resource discovery keys off the USB `iSerialNumber` (derived from the RP2350 chip ID), not the USB topology. Hot-plugging a Pico across hub ports preserves its logical identity in `pmvb.influx` writes, in the PyVISA resource string, and in any per-module test code that opens by serial.

Edge cases:

- If a Pico that was previously seen does not show up after replug, the kernel may have a stuck binding. `sudo udevadm trigger --action=change --subsystem-match=usb` usually clears it.
- If the SLOT column reports `?(<port_chain>)` for a slot you have not tested before, the `SABRENT_SLOT_MAP` in the script is missing that mapping. The script's source comment includes the calibration recipe.

---

## Section K. Phase 0 verification milestone

The closing tests live at `tests/test_phase0_e2e.py` and exercise every architectural claim of the Phase 0 platform in one pass. The file contains three tests, run together:

```bash
cd ~/pmvb
source .venv/bin/activate
pytest tests/test_phase0_e2e.py -v -s
```

### `test_phase0_milestone` (the historical Phase 0 close artifact)

Exercises the data path end-to-end against one sim instrument and one real Pico:

1. Opens `sim/placeholder/responses.yaml` via pyvisa-sim, sends `*IDN?`, captures the placeholder's response.
2. Writes the sim record to InfluxDB via `pmvb.influx.write_measurement` with the SDD §10.2 tag taxonomy (`instrument=sim-placeholder`, `channel=0`, `dut=phase0-bringup-dut`, `run_id=<uuid>`, `measurement_type=idn_response`).
3. Enumerates real Pico 2 W instruments via pyvisa-py, opens the first one, sends `*IDN?`, captures the chip-ID-derived response.
4. Writes the Pico record to InfluxDB tagged with the actual chip ID as `instrument=pico-<chip_id>`.
5. Queries InfluxDB back via `pmvb.influx.query_run` and asserts both records are present.
6. Renders an HTML report via `pmvb.reports.render.write_report` and asserts the report contains the `run_id`, the sim record, and at least one Pico record.

### `test_pico_inventory_ping[Pico_<N>-<chip_id_prefix>]` (parametric inventory exercise)

Parametrized over every entry in `tools/pico_nicknames.yaml`. One pytest test ID per Pico, so a failure isolates to a specific board. Each invocation:

1. Looks up the Pico's USB-TMC resource string by chip-ID serial in a module-scoped discovery map.
2. Opens the resource via pyvisa-py, sends `*IDN?`, and asserts the IDN response's serial field (`PMVB,Pico 2 W,<serial>,1.0.0`) matches the registry chip ID. This catches YAML drift, mis-flashed firmware, and physical swaps that were not tracked in the registry.
3. Writes the record to InfluxDB tagged `instrument=pico-<chip_id>` under a shared `inventory_run_id`, with nickname and resource string as fields.

### `test_pico_inventory_round_trip` (cross-Pico round-trip summary)

Runs last by virtue of in-file pytest collection order. Queries InfluxDB for the shared `inventory_run_id` set by the parametric tests, asserts every `pico-<chip_id>` made it back, and prints an OK / MISS table per Pico.

### Healthy output

```
tests/test_phase0_e2e.py::test_phase0_milestone PASSED

  Phase 0 verification milestone PASS
  run_id:                phase0-e2e-<8 hex>
  sim IDN:               PMVB,placeholder,phase0-sim,1.0.0
  pico IDN:              PMVB,Pico 2 W,<chip_id>,1.0.0
  pico resource:         USB0::51966::16385::<chip_id>::0::INSTR
  InfluxDB records:      6
  Report written:        /tmp/.../phase0_e2e_<run_id>.html (<size> bytes)

tests/test_phase0_e2e.py::test_pico_inventory_ping[Pico_1-<chip_id_prefix>] PASSED
tests/test_phase0_e2e.py::test_pico_inventory_ping[Pico_2-<chip_id_prefix>] PASSED
...
tests/test_phase0_e2e.py::test_pico_inventory_ping[Pico_10-<chip_id_prefix>] PASSED
tests/test_phase0_e2e.py::test_pico_inventory_round_trip PASSED

  Phase 0 inventory round-trip PASS
  inventory_run_id:      phase0-inventory-<8 hex>
  Picos in registry:     10
  Picos enumerated:      10
  InfluxDB records:      50
    [  OK] Pico #1    <chip_id>
    [  OK] Pico #2    <chip_id>
    ...
```

The `InfluxDB records` counts reflect Flux's per-field row return. The milestone shows 6 (2 writes × 3 fields: `value`, `idn_string`, `source`). The inventory round-trip shows 50 with the full ten-Pico inventory (10 writes × 5 fields: `value`, `idn_string`, `nickname`, `resource`, `source`). Both scale with the number of fields per write, not the number of writes alone.

### Running a subset

To skip the milestone and run only the inventory parametric exercise as a faster smoke check:

```bash
pytest tests/test_phase0_e2e.py::test_pico_inventory_ping tests/test_phase0_e2e.py::test_pico_inventory_round_trip -v
```

To re-run a single Pico (shell-quote the brackets):

```bash
pytest 'tests/test_phase0_e2e.py::test_pico_inventory_ping[Pico_5-B555F0C1]' -v
```

### When this passes

Phase 0 is officially complete and Phase 1 begins (Modules 1A, 1B, 1D, 1E per [SDD §13.2](../system-design/System_Design_Document.html#phase-1-modules)). Each Phase 1 module re-uses the orchestration infrastructure built here: same `pmvb.influx` tag taxonomy, same Jinja2 report renderer, same MCP gateway, same Pico SDK toolchain, with each module's firmware replacing the Phase 0 USB-TMC stub for that physical Pico.

---

## Troubleshooting

**`pip install` fails on a compiled package** -- check the piwheels mirror is reachable (`pip config list` should list `https://www.piwheels.org/simple` as an extra-index-url; it is configured by default on Raspberry Pi OS). If piwheels is unreachable, pip falls back to source builds which take 10-20 minutes per heavy package.

**InfluxDB web UI returns 404 right after install** -- wait 30 seconds after `systemctl enable --now influxdb` for first-time setup, then reload.

**Grafana cannot reach InfluxDB** -- verify the URL is `http://localhost:8086` (not `https`), the token is pasted without trailing whitespace, the organization matches `pmvb` exactly (case-sensitive), and the query language is set to `Flux` rather than the default `InfluxQL`.

**Pi 5 fails to boot from NVMe after migration** -- confirm `BOOT_ORDER` is set via `sudo raspi-config` to NVMe-first. Confirm the EEPROM is recent (`sudo rpi-eeprom-update` should report up-to-date). With the SD card still inserted, the Pi falls back to SD boot, so a NVMe-boot failure is recoverable.

**`ninja hello_world_usb` reports "unknown target"** -- the modern pico-examples target name is `hello_usb`, not `hello_world_usb`. Run `ninja -t targets | grep -i hello` to enumerate available targets.

**Picos enumerate as `Class=Mass Storage` rather than as USB-TMC instruments** -- the Picos are in BOOTSEL mode (factory state, no firmware flashed). After flashing the stub firmware in section H, they will enumerate as USB-TMC class.

---

## Future Enhancements

The orchestration layer's roadmap beyond Phase 0:

- **Phase 1 onward -- per-module MCP tools.** Each module's design phase adds its SCPI surface to `pmvb.mcp_gateway.server` as MCP-callable tools. The Phase 0 scaffold's `health_check` is joined later by `module_1b_measure_voltage`, `module_1e_set_sine`, etc.
- **Bench programming manual.** A dedicated programming reference covering the orchestrator API surface (`pmvb.influx`, `pmvb.fixtures`, `pmvb.mcp_gateway`, `pmvb.reports`), the standard SCPI dialect across modules, the YAML command schema convention, and pytest fixture patterns. Authoring deferred until at least two real modules are online so the manual reflects actual usage rather than architectural intent.
- **Grafana provisioning files.** Today the InfluxDB datasource and dashboards are configured through the Grafana UI. A `/etc/grafana/provisioning/datasources/*.yaml` declarative config would make the dashboard layer reproducible across re-installs and bench clones.
- **CI for SCPI YAML schema validation.** A pre-commit / CI step that validates each `modules/<id>/commands.yaml` against the SDD §10.2 schema, then re-renders the corresponding `sim/<id>/responses.yaml` to keep simulator and command surface in lockstep.
- **Phase 4 -- chassis LAN switch.** Today the Pi 5's onboard Ethernet connects directly to the bench network. Phase 4 introduces a chassis-internal gigabit switch to give Tier 3 streaming modules (Pi Zero 2 W sidecars) their own subnet for sustained-capture data paths beyond USB-TMC's 12 Mbps.

---

## References

- [System Design Document](../system-design/System_Design_Document.html) -- canonical architecture, module catalog, build phases
- [Chassis Architecture and Power Distribution](../chassis/Chassis_Architecture_and_Power_Distribution.html) -- chassis mechanical and electrical detail
- [PMVB GitHub repository](https://github.com/Pike1950/poor-mans-validation-bench)
- [Raspberry Pi OS documentation](https://www.raspberrypi.com/documentation/computers/os.html)
- [Raspberry Pi M.2 HAT+ install guide](https://www.raspberrypi.com/documentation/accessories/m2-hat-plus.html)
- [InfluxDB 2.x documentation](https://docs.influxdata.com/influxdb/v2/)
- [Grafana documentation](https://grafana.com/docs/grafana/latest/)
- [Pico SDK](https://github.com/raspberrypi/pico-sdk)
- [Pico examples](https://github.com/raspberrypi/pico-examples)
- [TinyUSB](https://github.com/hathach/tinyusb) -- USB-TMC class implementation used by the stub firmware

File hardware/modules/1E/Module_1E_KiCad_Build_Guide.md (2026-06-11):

# Module 1E KiCad Build Guide

Step-by-step setup for the KiCad project, then the hierarchical sheet
specification you wire from. Targets KiCad 9 (KiCad 8 paths are identical for
all the menus used here). Pre-requisite: the five custom parts from
`Module_1E_Parts_Checklist.md` have been fetched and dropped into
`hardware/modules/1E/kicad/lib/PMVB_1E/`.

## 1. Create the project

1. **File - New Project**, set the project name to `module_1e` and the
   location to `hardware/modules/1E/kicad/`. KiCad creates
   `module_1e.kicad_pro`, `module_1e.kicad_sch`, and `module_1e.kicad_pcb`.
2. Open `module_1e.kicad_sch` (root). **File - Page Settings**, fill in:
   - **Title:** Module 1E - Function Generator / AWG
   - **Company:** PMVB
   - **Rev:** v0.1
   - **Date:** today's date
   - **Comment 1:** SDD section 7.5.5; design package
     `Module_1E_PCB_Design_Package.md`
   - **Comment 2:** designer Brad Ward
3. Save.

## 2. Library setup

In eeschema: **Preferences - Manage Symbol Libraries**. Switch to the
**Project Specific Libraries** tab and add:

| Nickname | Library Path |
|---|---|
| PMVB_1E | `${KIPRJMOD}/lib/PMVB_1E/symbols/pmvb_1e.kicad_sym` |

Adjust the filename if the CSE Library Loader produced a different one;
combine multiple per-part `.kicad_sym` files into a single project library
or add each individually. Project-specific scope is correct here so the
library moves with the repo, not the workstation.

In pcbnew: **Preferences - Manage Footprint Libraries**, same idea:

| Nickname | Library Path |
|---|---|
| PMVB_1E | `${KIPRJMOD}/lib/PMVB_1E/footprints.pretty` |

3D models from CSE land in `lib/PMVB_1E/3dmodels/`; the footprints' 3D
references should already point there if the Library Loader configured paths
correctly.

## 3. Import the board outline

In pcbnew, on a fresh empty board:

1. **File - Import - Graphics**, pick
   `../../library/module_pcb_outline.dxf`.
2. **Layer:** Edge.Cuts. **Placement:** at origin, scale 1:1.
3. Click OK. The 120 x 62 mm outline, the four M2.5 mounting-hole circles,
   and the placement-zone annotations come in. Move the
   `User.Comments`/`User.Drawings` items to whichever layer you find easiest
   to ignore during routing.
4. Save. Re-import any time the outline generator is regenerated.

## 4. Netclasses and DRC

In pcbnew: **File - Board Setup - Net Classes**. Set defaults and add the
classes from section 8 of the design package:

| Netclass | Track width | Clearance | Notes |
|---|---|---|---|
| Default | 0.25 mm | 0.2 mm | everything not otherwise assigned |
| Power_12V | 0.8 mm | 0.25 mm | +12V, -12V (op-amp rails) |
| Power_5V | 0.6 mm | 0.2 mm | +5V (relay coils) |
| Power_3V3 | 0.5 mm | 0.2 mm | +3V3, AVDD, DVDD |
| Analog | 0.3 mm | 0.25 mm | IOUTA, IOUTB, FILT_A, FILT_B, OPAMP_IN+/-, OPAMP_OUT, BNC_CENTER |
| DataBus | 0.25 mm | 0.2 mm | DB0..DB11, DAC_CLK |

Assign nets to classes after the schematic is captured and netlist imported
(eeschema **Tools - Edit Symbol Fields** or pcbnew **Net Inspector**).

Under **Board Setup - Design Rules - Constraints**: minimum clearance
0.20 mm, minimum track width 0.20 mm. Relax if your chosen fab needs more.

## 5. Create the hierarchical sheets

On the root sheet `module_1e.kicad_sch`, drop five hierarchical sheet
symbols: **Place - Add Hierarchical Sheet** (shortcut `S`), one per
functional block. Filenames and recommended sheet sizes:

| Sheet symbol | Filename | Approx size |
|---|---|---|
| Pico | `Pico.kicad_sch` | medium |
| DAC | `DAC.kicad_sch` | large (most components) |
| OpAmp | `OpAmp.kicad_sch` | medium |
| OutputSwitch | `OutputSwitch.kicad_sch` | medium |
| Trigger | `Trigger.kicad_sch` | small |

Double-click each sheet symbol to descend into it. Inside each sub-sheet,
place hierarchical labels (**Place - Add Hierarchical Label**, shortcut `H`)
that match the per-sheet contracts in section 7 below. Back on the root,
those labels appear as sheet pins on the sheet symbol; wire them to the
inter-sheet nets and to the Phoenix-driven power flags.

Use **Place - Add Power Symbol** for `+5V`, `+12V`, `-12V`, `+3V3`, `GND`
inside every sheet that uses them. Power symbols are auto-global, no
hierarchical-label declaration needed for them.

---

## 6. Root sheet contents

The root sheet `module_1e.kicad_sch` carries the project metadata, the
power input, and the sheet symbols. Concrete contents:

- **J1** Phoenix MC 1,5/5-G-3,81 right-angle header (1803303), on the rear
  edge beside the USB for rearward blind-mate.
  - Pin 1 -> `+5V` power flag.
  - Pin 2 -> `+12V` power flag.
  - Pin 3 -> `-12V` power flag.
  - Pin 4 -> `GND` power flag.
  - Pin 5 -> `+3V3` power flag (DAC supply; chassis 3.3 V rail).
- Five hierarchical sheet symbols (Pico, DAC, OpAmp, OutputSwitch, Trigger).
- No other components. All sub-sheet signals enter and exit via sheet pins.

---

## 7. Sub-sheet specifications

For each sheet: the symbols that live on it, the hierarchical labels it
imports and exports (direction is from the sheet's perspective), the power
nets it uses, and any wiring notes you have to honor.

### 7.1 Pico (`Pico.kicad_sch`)

- **Symbols:** U1 (Raspberry Pi Pico 2 W). The former C15 3V3_OUT bypass
  moves to the J1 +3V3 entry (DAC sheet), since the Pico no longer feeds the DAC.
- **Hierarchical labels OUT** (Pico drives them):
  `DB0`, `DB1`, ..., `DB11`, `DAC_CLK`,
  `RELAY_50`, `RELAY_HIZ`, `RELAY_10K`, `SYNC_OUT`.
- **Hierarchical labels IN** (Pico receives):
  `TRIG_IN`.
- **Power:** `GND` on all eight Pico GND pins (3, 8, 13, 18, 23, 28, 33, 38).
- **Notes:**
  - VBUS (pin 40), VSYS (pin 39), 3V3_EN (pin 37), ADC_VREF (pin 35), RUN
    (pin 30), and GP18..GP28 unused on this module - leave unconnected or
    place "no-connect" flags.
  - Pin mapping for signals (from the design doc section 4):
    GP0..GP11 = DB0..DB11, GP12 = DAC_CLK, GP13 = RELAY_50,
    GP14 = RELAY_HIZ, GP15 = RELAY_10K, GP16 = SYNC_OUT, GP17 = TRIG_IN.
  - Pico is USB-powered; the module PCB does not feed it. Its `3V3_OUT`
    (pin 36) is left unconnected - the DAC supply island is now fed by `+3V3`
    from J1 pin 5 (chassis 3.3 V), not the Pico.

### 7.2 DAC (`DAC.kicad_sch`)

- **Symbols:** U2 (AD9742); FB1, FB2 (ferrite beads to AVDD, DVDD);
  R1 (1.91 k 0.1 % FSADJ); R2, R3 (25 ohm 0.1 % IOUTA/IOUTB terminations);
  C1 (0.1 uF REFIO); C6, C7 (0.1 uF AVDD, DVDD bypass);
  C8 (10 uF X5R 0805 bulk) + C15 (0.1 uF) at the +3V3 entry (from J1 pin 5);
  C16, C17 (second 0.1 uF AVDD, DVDD bypass);
  L1, L3 (0.22 uH filter A outer series), L2 (0.68 uH filter A mid series); L4, L6 (0.22 uH filter B outer series), L5 (0.68 uH filter B mid series);
  C2, C3 (820 pF C0G filter A shunt); C4, C5 (820 pF C0G filter B shunt).
- **Hierarchical labels IN:** `DB0`..`DB11`, `DAC_CLK`, `+3V3` (passive).
- **Hierarchical labels OUT:** `FILT_A`, `FILT_B`.
- **Power:** `GND`, `+3V3` -> local FB1/FB2 -> `AVDD`/`DVDD` (local nets,
  do not export).
- **Notes:**
  - **Pin 23 RESERVED:** leave unconnected. Per the AD9742 datasheet
    Rev. C, do not stub to GND or to a supply.
  - **Pin 25 MODE -> GND (= DCOM):** selects straight-binary input format.
    Firmware must emit straight-binary sample codes (D5).
  - **Pin 15 SLEEP -> GND:** keeps the DAC out of power-down. Has an
    internal pull-down; tying low is explicit.
  - **Pin 16 REFLO -> GND:** uses the internal 1.2 V reference.
  - **Reconstruction filter (D2):** two independent 5th-order L-C-L-C-L
    ladders, one per leg. Topology and values are placeholders pending a
    real filter-synthesis pass; the wiring contract is fixed.
    - Leg A: IOUTA -> L1 -> n1A -> C2 to GND, L2 -> n2A -> C3 to GND,
      L3 -> FILT_A.
    - Leg B: IOUTB -> L4 -> n1B -> C4 to GND, L5 -> n2B -> C5 to GND,
      L6 -> FILT_B.
  - **25 ohm terminations:** R2 from IOUTA to GND, R3 from IOUTB to GND;
    place them physically adjacent to the DAC pins.

### 7.3 OpAmp (`OpAmp.kicad_sch`)

- **Symbols:** U3 (AD8056); R4, R5 (1 k 1 % input resistors);
  R6 (20 k 1 % feedback); R7 (20 k 1 % balance);
  C9, C10 (0.1 uF V+, V- bypass); C11, C12 (10 uF X5R bulk on each rail).
- **Hierarchical labels IN:** `FILT_A`, `FILT_B`.
- **Hierarchical labels OUT:** `OPAMP_OUT`.
- **Power:** `+12V`, `-12V`, `GND`.
- **Notes:**
  - **Channel A is the live path.** Standard difference-amp wiring:
    FILT_A through R4 (1 k) to +INA (pin 3); R7 (20 k) from +INA to GND;
    FILT_B through R5 (1 k) to -INA (pin 2); R6 (20 k) feedback from -INA
    to OUTA (pin 1). Differential gain = 20 (D1).
  - **Channel B is unused.** Terminate cleanly:
    +INB (pin 5) -> GND, -INB (pin 6) -> OUTB (pin 7).
    Leaving high-speed op-amp inputs floating is the usual oscillation trap.
  - **V+ pin 8 -> +12V; V- pin 4 -> -12V.**

### 7.4 OutputSwitch (`OutputSwitch.kicad_sch`)

- **Symbols:** K1, K2, K3 (Coto 9007-05-01); Q1, Q2, Q3 (2N3904);
  D1, D2, D3 (1N4148); R8 (50 ohm 1 %), R10 (10 k 1 %) series
  (K2's branch has no series resistor; R9 is intentionally not used);
  R11, R12, R13 (1 k base resistors);
  J2 (1x2 pin header, BNC wire-out); C13 (0.1 uF +5V bypass);
  C14 (10 uF X5R +5V bulk).
- **Hierarchical labels IN:** `OPAMP_OUT`, `RELAY_50`, `RELAY_HIZ`,
  `RELAY_10K`.
- **Hierarchical labels OUT:** none. The output reaches the panel BNC via
  J2, which is a wired connection off-board.
- **Power:** `+5V`, `GND`.
- **Notes:**
  - **Three relay branches with identical coil/drive sides; contact side
    differs by mode.** Coil and drive are the same for K1, K2, K3:
    - Coil side: `+5V` -> COIL1; COIL2 -> Q.collector. D anode at COIL2,
      D cathode at `+5V` (flyback across the coil).
    - Drive side: Q.emitter -> GND; Q.base -> base resistor (1 k) ->
      hierarchical label `RELAY_50` / `RELAY_HIZ` / `RELAY_10K`.
    - Contact side, per branch:
      - K1 (50 ohm back-term): OPAMP_OUT -> K1.SW1; K1.SW2 -> R8 (50 ohm)
        -> J2 pin 1.
      - K2 (high-Z source): OPAMP_OUT -> K2.SW1; K2.SW2 -> J2 pin 1
        **directly, no series resistor**.
      - K3 (10 kohm bias): OPAMP_OUT -> K3.SW1; K3.SW2 -> R10 (10 k)
        -> J2 pin 1.
  - **J2 pin 2 -> GND.** This is the BNC shield wire-out.
  - **Firmware enforces one relay energized at a time.** No hardware
    interlock; trust the Pico SCPI parser.

### 7.5 Trigger (`Trigger.kicad_sch`)

- **Symbols:** J3 (1x3 pin header).
- **Hierarchical labels IN:** `SYNC_OUT` (from Pico, to drive J3 pin 1).
- **Hierarchical labels OUT:** `TRIG_IN` (J3 pin 3 back to Pico).
- **Power:** `GND` (J3 pin 2).
- **Notes:** Chassis trigger-bus connector standard is not yet defined.
  This is a placeholder 3-pin 0.1 inch header. Will likely need to be
  re-locked across modules (like the Phoenix) once the bus is specified.

---

## 8. Wire-up and finish

1. Place power flags inside each sheet for the rails it uses.
2. Place hierarchical labels per the contracts in section 7. Inside a
   sheet, every label with the same name is the same net; on the root,
   they become sheet pins.
3. **ERC** in eeschema (`Inspect - Electrical Rules Checker`). Expect
   warnings about unconnected Pico GPIO pins (place "no-connect" flags on
   intentionally unused ones). Real errors should be zero.
4. **Annotate** (`Tools - Annotate Schematic`).
5. **Update PCB from Schematic** (`Tools - Update PCB from Schematic`).
   The 53 components from the BOM should land on the board.
6. Assign netclasses to nets in pcbnew (`Net Inspector`).
7. Place per the floorplan (`library/module_pcb_floorplan.png`), route,
   pour the L2 ground plane and the L3 power pours per section 7 of the
   design package.
8. **DRC** in pcbnew, fix until clean.

## 9. Verification checklist before fab

- Title block populated on every sheet.
- All five CSE-fetched symbols have manufacturer P/N in the value field.
- AD9742 pin 23 left floating (no track, no GND stub).
- AD9742 pin 25 (MODE) hard-tied to GND.
- AD8056 channel B inputs terminated (+INB to GND, -INB to OUTB).
- Phoenix header pin order matches chassis harness (1=+5V, 2=+12V,
  3=-12V, 4=GND).
- Mounting hole positions match the v10 module-body STL (co-design check
  with the chassis fabrication tooling).
- ERC clean, DRC clean.
- 3D viewer shows no collisions between Pico USB connector and the rear
  PCB edge, or between the Phoenix header and the top-rear M2.5 mounting
  hardware.

When all of section 9 passes, the board is ready for fab quote (JLCPCB,
Oshpark, PCBWay, etc.).

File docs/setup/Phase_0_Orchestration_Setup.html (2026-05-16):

Width

# Phase 0 Orchestration Layer Setup

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

Architecture detail lives in the System Design Document and the Chassis Architecture and Power Distribution doc; this is both the architectural reference and the install / bring-up cookbook for the orchestration layer.

## Scope

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

Phase 0 verification milestone (per SDD §13.1):

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

## Architecture

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

### Two-plane architecture

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

### Software stack components

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

### Data flow

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

flowchart LR Test[pytest test
pmvb.fixtures] Mod[Module Pico 2 W
USB-TMC] Sim[pyvisa-sim
sim/] Influx[(InfluxDB 2.x
pmvb / measurements)] Graf[Grafana
Flux queries] Rep[pmvb.reports
Jinja2 + Matplotlib] Test -- SCPI MEAS:VOLT? --> Mod Test -- SCPI MEAS:VOLT? --> Sim Mod -- response --> Test Sim -- response --> Test Test -- write_measurement --> Influx Influx -- query --> Graf Influx -- query_run --> Rep

### pmvb Python package layout

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

sim/                               # PyVISA-sim YAML schemas (one per module)
└── placeholder/
    └── responses.yaml             # Phase 0 placeholder instrument

tests/                             # pytest tests
├── __init__.py
└── test_smoke.py                  # dependency import smoke tests

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

## Hardware Prerequisites

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

Orchestration host (capabilities, not specific parts):

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

Bench periphery:

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

## Workstation Prerequisites

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

## Section A. Raspberry Pi 5 OS install

The orchestration head runs Raspberry Pi OS Bookworm or newer.

### A.1 Generate an SSH key for the bench

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

ssh-keygen -t ed25519 -f $HOME\.ssh\pmvb-bench -C "pmvb-bench"

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

Host <YOUR_PI_HOSTNAME> <YOUR_PI_HOSTNAME>.local
    HostName <YOUR_PI_HOSTNAME>.local
    User <YOUR_PI_USERNAME>
    IdentityFile ~/.ssh/pmvb-bench
    IdentitiesOnly yes

Print the public key for the next step:

Get-Content $HOME\.ssh\pmvb-bench.pub

### A.2 Flash the SD card via Raspberry Pi Imager

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

Edit OS customization settings:

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

Write the image, eject the card, insert into the Pi 5, apply power.

### A.3 First boot and SSH verification

Give the Pi 60-90 seconds for first-boot init. Then from your workstation:

ssh <YOUR_PI_HOSTNAME>

Healthy: key-based auth succeeds without password prompt. Verify system state:

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

## Section B. NVMe boot migration

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

### B.1 EEPROM update

sudo rpi-eeprom-update -a
sudo reboot

After reboot, SSH back in and confirm:

sudo rpi-eeprom-update

Should report BOOTLOADER: up to date.

### B.2 Boot order set to NVMe-first

sudo raspi-config

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

### B.3 Clone SD root to NVMe

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

### B.4 Reboot and verify NVMe boot

sudo reboot

Wait 60-90 seconds, SSH back in:

df -h /
findmnt /
lsblk

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

## Section C. Remote access (optional)

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

## Section D. Python orchestration project

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

### D.1 Clone the repo

cd ~
git clone https://github.com/Pike1950/poor-mans-validation-bench.git pmvb
cd pmvb

### D.2 Create the virtual environment

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

### D.3 Verify with smoke tests

pytest tests/test_smoke.py -v

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

### D.4 Persist the venv activation

echo 'source ~/pmvb/.venv/bin/activate' >> ~/.bashrc

So that every new SSH session lands inside the venv.

## Section E. InfluxDB 2.x

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

### E.1 Add the InfluxData apt repo

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

### E.2 Install and enable InfluxDB

sudo apt install -y influxdb2 influxdb2-cli
sudo systemctl enable --now influxdb

Verify:

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

### E.3 Initial provisioning

influx setup \
  --username <YOUR_INFLUXDB_USERNAME> \
  --password '<STRONG_PASSWORD>' \
  --org pmvb \
  --bucket measurements \
  --retention 0 \
  --force

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

The setup command writes the active config to ~/.influxdbv2/configs, including the operator token.

### E.4 Token rotation and storage

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

NEW_TOKEN=$(python3 -c "import json; print(json.load(open('/tmp/new_auth.json'))['token'])")

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

influx config set -n default -t "$NEW_TOKEN"

Then delete the original operator token using its ID from influx auth list:

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

### E.5 Round-trip verification

TOKEN=$(cat /etc/pmvb/influx.token)

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

## Section F. Grafana

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

### F.1 Add the Grafana apt repo

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

### F.2 Install and enable Grafana

sudo apt install -y grafana
sudo systemctl daemon-reload
sudo systemctl enable --now grafana-server

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

Healthy: service is active (running), listening on :::3000, /login returns HTTP/1.1 200 OK.

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

### F.3 First login

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

### F.4 Add InfluxDB datasource

UI left sidebar -> Connections -> Data sources -> Add new data source -> InfluxDB. Fill in:

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

### F.5 Data-path verification

UI left sidebar -> Explore. Pick the pmvb-influx datasource. Paste the following Flux query:

from(bucket: "measurements")
  |> range(start: -1h)
  |> filter(fn: (r) => r._measurement == "phase0_test")

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

## Section G. Pico SDK and cross-compile toolchain

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

### G.1 Install the cross-compile toolchain

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

Roughly 500 MB after dependencies.

### G.2 Clone pico-sdk

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

Verify the SDK version and submodule state:

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

All submodules should be listed without a leading - (means initialized). Required: lib/tinyusb.

### G.3 Set environment variables persistently

echo 'export PICO_SDK_PATH=/opt/pico-sdk' >> ~/.bashrc
echo 'export PICO_BOARD=pico2_w' >> ~/.bashrc
source ~/.bashrc

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

### G.4 Verify cross-compile with hello_usb

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

## Section H. USB-TMC stub firmware

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

Files under firmware/pmvb_usbtmc_stub/:

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

Build the firmware:

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

After the sync and a few seconds for Picos to auto-reboot, verify the flash:

lsusb -d cafe:4001

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

## Section I. udev rules

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

Install:

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

Verify:

ls -la /dev/usbtmc*
ls -la /dev/usbtmc-by-serial/
groups | tr ' ' '\n' | grep plugdev

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

## Section J. Hot-plug verification

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

Procedure:

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

Edge cases:

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

## Section K. Phase 0 verification milestone

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

cd ~/pmvb
source .venv/bin/activate
pytest tests/test_phase0_e2e.py -v -s

### test_phase0_milestone (the historical Phase 0 close artifact)

Exercises the data path end-to-end against one sim instrument and one real Pico:

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

### test_pico_inventory_ping[Pico_<N>-<chip_id_prefix>] (parametric inventory exercise)

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

### test_pico_inventory_round_trip (cross-Pico round-trip summary)

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

### Healthy output

tests/test_phase0_e2e.py::test_phase0_milestone PASSED

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

### Running a subset

To skip the milestone and run only the inventory parametric exercise as a faster smoke check:

pytest tests/test_phase0_e2e.py::test_pico_inventory_ping tests/test_phase0_e2e.py::test_pico_inventory_round_trip -v

To re-run a single Pico (shell-quote the brackets):

pytest 'tests/test_phase0_e2e.py::test_pico_inventory_ping[Pico_5-B555F0C1]' -v

### When this passes

Phase 0 is officially complete and Phase 1 begins (Modules 1A, 1B, 1D, 1E per SDD §13.2). Each Phase 1 module re-uses the orchestration infrastructure built here: same pmvb.influx tag taxonomy, same Jinja2 report renderer, same MCP gateway, same Pico SDK toolchain, with each module’s firmware replacing the Phase 0 USB-TMC stub for that physical Pico.

## Troubleshooting

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

## Future Enhancements

The orchestration layer’s roadmap beyond Phase 0:

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

## References

- System Design Document – canonical architecture, module catalog, build phases
- Chassis Architecture and Power Distribution – chassis mechanical and electrical detail
- PMVB GitHub repository (https://github.com/Pike1950/poor-mans-validation-bench)
- Raspberry Pi OS documentation (https://www.raspberrypi.com/documentation/computers/os.html)
- Raspberry Pi M.2 HAT+ install guide (https://www.raspberrypi.com/documentation/accessories/m2-hat-plus.html)
- InfluxDB 2.x documentation (https://docs.influxdata.com/influxdb/v2/)
- Grafana documentation (https://grafana.com/docs/grafana/latest/)
- Pico SDK (https://github.com/raspberrypi/pico-sdk)
- Pico examples (https://github.com/raspberrypi/pico-examples)
- TinyUSB (https://github.com/hathach/tinyusb) – USB-TMC class implementation used by the stub firmware

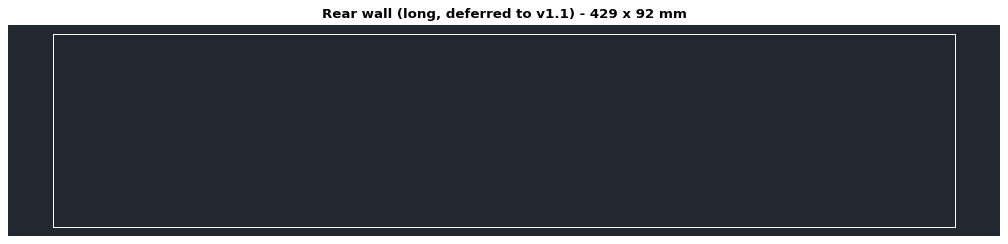
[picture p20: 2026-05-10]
tools/fabrication/out/panel_rear_wall_preview.png

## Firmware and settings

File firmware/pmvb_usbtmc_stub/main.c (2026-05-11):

/*
 * PMVB USB-TMC stub firmware - entry point.
 *
 * Phase 0 probe firmware that flashes onto a bare Pico 2 W and makes it
 * enumerate as a USB-TMC instrument with a chip-ID-derived serial number,
 * suitable for the SDD §10.1 hot-plug-by-serial verification milestone.
 *
 * Not a per-module SCPI parser. Real module firmware ships per-phase.
 */

#include "bsp/board_api.h"
#include "tusb.h"

extern void pmvb_usbtmc_init(void);
extern void pmvb_usbtmc_task_iter(void);

int main(void) {
    board_init();
    pmvb_usbtmc_init();

    tusb_rhport_init_t dev_init = {
        .role = TUSB_ROLE_DEVICE,
        .speed = TUSB_SPEED_AUTO,
    };
    tusb_init(BOARD_TUD_RHPORT, &dev_init);

    if (board_init_after_tusb) {
        board_init_after_tusb();
    }

    while (true) {
        tud_task();              // TinyUSB device task
        pmvb_usbtmc_task_iter(); // handles deferred BOOTSEL reset
    }
}

/* ---------- USB device-level callbacks ----------
 * These are required by TinyUSB but we have no LED to blink and no state to
 * track at this layer. Kept as no-ops. */

void tud_mount_cb(void)    { }
void tud_umount_cb(void)   { }
void tud_suspend_cb(bool remote_wakeup_en) { (void) remote_wakeup_en; }
void tud_resume_cb(void)   { }

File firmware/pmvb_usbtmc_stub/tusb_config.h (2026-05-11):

/*
 * TinyUSB configuration for the PMVB USB-TMC stub firmware.
 *
 * Phase 0 probe firmware: one USB-TMC interface with USB488 subclass for
 * SCPI-compliant behavior. No CDC / MSC / HID / etc. The interrupt endpoint
 * is enabled so the host can poll for service requests.
 */

#ifndef TUSB_CONFIG_H_
#define TUSB_CONFIG_H_

#ifdef __cplusplus
extern "C" {
#endif

#ifndef BOARD_TUD_RHPORT
#define BOARD_TUD_RHPORT      0
#endif

#ifndef BOARD_TUD_MAX_SPEED
#define BOARD_TUD_MAX_SPEED   OPT_MODE_DEFAULT_SPEED
#endif

// CFG_TUSB_MCU is provided by the Pico SDK's CMake glue based on PICO_PLATFORM.
#ifndef CFG_TUSB_MCU
#error CFG_TUSB_MCU must be defined (Pico SDK should provide this; check CMake setup)
#endif

#ifndef CFG_TUSB_OS
#define CFG_TUSB_OS           OPT_OS_PICO
#endif

#ifndef CFG_TUSB_DEBUG
#define CFG_TUSB_DEBUG        0
#endif

// Enable device stack
#define CFG_TUD_ENABLED       1
#define CFG_TUD_MAX_SPEED     BOARD_TUD_MAX_SPEED

#ifndef CFG_TUSB_MEM_SECTION
#define CFG_TUSB_MEM_SECTION
#endif

#ifndef CFG_TUSB_MEM_ALIGN
#define CFG_TUSB_MEM_ALIGN    __attribute__ ((aligned(4)))
#endif

#ifndef CFG_TUD_ENDPOINT0_SIZE
#define CFG_TUD_ENDPOINT0_SIZE    64
#endif

// USB-TMC class config (USB488 subclass = SCPI-compliant)
#define CFG_TUD_USBTMC                1
#define CFG_TUD_USBTMC_ENABLE_INT_EP  1
#define CFG_TUD_USBTMC_ENABLE_488     1

#ifdef __cplusplus
}
#endif

#endif /* TUSB_CONFIG_H_ */

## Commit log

2026-05-03 Tier 1 enhancements: Module 1H DMM, block diagrams, NI references, sample tests, timing diagrams; coverage gaps note
2026-05-03 Tier 2 and Tier 3 enhancements: block diagrams, NI references, sample tests, timing diagrams
2026-05-03 Fix WaveDrom widths and 2C Mermaid; add state diagrams, power tree, Firestick recipe, pinout tables
2026-05-03 Update chassis power architecture to Silverstone TX300 PSU with internal DC distribution
2026-05-04 Add Phase 0 setup, Module 1E design doc, Chassis Power Distribution design; update SDD for Pi 5 16 GB baseline; refresh INSTRUCTIONS
2026-05-04 Add Module 1E design doc, Chassis Power Distribution design; update SDD for Pi 5 16 GB baseline; refresh INSTRUCTIONS; expand README with new doc links; gitignore docs/setup/
2026-05-04 Render Module 1E and Chassis Power Distribution docs as HTML; update README links to GitHub Pages URLs
2026-05-06 Adopt Path A: remove per-module Pi Zero from v1.0 baseline and cascade through SDD, README, chassis doc, and Module 1E doc
2026-05-06 Drop chassis LAN switch from v1.0 baseline (move to Phase 4); gitignore Reference Photos/
2026-05-06 Add TikZ figure infrastructure + Module 1E worked examples; embed legend in SDD section 4
    - pmvb-figures.sty: house style sheet (FMCW dark palette, node + edge styles
    for subsystems / ICs / internal blocks / connectors, edge styles per signal
    type, helper macros)
    - BUILD.md: build instructions (MiKTeX, Poppler, build pipeline)
    - build-all.ps1: PowerShell helper to render every .tex under docs/figures/
    - STYLE_GUIDE.md: full style guide covering scope, color palette, node and
    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
2026-05-06 Strip 'Path A' framing and discarded-alternative language across SDD, README, chassis doc, Module 1E doc
2026-05-07 Module 1E v1.1 redesign: AD9742 + AD8056 (Option A, 10 MHz target); update SDD Pi 5 price to (Microcenter); replace 1E figures (system context, AD9742 datasheet embed, typical app schematic)
2026-05-07 Update SDD section 7.5.5 to v1.1, refine Figure 4-1, add Module Doc schema
    - SDD section 7.5.5: rewrite intro prose, Mermaid block diagram, Table 7-27
    specifications, commercial-equivalent comparison, sweep timing diagram, and
    Table 7-28 BOM to match Module 1E v1.1 (AD9742 + AD8056, 50 / 600 / 10k
    output impedance, DC to 10 MHz). Cascade Phase 1 BOM line ($18 -> $53),
    Phase 1 total ($63 -> $98), v1.0 + v1.1 subtotal ($984 -> $1,019), and
    all-phases total ($1,371 -> $1,406) in section 13. Add Module 1E to the
    verified-line-item footnote alongside the Pi 5.
    - Figure 4-1: fix VISA/SCPI plane band text clipping (band height 14 -> 16 mm,
    explicit anchor=north / anchor=south on head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
2026-05-07 Round 1 doc audit: USB 3.0 labels, deprecate chassis power doc, update Phase 0 BOM
2026-05-07 Add v2.0 Chassis Architecture and Power Distribution doc; gitignore docs/templates/
    - New docs/chassis/Chassis_Architecture_and_Power_Distribution.md and .html
    describing the acrylic blade chassis (420x238x90mm, 14 module slots at
    22.5mm pitch, TX300 backbone with GeeekPi-on-top, Sabrent USB hub,
    4-rail back-wall harness, Phoenix MC 1,5/4 module interconnect).
    - Module form factor: 16.5x125x86mm body with C-shape cross-section,
    open left face, 14.5mm cavity, 21.5mm component-stack budget.
    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
2026-05-07 Replace deprecated chassis power doc with v2.0 Chassis Architecture and Power Distribution
    - Delete docs/chassis/Chassis_Power_Distribution_Design.{md,html} entirely;
    the v2.0 Chassis Architecture and Power Distribution doc fully supersedes it.
    - New chassis doc covers acrylic blade chassis (420x238x90mm, 14 module slots
    at 22.5mm pitch, TX300 analog backbone with GeeekPi-on-top, Sabrent USB hub,
    4-rail back-wall harness, Phoenix MC 1,5/4 module interconnect, top vent grid).
    - Module form factor: 16.5x125x86mm body with C-shape cross-section, 14.5mm
    cavity, 21.5mm component-stack budget, PCB-against-right-wall mount convention.
    - Front-panel module-faceplate cutouts deferred until mo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
2026-05-07 Embed Tinkercad photos in chassis arch doc; fix Mermaid; update SDD power tree
    - Add 7 chassis/module photos to docs/figures/chassis/photos/, with
    6 of them embedded as figures in the chassis architecture doc:
    - Figure 1 (hero): populated chassis
    - Figure 2 (3.1): empty chassis structure
    - Figure 3 (3.3): TX300 + GeeekPi cutaway
    - Figure 4 (3.4): GeeekPi-on-TX300 with modules
    - Figure 5 (3.6): module C-shape side profile
    - Figure 6 (4.4): back-wall harness wires
    - Fix Mermaid block rendering: post-process pandoc output from
    <pre class='mermaid'><code> to <div class='mermaid'>.
    - Add docs/chassis/build-html.ps1 for re-rendering with Mermaid fix.
    - Correct TX300 IEC inlet orien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
2026-05-07 Add TikZ chassis block diagram, embed photos, fix Mermaid render, update SDD power tree
    - Port chassis functional block diagram from Mermaid to TikZ
    (docs/figures/chassis/chassis_block_diagram.tex), using
    pmvb-figures.sty for visual consistency with Module 1E figures
    and Figure 4-1.
    - Embed 7 chassis/module Tinkercad photos as figures 1-6 in the
    chassis architecture doc with explicit per-image sizing.
    - Correct TX300 IEC inlet orientation (front-panel cutout).
    - Remove v2.0/deprecated framing from chassis arch doc.
    - Update SDD section 11.5 Power Architecture: redraw Figure 11-1
    power tree (3 AC plugs: TX300, Pi 5 charger, Sabrent hub brick;
    TX300 supplies analog rails only).
    - D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
2026-05-07 Add TikZ chassis block diagram with analog/digital split, embed photos, update SDD power tree
    - Port chassis functional block diagram from Mermaid to TikZ; split
    module bay into Analog (x8: 1B/1D/1E/1F/1G/1H/2B/2E, amber border)
    and Digital (x5: 1A/1C/2A/2C/2D, blue border) groups, mirroring
    the SDD section 11.5 power tree. Harness terminates only at the
    analog group; USB-A bus fans out to both groups.
    - Renumber chassis arch doc figures 1-7 in reading order with the
    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
2026-05-07 Add PROJECT_TRACKER.md: phase-organized fine-grained task list
    Top-level structure mirrors SDD section 13 build phases (Phase 0 through
    Phase 4 + Cross-Cutting). Within each phase, tasks grouped by area:
    hardware sourcing, mechanical fabrication, assembly, firmware, software,
    verification, documentation. Each module gets its own subsection within
    its phase with a standardized 13-15 subtask breakdown (design doc, BOM,
    PCB schematic + layout + fab, assembly, firmware YAML + parser, bring-up,
    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
2026-05-07 Embed coarse project status in README front page
    Replaces the link-only 'Project status' section with an inline phase
    status table, current-focus summary, and recently-landed milestone
    list. Granular per-task tracker at PROJECT_TRACKER.md remains for
    fine-grained progress; README is the front-page snapshot.
2026-05-07 Check off completed tasks for Raspberry Pi 5 hardware
    Updated the status of hardware orders and assembly for the Raspberry Pi 5.
2026-05-07 Condense PROJECT_TRACKER per-module checklists and sourcing groups
    Collapse per-module 25-item checklists (14 module + 11 schema subitems)
    to ~1-2 lines each using a dotted-list compact format with a standard
    template introduced once at the top. Group sourcing kits (Phoenix MC,
    fuse hardware, hookup wire, Pi 5 accessories). Tighten software stack
    into grouped install lines. Phase verification milestones simplified
    to 1-2 lines each. Total length roughly halved (~230 -> ~135 lines)
    without losing meaningful granularity.
2026-05-08 Module v9: shrink rail lip 1.0 mm to 0.6 mm for sliding clearance
    Module body envelope updated 16.5 to 16.3 mm wide. Right wall thickness
    goes 1.0 to 1.2 mm; rail lip width goes 1.0 to 0.6 mm. Chassis grooves
    remain cut at 1 mm wide x 3 mm deep using the original v8 module shape;
    the 0.4 mm width difference between groove and lip gives sliding
    clearance to accommodate acrylic laser-cut tolerance variation.
    Internal cavity (14.5 x 125 x 70 mm) and component-stack budget (21.5
    mm) are unchanged.
    Updated: chassis arch doc section 3.2 / 3.6 / Figure 6 caption,
    re-rendered HTML.
2026-05-08 Untrack local-only build scripts and figure-pipeline docs
    Per project policy: PowerShell build scripts and figure-author documentation
    are local tooling, not deliverable content. Files removed from git tracking
    but retained locally:
    - docs/figures/build-all.ps1 (figure batch build helper)
    - docs/chassis/build-html.ps1 (chassis arch HTML render helper)
    - docs/figures/STYLE_GUIDE.md (FMCW style conventions for figure authors)
    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
2026-05-10 Chassis v1.0 open-frame + module v10 geometry; prototype ordered
    [chassis_assembly_exploded.stl, chassis_v10.stl, module_body_v10.stl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]
2026-05-10 Chassis assembled STL: single connected manifold via boolean union
    [chassis_v10_assembled.stl]
2026-05-10 Chassis 435x238x92 envelope; GeeekPi ceiling mount via M2.5; Wago harness taps; notched groove DXFs
    [Brilliant_Tumelo.stl, Neat_Trug.stl, PMVB_Chassis_populated.stl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]
2026-05-10 Remove scratch Tinkercad export files from tools/fabrication
    [Brilliant_Tumelo.stl, Neat_Trug.stl, PMVB_Chassis_populated.stl]
2026-05-10 Phase 0 tracker: GeeekPi ceiling mount, Wago harness taps, M2.5 hardware, SendCutSend acrylic ordered (invoice SL094002, .57)
2026-05-10 Phase 0 tracker: consolidate fabrication+assembly section, GeeekPi/Wago/M2.5/SendCutSend updates, Sabrent on hand; expand modules to nested sub-checkboxes; restore Cross-Cutting section
2026-05-10 Switch chassis hardware to assortment-kit standoffs (HVAZI M3 B01L06CUJG + Csdtylh M2.5 B06Y5TJXY1): 4-high stacks of 20mm M-F+F-F per corner with Loctite 243 on internal joints; M2.5 5mm -> 6mm (kit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
2026-05-10 Chassis sourcing + wire gauge rationale: slim README BOM to part+source+qty+price; add pre-fuse (12 AWG) and post-fuse (14 AWG) gauge rationale to chassis arch doc §4.2/§4.4; replace Mouser Alpha 305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
2026-05-10 Pandoc re-render of chassis arch doc (fixes duplicated 7.1/7.2 block, restores full 7-9 content); update chassis photos from current STL (open-frame v1.0 envelope, TX300/GeeekPi/Sabrent/module placeh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
2026-05-11 Phase 0 Orchestration Layer Setup doc: replaces stale 2024-era version with architecture + bring-up sections (two-plane architecture, software stack components, data flow diagram, pmvb package layout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
2026-05-11 tools/hot_plug_verify.py: fix resource-string regex to match both pyvisa-py format variants (hex-with-0x and decimal-no-prefix-with-interface); compare VID/PID as integers so 0xCAFE/0x4001 matches wh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
    [hot_plug_verify.py]
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2026-05-11 Phase 0 closure: tests/test_phase0_e2e.py passing end-to-end (sim + real Pico over USB-TMC -> InfluxDB -> Jinja2 report); sim/placeholder/responses.yaml EOM fix (CRLF to match pyvisa default USB INST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
2026-05-14 tools/hot_plug_verify.py: revert SABRENT_SLOT_MAP to simple monotonic depth-first mapping. The earlier 'empirical' remap was derived from misinterpreting an earlier comment about reversed slot orderi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
    [hot_plug_verify.py]
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2026-05-25 Fix USB cable refs in chassis doc (Pico 2 W is micro-USB, not USB-C); Phase 0 tracker: slide-fit validated, frame assembly + TX300 install done; correct USB cable BOM; build notes record GeeekPi hole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
2026-06-08 docs(1E): Module 1E design doc v1.2; fix AD9742 pinout in section 4 against datasheet Rev. C Table 6 (pins 13-28 were scrambled, pin 23 RESERVED now flagged, MODE corrected from 'parallel mode' to da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
2026-06-08 docs(SDD): sync Module 1E section 7.5.5 with design doc v1.2; output impedance switch 50 Ω / 600 Ω / 10 kΩ -> 50 Ω / high-Z / 10 kΩ across prose, block diagram, spec table, and BOM note; commercial-e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
2026-06-08 docs(1E): rework Figure 1E-1 as AWG functional architecture; replace chassis-context view with textbook AWG block diagram (sample clock generator -> address generator -> waveform memory -> DAC -> rec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
2026-06-08 docs(1E): rework Figure 1E-1 as AWG functional architecture; replace chassis-context view with textbook AWG block diagram (sample clock generator -> address generator -> waveform memory -> DAC -> rec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
2026-06-08 fix(fig-1e-1): route CLK from sample clock generator to address generator
    Per textbook AWG architecture, the sample clock drives the address
    generator (which steps through waveform memory at each tick), not the
    DAC directly. The DAC's CLOCK pin still receives the same physical
    signal in hardware, but the architectural diagram now follows the
    convention seen in Tektronix/Keysight references.
    - Moved Sample clock generator block from above DAC (x=9.4) to above
    Address generator (x=1.6).
    - Re-routed CLK arrow from clk.south to addr.north (was dac.north).
    - Moved Ext. 10 MHz ref label above the clock generator (enters from
    top instead of left side, which is now occupied by Trigger IN).
2026-06-08 docs(1e): reconcile section 1 prose with corrected Figure 1E-1 routing
    Bump to v1.5. The figure was fixed in the previous commit to show the
    sample clock generator driving the address generator (textbook AWG
    convention), but sections 1.1 and 1.2 still described the clock as
    driving the DAC's CLOCK pin. That was a framing inconsistency, not a
    hardware change: the same physical PIO clock wire reaches both the
    address-generator advancement and the DAC's CLOCK pin in our
    implementation.
    - Section 1.1 paragraph under Figure 1E-1: reframed clock as driving
    the address generator, with explicit note that the same clock wire
    physically reaches the DAC's CLOCK pin so readers don't think we
    adde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
2026-06-08 fix(1e): correct AD9742 segmentation in Figure 1E-2 and section 1.4
    Brad caught that Figure 1E-2 and section 1.4 prose described the AD9742
    internal architecture as 2-tier segmented (top 9 bits unary, bottom 3
    binary) when the datasheet actually describes 3-tier:
    - 5 MSBs (bits 11-7): 31 unary-decoded segments at I_FS/32 each
    - 4 middle bits (6-3): 15 unary sub-segments at 1/16 of an MSB
    - 3 LSBs (2-0): binary-weighted fractions of a middle segment
    - 49 nominal current sources total
    Figure 1E-2 (1e_dac_current_mode.tex): rewrote the three muted
    descriptor lines inside the segmented-current-source-array box,
    bumped box height from 18mm to 22mm for breathing room.
    Section 1.4 of the design d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
2026-06-08 fix(fig-1e-2): descriptor lines use explicit coarse/medium/fine names
    Previous version used undefined back-references ('each MSB step', 'each
    middle step') that made lines 2 and 3 hard to parse without rereading
    line 1. Replaced with named tier-labels so each line is self-contained:
    - coarse (625 µA each) for the 5 MSBs
    - medium (39 µA each) for the 4 middle bits, refined 16x from coarse
    - fine (4.9 µA each = LSB) for the 3 LSBs, refined 8x from medium
    The subdivision chain (32 x 16 x 8 = 4096 = 12-bit resolution) is now
    implicit in the explicit refinement language.
2026-06-09 docs(1e): add NCO walkthrough + Figure 1E-2 phase accumulator in section 1.3
    Section 1.3 previously had one short paragraph mentioning a 'phase
    accumulator running in Pico firmware on the second core' without
    explaining what an NCO is, where the accumulator lives, or how the
    FTW math works. Expanded into a proper Numerically Controlled
    Oscillator walkthrough:
    - Three-component breakdown (phase accumulator, waveform LUT,
    PIO + DMA -> DAC chain) with bit widths and the role each component
    plays.
    - Textbook DDS figure (FTW register -> adder -> phase register with
    32-bit feedback bus, clocked by f_CLK, top 10 bits address the LUT).
    Trapezoidal adder with chevron notch matches the AD DDS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
2026-06-11 docs(1e): reconcile op-amp gain network to 20k / gain 20; bump v1.6
    Sections 4 (Schematic Notes) and 5 (Pin Assignments) still specified the
    AD8056 difference-amp feedback and reference resistors as 10k for a gain
    of 10, contradicting section 1.6 and the section 6 spec table, which call
    for gain 20 and a +/-10 V output. With R_in = 1k and the 1 Vpp differential
    filter output, +/-10 V requires R_fb = R_ref = 20k; 10k only reaches +/-5 V.
    - Section 4: R_fb / R_ref 10k -> 20k, gain 10 -> 20, and rewrote the
    self-contradicting summary sentence (claimed gain 10, then 'for +/-10 V
    output the gain is 20') into one correct statement.
    - Section 5: AD8056 pin table R_fb / R_ref 10k -> 20k.
    - Sect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
2026-06-11 docs(1e): resolve D2 filter synthesis + D6 Phoenix P/N; design doc v1.7
    D2: 25 ohm DAC termination into the op-amp's ~1 kohm input is a 40:1 ratio
    that rules out a doubly-terminated Butterworth (6-11 dB ripple). Synthesized
    each leg singly-terminated: series 0.22/0.68/0.22 uH, shunt 820 pF. Verified
    -3 dB ~11 MHz, image rejection ~51 dB @ 40 MHz / ~26 dB @ 20 MHz; ~1.5 dB
    passband droop to 10 MHz handled by the section 9.4 calibration. Rejected the
    25 ohm-shunt/gain-40 alt (drops AD8056 BW to ~7.5 MHz, below band).
    D6: confirmed Phoenix 1803293 (MC 1,5/4-G-3,81) IS the right-angle header
    ('angled 90 deg', per TME/Digi-Key); the straight one is MCV 1803442. 1803293
    is already the chassis BOM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
2026-06-11 docs(1e): +3.3V from chassis Phoenix (5-pin), rear-edge blind-mate; doc v1.9
    Power: DAC +3.3V (AVDD/DVDD) now from the chassis ATX rail via the GeeekPi
    breakout on Phoenix pin 5, not the Pico 3V3_OUT (now unconnected). Decouples
    the DAC analog supply from the Pico's switching regulator; FB1/FB2 unchanged.
    Connector: 4-pin -> 5-pin MC 1,5/5-G-3,81 (1803303, Digi-Key 277-1209-ND;
    plug MC 1,5/5-ST-3,81 / 1803604), relocated from top-edge drop-down to the
    rear edge beside the USB for rearward blind-mate on insertion. Right-angle
    unchanged. Pin order 1-5 = +5V, +12V, -12V, GND, +3.3V.
    Propagated: PCB package (power table, interface spec, D3/D6, D1-D7 marked
    resolved, status, v0.4->v0.5); module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
2026-06-12 hardware(1e): scaffold KiCad project tree + library + gitignore
    Repo-side scaffolding so the KiCad project can be created in the GUI per the
    build guide (the .kicad_pro/.sch/.pcb are authored in KiCad, not by hand):
    - hardware/modules/1E/kicad/lib/PMVB_1E/{symbols,footprints.pretty,3dmodels}/
    with .gitkeep, ready for the five CSE parts.
    - kicad/README.md: build order + a quick-reference card of the values easy to
    get wrong during capture (5-pin J1 pinout, +3.3V source, AD9742 pin 23/25,
    gain network, filter L/C, relays, netclasses).
    - .gitignore: KiCad section (ignore backups/autosave/cache/lock/.kicad_prl;
    keep source + lib). Fixed the broad Python lib/ rule that was swallowing
    e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
